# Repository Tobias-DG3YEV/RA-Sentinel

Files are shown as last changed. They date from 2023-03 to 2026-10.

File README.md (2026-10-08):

# Project RA-Sentinel - a Radio Access Sentinel
FPGA-based Radio Receiver for securing WiFi and other access points against hacking attacks.

RA-Sentinel is an open-source project focused on creating a cost-effective, small, and low-power wideband radio receiver device that employs an FPGA to automatically detect malicious attacks on WiFi access points, such as Man in the Middle and Denial of Service attacks. By monitoring any WiFi cell, the device enhances internet safety for everyday users.
The device features low-cost receive-only chips that digitize 40 MHz of the WiFi radio spectrum at 2.4 GHz. An FPGA extracts relevant properties from demodulated and decoded packets in real-time without storage. These properties are then processed by a neural network, also implemented on the FPGA, to determine if the traffic is genuine or an attack.

The project was later extended with a directional 4-channel RF front end (RASRF2400WBMC) that adds Angle of Arrival (AoA) estimation, see the Sub Projects section below.

## Funding
<p align="center">
  <a href="https://nlnet.nl/entrust/">NGI0 Entrust</a>
  &nbsp;&nbsp;
  <a href="https://nlnet.nl/project/RA-Sentinel/">NLnet</a>
</p>

**RA-Sentinel (main project)**

This project was funded through the [NGI0 Entrust](https://nlnet.nl/entrust) Fund, a fund established by [NLnet](https://nlnet.nl/) with financial support from the European Commission's [Next Generation Internet](https://ngi.eu/) programme, under the aegis of [DG Communications Networks, Content and Technology](https://commission.europa.eu/about-european-commission/departments-and-executive-agencies/communications-networks-content-and-technology_en) under grant agreement No 101069594.

**RASRF2400WBMC (directional / AoA extension)**

This sub-project was funded through the [NGI0 Commons Fund](https://nlnet.nl/commonsfund), a fund established by [NLnet](https://nlnet.nl/) with financial support from the European Commission's [Next Generation Internet](https://ngi.eu/) programme, under the aegis of [DG Communications Networks, Content and Technology](https://commission.europa.eu/about-european-commission/departments-and-executive-agencies/communications-networks-content-and-technology_en) under grant agreement No [101135429](https://cordis.europa.eu/project/id/101135429). Additional funding is made available by the [Swiss State Secretariat for Education, Research and Innovation](https://www.sbfi.admin.ch/sbfi/en/home.html) (SERI).

---

## Latest Updates 

| Date | Change | Link |
| --- | --- | --- |
| 2026-10-08 | Four-channel receiver: angle-of-arrival polar display, real-time phase comparison, IQ snapshot capture to a PC over gigabit Ethernet. FPGA1 now free of Xilinx IP (openCMUL, openCDIV, openFFT) | [/Documentation/iq_capture](./Documentation/iq_capture/README.md) |
| 2026-09-30 | RASBB Revision C manufacturing started | |
| 2026-07-24 | RASPMO - 4ch Spectrum Monitor/Phase analysis | [/RASPMO](./RASPMO) |
| 2026-06-30 | RASANT2400 - 2.4 GHz antenna for RF front ends | [/RASANT2400](./RASANT2400) |
| 2026-04-15 | RASRF2400WBMC - directional 4-channel RF front end for Angle-of-Arrival estimation | [/RASRF2400WBMC](./RASRF2400WBMC/README.md) |
| 2025-12-15 | RASBB_ECU firmware - adds UPNP discovery over Ethernet and a system configuration web page | [/RASBB/Software/RASBB_ECU](./RASBB/Software/RASBB_ECU) |
| 2025-02-23 | First boards of RASBB and RASRF2400WB received; bring-up ongoing | [RASBB README](./RASBB/README.md) &nbsp;\|&nbsp; [Findings Rev A](./RASBB/Findings_RevA.md) |

---

## System Architecture

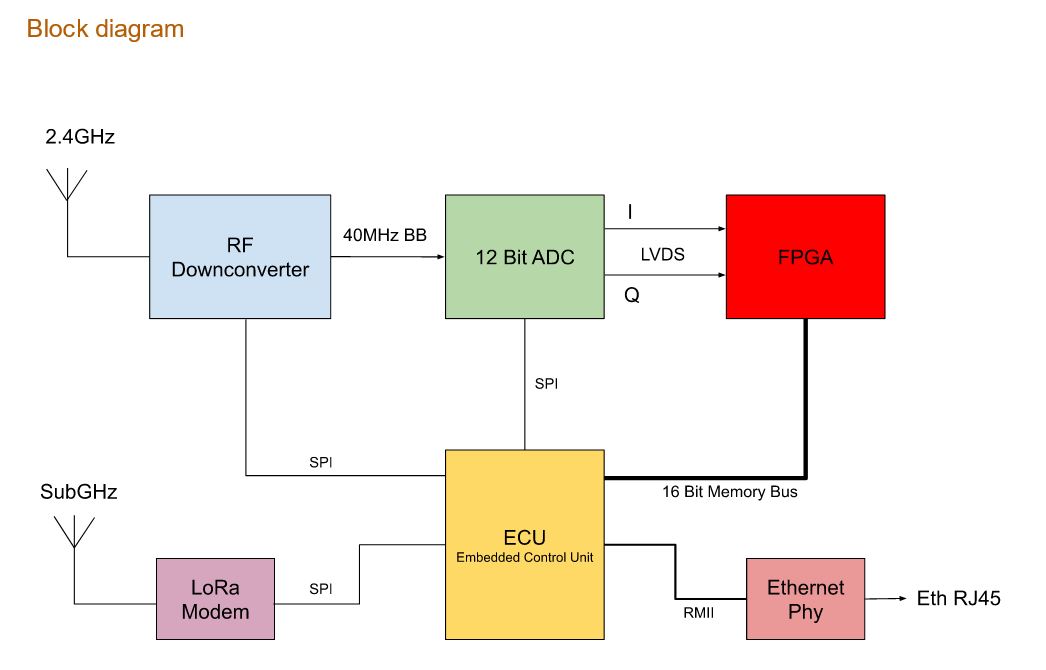
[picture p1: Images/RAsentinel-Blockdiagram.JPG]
RA-Sentinel Block Diagram


---
## Hardware

The hardware is a wideband SDR receiver that receives at least one complete WiFi Channel on the 2.4GHz ISM band with high resolution (12 Bits) to be able to detect smallest anomalies in a transmitted signal. The initial evaluation hardware consists of a Downcoverter/Transceiver Chip for 2.4GHz which is widely used in older WiFi Access Points (MAX2831). This is followed by a 12 Bit ADC (Texas Instruments ADC3222) which converts a 40MHz window of the 2.4GHZ radio spectrum into a 4 x 240 Bit/s LVDS streams (960kBit/s total) into a XILNIX/AMD Artix7 FPGA sitting on a evaluation board made by QMTECH. 

Based on the experience collected with first prototype, we designed a new SDR prototype. Two boards of the RASBB and the RASRF2400 have arrived on 23rd. Feb. 2025
Testing and bringing up is now ongoing. First results and findings can be found in the corresponding [Findings_RevA.md](./RASBB/Findings_RevA.md) documents.

### Boards

| Board | Description | Location |
|---|---|---|
| **RFFE2400WB** | 2.4 GHz PMOD-connected RF front-end evaluation board (used with QM-Tech Artix-7) | [/RFFE2400WB](./RFFE2400WB) |
| **RASBB** | Base-band board with STM32 ECU, web config, Ethernet/UPNP | [/RASBB](./RASBB) |
| **RASRF2400WB** | Wideband 2.4 GHz RF front end (production variant) | [/RASRF2400WB](./RASRF2400WB) |
| **RASRF2400WBMC** | Directional 4-channel phase-coherent front end (AoA) - *new sub-project* | [/RASRF2400WBMC](./RASRF2400WBMC) |
| **RASANT2400** | 2.4 GHz antenna for RF front ends| [/RASANT2400](./RASANT2400) |

First RA-Sentinel prototype with QM-Tech board
*Picture 1: First RA-Sentinel prototype based on the QM-Tech Artix-7 board and a newly designed RF front end connected via PMOD.*

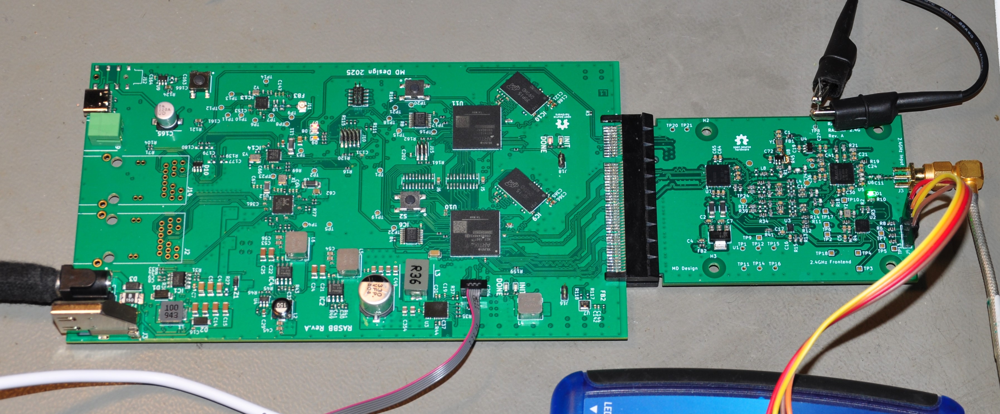
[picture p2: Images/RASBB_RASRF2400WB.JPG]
RA-Sentinel prototype Revision A

*Picture 2: RA-Sentinel prototype Revision A with RF front-end board RASRF2400WB.*

FPGA development board reference: <https://de.aliexpress.com/item/1005006473783593.html>

---

## Software / Firmware

The vast majority of the code will be written in Verilog and run on the FPGA. There is also now a firmware for the RASBB_ECU (Embedded Control Unit) and a"house keeping unit" microcontroller (STM32C031) which programms and controlling the frontend chips. The RASBB_ECU provides the interconnectivity. with other systems (alarm forwarding) and the web configuration interface. This firmware is written in C. 

The firmware for the RASBB_ECU can be found The firmware for the RASBB_ECU can be found [here](./RASBB/Software/RASBB_ECU). 

The RASBB_ECU Firmware for the onboard STM32 provides a versatile configuration interface with GUI that allows to show statistics and maybe UDP for analytic packets transfer and secure TCP/IP configuration over Ethernet.
To access this, enter the IP of the RAS into your local browser like http://192.168.0.2:4842/. The IP can be easily found via network environment because the RAS supports UPNP over ethernet.

All original software/firmware code written for this project is licensed under the GNU General Public License 3.0 (Only).

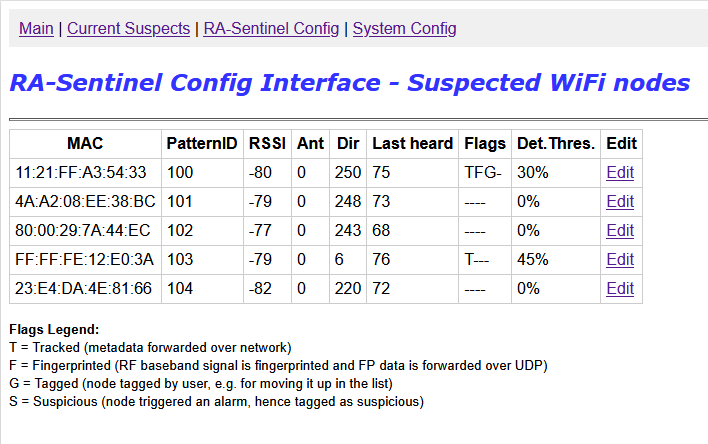
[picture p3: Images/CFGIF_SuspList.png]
WebInterface screenshot


A suspected WiFi node can be

* Tracked: Monitored by relative signal strength and later with additional direction. These values are forwarded to an IDS host that can combine this information with additional data retrieved from different RAS or other network monitoring systems.
* Tagged: Marked for internal memory, moving up in watch list.
* Fingerprinted: Raw IQ data of the frame start is forwarded to a fingerprinting algorithm.

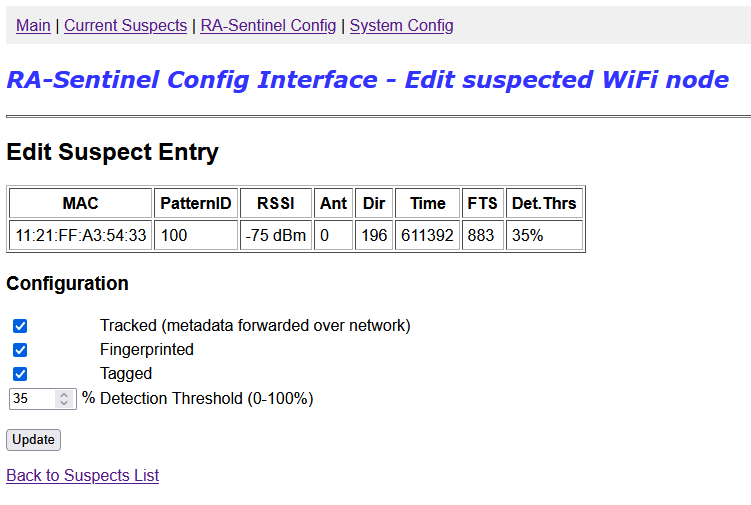
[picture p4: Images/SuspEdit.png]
Suspect Edit Screenshot


**UPNP support**

To ease the installation process, the RAS can be connected to any ethernet based LAN that provides an IPv4 DHCP server. Through the UPNP support, the RAS is easy to find in any network browser of Windows, Linux and Mac etc. 
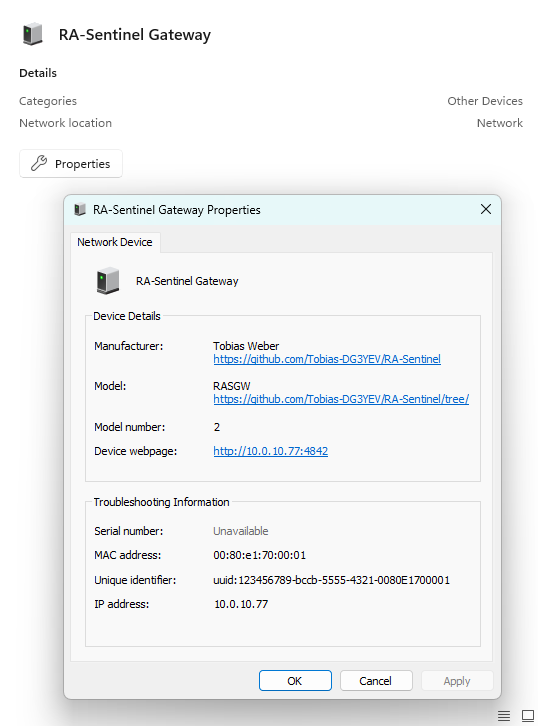
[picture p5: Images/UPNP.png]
UPNP Screenshot


---

## Sub Projects / Project Steps

The first step on this project was to have a reliable hardware basis. Initially I planned to have at least 40 Megasamples and with this 20 MHz bandwidth which is sufficient to capture the headers and the most common bandwidths used on 2.4 GHz WiFi (802.11a, b, g) communications channel. But because 802.11n also defines the possibility to use 40 MHz bandwidth, I wanted the possibility to cover the complete possible channel bandwidth. This has been achieved with the first prototype hardware and proved with the sub-project RASM2400, Radio Access Spectrum Monitor for 2400 MHz. The directional variant, RASRF2400WBMC, extends this base with multi-channel phase-coherent reception so the same signal can be received across several antennas and the direction of an attack can be estimated. You can find all sub-project details below.

### Sub project: RASRF2400WBMC - Directional RF Front End

The **RASRF2400WBMC** is a 4-channel, phase-coherent 2.4 GHz RF front-end board that extends RA-Sentinel with **Angle of Arrival (AoA)** estimation. By receiving the same signal across four spatially separated antennas, the system can estimate the physical direction of a detected attack - enabling threat localization for jamming, spoofing, and unauthorized events.

The board connects to the existing RASBB via the PCIe connector and requires no hardware changes to the base-band board.

See **[RASRF2400WBMC/README.md](./RASRF2400WBMC/README.md)** for full details.

### Sub project: RASM2400 - a spectrum monitor

RASM2400 stands for Radio Access Spectrum Monitor operationg on 2400MHZ. It offers a visual spectrum analyzer design that runs on the evaluation hardware set of RA-Sentinel the Artix7 XC7A100T Wukong board and the RFFE2400 front end board.
It shall proove that a 40MHz wide radio spectrum can be received and transported into the FPGA. Further, this project may already be usable for first RF forensics. Feel free to download all the stuff and build an RASM by yourself.

The following diagram shows the system architecture of the RASM2400.

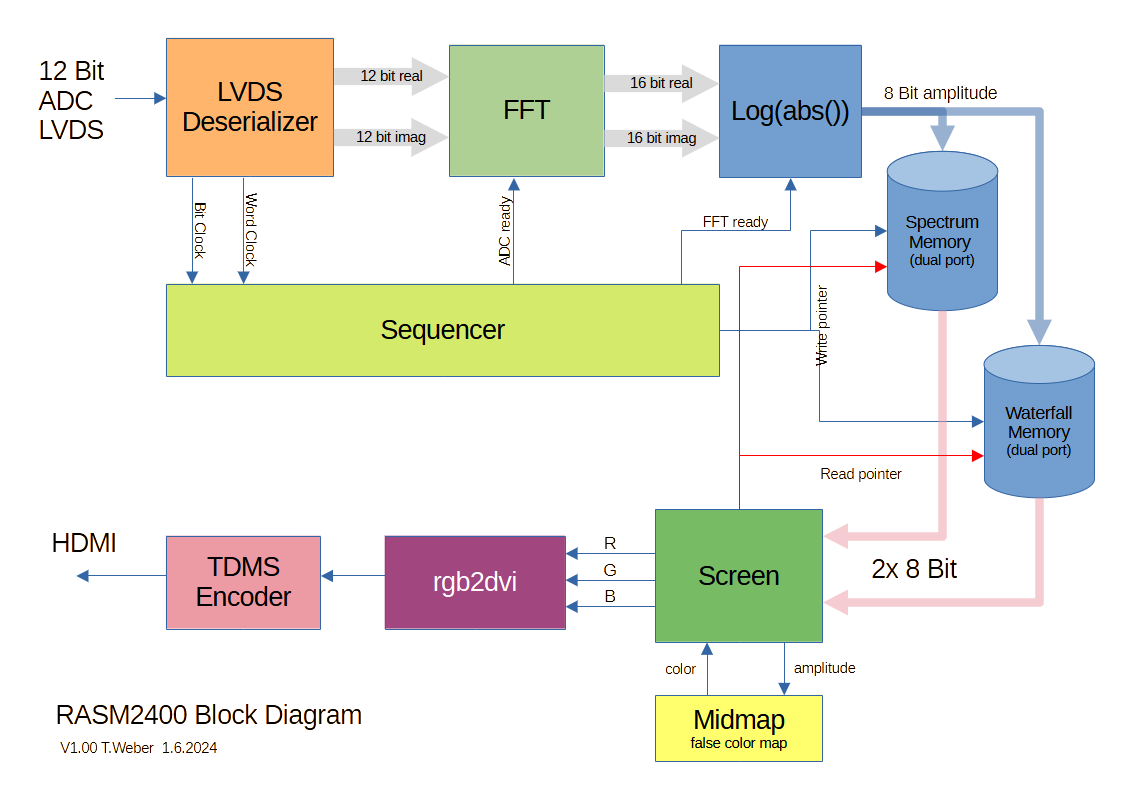
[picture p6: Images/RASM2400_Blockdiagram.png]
RASM2400 Block Diagram


The output of the HDMI port of the QMTECH Wukong board.

Screenshot of the RASM2400 HDMI output

Watch a short demonstration on Youtube by clicking on the thumbnail below.

Watch the video (https://youtu.be/tnwXk62DtHw)

#### Software

In this repository you'll find also all software paerts needed to get the project up and running.

**/RASM2400_Verilog**

This folder contains the Verilog source files as well as a ready to program bit stream file. 

**/RASM2400_HKU**

Here you find the firmware for the RF board housekeeping unit. It does not do much a the moment but initializing the Downconverter MAX2831 and the ADC3222. It is planned to receive commands via I2C to change basic parameters wil center frequency, sensitivity and AGC characteristics. This project can be compiled with arm-gcc or with the free available and Eclipse based development environment (IDE) from ST called "STM32CubeIDE". You can download this IDE from ST.com [https://www.st.com/en/development-tools/stm32cubeide.html]

**/RASPMO**

Radio Access Spectrum Monitor with HDMI Output. A firmware project for the analog processing FPGA (U10).
THis shows all four spectra of all four channels of the RASRF2400BMC front end on the HDMI output at 1080p60 resolution. It also can overlay a polar indicator that gices an coarse indication where the signal is comming from. 

#### Project update 13th Oct. 2024

The target of the next Milestone #2 was the „Identification and isolation of appropriate software components“ and also to „Additionally apply modifications to the openOFDMmodule to get extra meta data out of the frame demodulator to have a wider data basis for the later fingerprinting process.“

In the following points I describe how I achieved each step of this Milestone.

**1. compile/synthesize openWiFi on the target FPGA**

The code of openWiFi has been successfully ported from the project GitHub site [1] to the evaluation setup that I have designed and set up in the first Milestone. After gluing together the ADC LVDS deserializer block inside the FPGA with the parallel input of the openOFDM core, got rid of several timing constraint issues, I finally achieved to decode a WiFi Frame coming from an arbitrary signal generator. To accomplish this target, the code needed to be isolated from the original open WiFi demo project code. This original demo was based on SDR evaluation boards relying all on the AMD ZYNQ FPGA-ARM chip family. This family provides an FPGA part and an integrated ARM micro processor to which all communication of the FPGA part is connected to. Data from and to the integrated processor is exchanged through a common memory bus. This however is not working with my design idea which is based on a more powerful FPGA with an external ARM co-processor. I tried extracting the needed HDL (Verilog) parts and make this code running stand-alone. Finally I came the conclusion that only the project „openOFDM“ needs to be ported to my RA-Sentinel project hardware because the network layer and the transmit part implemented in openWiFi is not really needed by the RA-Sentinel project because there is no need in routing real data back and forth to a network. We are only interested in the lowest layer of a WiFi frame and its analog characteristics, not the routing of packets and also not in the frame containing payload as such.

First I adapted the test-bench provided in [2] for the Vivado simulation environment. To be able to simulate the complete RA-Sentinel hardware, I created a LVDS emulator that can stream artificial synthesized and recorded  RF data coming originally from the TI ADC 3221. After providing recorded RF data via this LVDS simulator and generating a appropriate, to the ADC phase-locked master clock of 100MHz to the openOFDM core and (see top_tb.v), this setup was able to decode a complete 802.11a/g frame in the AMD Vivado simulator. It took me quite some fiddling and playing with timings and implementation settings of the tool-chain to finally get it running properly on my own hardware. (AMD Artix7 development board my QM-Tech and my 2.4GHz ADC board designed in Milestone 1)

**2. Strip down openWiFi and open OFDM to the receive part**

First this was regarded as an easy task but as deeper I dived into the code  by the original author of the two projects, the more I realized the code provides almost no comments and wire and register definitions are quite ambiguous and non-intuitive. In my opinion the code needed desperately a rework to be better understandable which would also lead to a lower learning curve for others also trying to implement and adapt the existing code base to their needs. Two major things I tried improving with my fork of openOFDM: The introduction of directional prefixes for module ports. I have seen such in the code of another NLnet founded guy called Dan Nissselquist. Adding the prefix  „i_“ to  input ports (defined as wires/registers in Verilog) and „o_“ to the port definition makes it IMHO much easier when browsing through the code, allowing to instantly realize which wire or register is being exported from this current module and which is only a local element. I added these prefixes all over the code of openOFDM. See my fork of openOFDM on GitHub [1] for details. The next thing I found hard to understand, was the use of the ever repeating word „sample“ for all data along the signal path, from the input of the openOFDM core (ADC base-band data) up to near the exit (decoded data bytes). As there is a switch from time domain (endless sample stream) into frequency domain (blocks of 64 frequency bands) in the module „sync_long“, I changed the name of all wires and registers after this module and renamed them into „spectrum“.  Also some comments were added to clarify what a wire or register is doing at a certain point. This work is not yet regarded as being completed. Each time I dig into the original code, I will add comments and try to make the code more „barrier free“.

**3. Create a new fork of openOFDM**

This has been done and the new fork of openOFDm can be found here:

[1] https://github.com/Tobias-DG3YEV/openofdm

It contains comments and my code changes proposed earlier in this document.

**4. Try adding additional meta date stubs**

As I tried figuring out which meta data could be used to distinguish between  genuine transmitting device and a counterfeit device, I found an article at mathworks.com [3] reporting that they proved finding counterfeit, evil twins of a WiFi Access Point by feeding the raw sampled channel data of a transmission into a ML algorithm. For this purpose they followed a kind of a brute force approach by taking all samples of a received frame into account and fed into a ML algorithm. Even the smallest frame like an information or flow control frame that is only 100uS of duration will produce 16kBytes of data which is rather huge. This amount of data may be processable - if the SDR is directly connected to a powerful computer with multiple cores etc. The project RA-Sentinel does not follow this kind of big processing power approach. Amplitude, phase and frequency change due to several effects during the transmission of a frame, but all of these changes always result in a phase shift. So I thought, in  the first attempt identifying a WiFi transmitting device by characterizing (or say learning) the phase deviation over time may be sufficient. Because the RF receiver front end of the RA-Sentinel project has a low noise and high stability master clock (a 40MHz TXCO by Abracom) that is multiple times more accurate that standard commercial WiFi transmitters, I hope that a small amount of phase shift data received in the beginning of a WiFi frame may be enough to clearly identify counterfeit devices. 

**5. Redefine a new simplified interface to access meta parameters**

One thing I have learned throughout the project progress so far, is that even many may say that an FPGA is one of the most versatile digital programmable devices available today, allowing the implementation of any kind of parallel and sequential tasks up to integration of soft-core processors the fact is that all this integrated logic leads to a rather time consuming iterative development process. To optimize WiFi data reception on one side and to interpret and forward meta data on the other side all inside the FPGA leads to an extremely slow and challenging development process. For the analysis of meta data, an external, traditional single chip microprocessor running straight C/C++ code,  offers much more opportunities and most importantly, allows much a faster  development progress. Bit for that, I need a fast and reliable interconnection between the FPGA and the micro processor.

I identified and implemented two interfaces which allow to access 

The first interface I implemented into the FPGA was the SPI slave interface. This interface allows reading and writing 32 wide registers inside the FPGA by an external micro controller (in this case, I use a STM32H743 Cortex-M7)

The SPI interface allows access to the following parameters:

- Receiver characteristics like receiver center frequency, gain, power threshold, max. error rate etc.

- reading current receiver parameters like noise level, signal to noise ratio etc.

Further I needed an interface that is capable transferring header and  metadata that is produced with each WiFi 802.11 frame received to my  external ARM processor. As I cannot foresee at this point in the project how much meta data is needed to distinctly identify a sender hardware of a frame, I was looking for a method to reliably transport greater chunks of data from the FPGA directly into the memory of the external micro-controller without code intervention. Hence, I started evaluating the possibilities based on the peripheral capabilities of the STM32 device family.  After I had invested some effort into research and experiments, I found that SPI especially in a 4-Bit configuration might feasible as it is able transporting 25MByte/s. But the digital camera interface (DCMI) that many of those top range micro-controllers provide, offer 8 Bit parallel data transfer directly into the controller’s memory via DMA at a maximum rate of 80MBytes/s.

So the next step was to design a logic circuit into the FPGA that can mimic the signaling of a digital camera module with DCMI interface. This has been implemented on both sides, the FPGA in Verilog Code and on the STM32H7 in C language. 

The received 802.11 frame info packet that is streamed upon each complete frame reception has the following format:

---

**Resources:**

[1] https://github.com/open-sdr/openWiFi-hw/

[2] https://github.com/Tobias-DG3YEV/openofdm

[3] https://de.mathworks.com/help/comm/ug/design-a-deep-neural-network-with-simulated-data-to-detect-wlan-router-impersonation.html

Project Maintainer: Tobias Weber, Mina Daneshpajouh

Last updated: 17. May. 2026

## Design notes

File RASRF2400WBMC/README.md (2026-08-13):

# RASRF2400WBMC - 4-Channel Directional RF Front End

## Licensing
Licensed under **CERN-OHL-S**. See [LICENSE.HW.TXT](LICENSE.HW.TXT) for details.
## Overview

The **RASRF2400WBMC** is a 4-channel, 2.4 GHz RF front-end board designed as a directional extension to the RA-Sentinel WiFi intrusion detection system. While the single-channel RASRF2400WB board can detect malicious WiFi attacks, this board adds the ability to determine the **direction from which an attack originates**.

By receiving the same signal across four spatially separated antennas in a phase-coherent manner, the system can estimate the **Angle of Arrival (AoA)** of incoming RF signals. This enables **threat localization** - helping to physically identify and locate sources of jamming, spoofing, Man-in-the-Middle, or Denial of Service attacks.

This board connects to the existing [RASBB](https://github.com/MinDans/RA-Sentinel/tree/main/RASBB) (RA-Sentinel Base Band Board) via a PCIe connector, making use of its multiple ADC input lines without requiring any changes to the base band hardware.

---

## System Architecture

```
ANT 1 --+
ANT 2 --+--[ 4x MAX2831 ]-[ I/Q analog ]-[ ADC3424 #1 ]-[ LVDS D0 ]-|
ANT 3 --+                                  [ ADC3424 #2 ]-[ LVDS D0 ]-|-[ PCIe ] -> RASBB
ANT 4 --+
```

All four channels are **phase-coherent**, meaning the RASBB can compare the phase difference between channels to compute the Angle of Arrival of a detected signal.

---

## Hardware Specifications

| Parameter | Value |
|---|---|
| Frequency | 2.4 GHz ISM band |
| Number of channels | 4 (phase-coherent) |
| Transceiver | Maxim MAX2831 (x4) |
| Digitization | TI ADC3424 x2 - 6-bit eff. - 40 MSPS |
| Interface to RASBB | PCIe connector |
| Antenna | [RASANT2400](https://github.com/MinDans/RA-Sentinel/tree/main/RASANT2400/Hardware/KiCad) |
| Primary function | Angle of Arrival (AoA) estimation |
| Status | Sent for manufacturing - not yet delivered |

---

## Repository Structure

```
RASRF2400WBMC/
+-- README.md                          This file
+-- Hardware/
|   +-- KiCad/                         Source design files
|   |   +-- RASRF2400WBMC.kicad_pro
|   |   +-- RASRF2400WBMC.kicad_sch
|   |   +-- RASRF2400WBMC.kicad_pcb
|   |   +-- Libraries/
|   |       +-- Footprints/           KiCad footprints
|   |       +-- Symbols/              KiCad symbols
|   +-- Production/
|       +-- RevA.0/                   Manufacturing outputs for Revision A.0
|           +-- Gerbers/              Gerber + drill files (.gbr, .drl)
|           +-- PickAndPlace/         Component placement files (.csv)
|           +-- BoM/                  Bill of Materials (.csv)
+-- Images/                           Board renders, photos, block diagrams
+-- Docs/
    +-- Design_Notes.md               Design decisions, antenna spacing, AoA theory
```

---

## Relationship to Other RA-Sentinel Boards

| Board | Antennas | Purpose | Interface |
|---|---|---|---|
| [RASRF2400WB](https://github.com/MinDans/RA-Sentinel/tree/main/RASRF2400WB) | 1 | Wideband detection | PCIe -> RASBB |
| [RASRF2400WBMC](https://github.com/MinDans/RA-Sentinel/tree/main/RASRF2400WBMC) | 4 | Detection + direction finding | PCIe -> RASBB |
| [RASBB](https://github.com/MinDans/RA-Sentinel/tree/main/RASBB) | - | Base band processing (shared) | - |
| [RASANT2400](https://github.com/MinDans/RA-Sentinel/tree/main/RASANT2400/Hardware/KiCad) | - | 2.4 GHz antenna for RF front ends | - |

Both RF front-end boards are designed to work with the same RASBB.

---

## Status

>  The PCBA has been received and the initial tests show successful results. A bring-up log has been added to  [/Docs/](Docs/StartupTestReport_RevA.md).

---

## Funding

This project was funded through the **NGI0 Commons Fund**, a fund established by NLnet with financial support from the European Commission's Next Generation Internet programme, under the aegis of DG Communications Networks, Content and Technology under grant agreement No 101135429. Additional funding is made available by the Swiss State Secretariat for Education, Research and Innovation (SERI).

<a href="https://nlnet.nl/commonsfund/">NGI0 Commons Fund</a>
<a href="https://nlnet.nl/project/RA-Sentinel-directional/">NLnet</a>

---

## Project Maintainer

Mina Daneshpajouh, Tobias Weber

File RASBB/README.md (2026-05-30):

# RA-Sentinel System Overview

The **RA-Sentinel** system consists of two main boards that work together to enable high-performance RF signal reception, digitization, and processing.

The hardware design is licensed under **CERN-OHL-S**. See LICENSE.TXT for details.

## RA-Sentinel Radio Front-End Board (RASRF)
The **RASRF** board is responsible for receiving and conditioning, and digitizing RF signals before transmitting them to the baseband processor.
 - The antenna is connected through a Balun to an RF front-end transceiver, which performs signal reception, downconversion, and filtering.
 - The downconverted signal is then conditioned using a driver circuit optimized for impedance matching and signal integrity.
 - A high-speed 12-bit ADC samples a 40 MHz portion of the 2.4 GHz radio spectrum, converting it into a 960 Mbit/s data stream (2 channels: I+Q, 12-bit each @ 40 
   MSPS). 
 - The digitized data is transmitted over a PCIe interface to the RASBB board for baseband processing.

## RA-Sentinel Baseband Board (RASBB)
The **RASBB** board processes the received digital RF data and manages higher-layer communication.
 - It performs baseband signal processing, extracting relevant information from the digitized RF data.
 - It transitions the processed data from OSI Layer 1 (Physical) to OSI Layer 2 (Data Link) for further communication and protocol handling.
 - The board integrates additional processing units and interfaces for system-level control, data management, and external communication.

Together, the **RASRF** and **RASBB** boards create a scalable, high-performance platform for RF signal acquisition and real-time processing.

Below is the block diagram illustrating the architecture of both boards and their interconnections:

<p align="center">
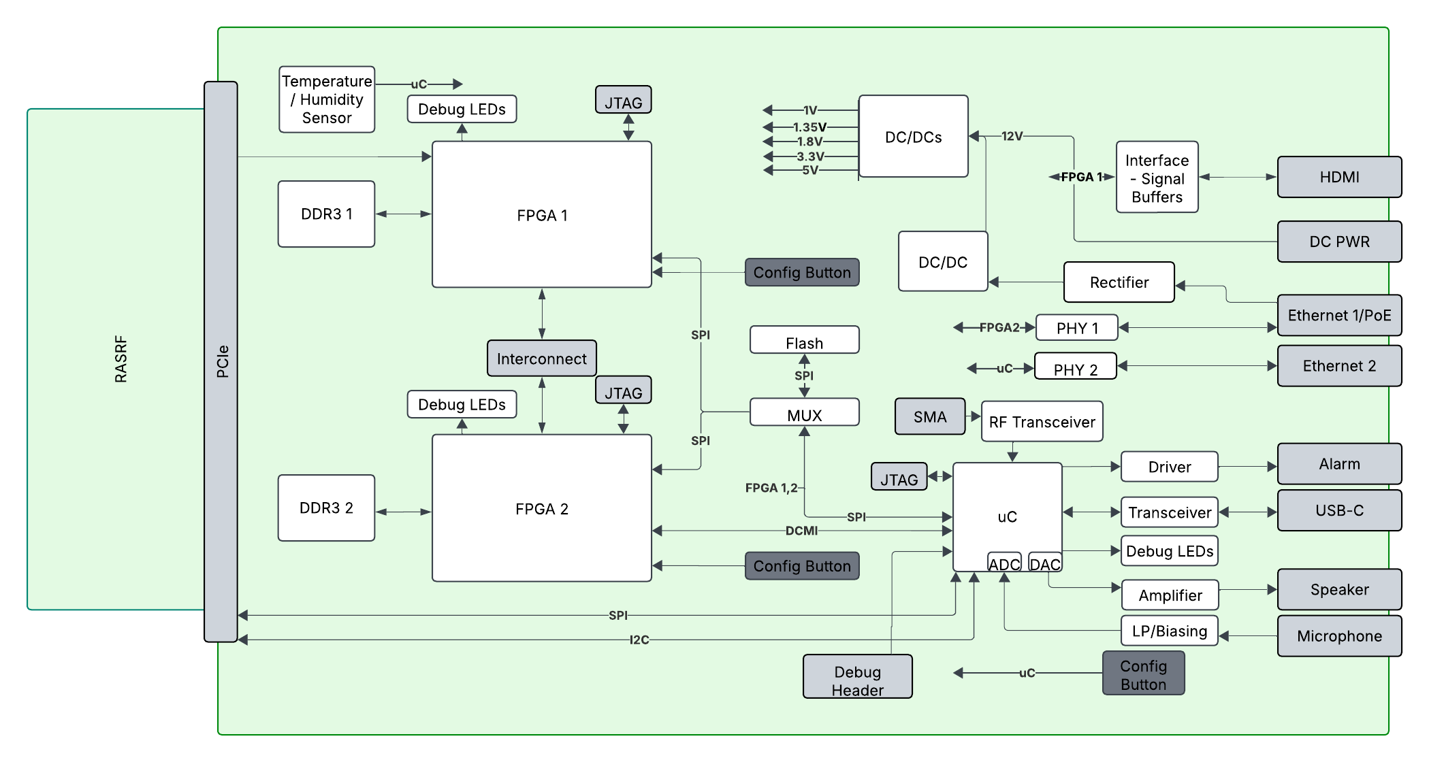
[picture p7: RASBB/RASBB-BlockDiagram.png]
RASBB block diagram
  
  <br>
  <em>RASBB block diagram</em>
</p>

<p align="center">
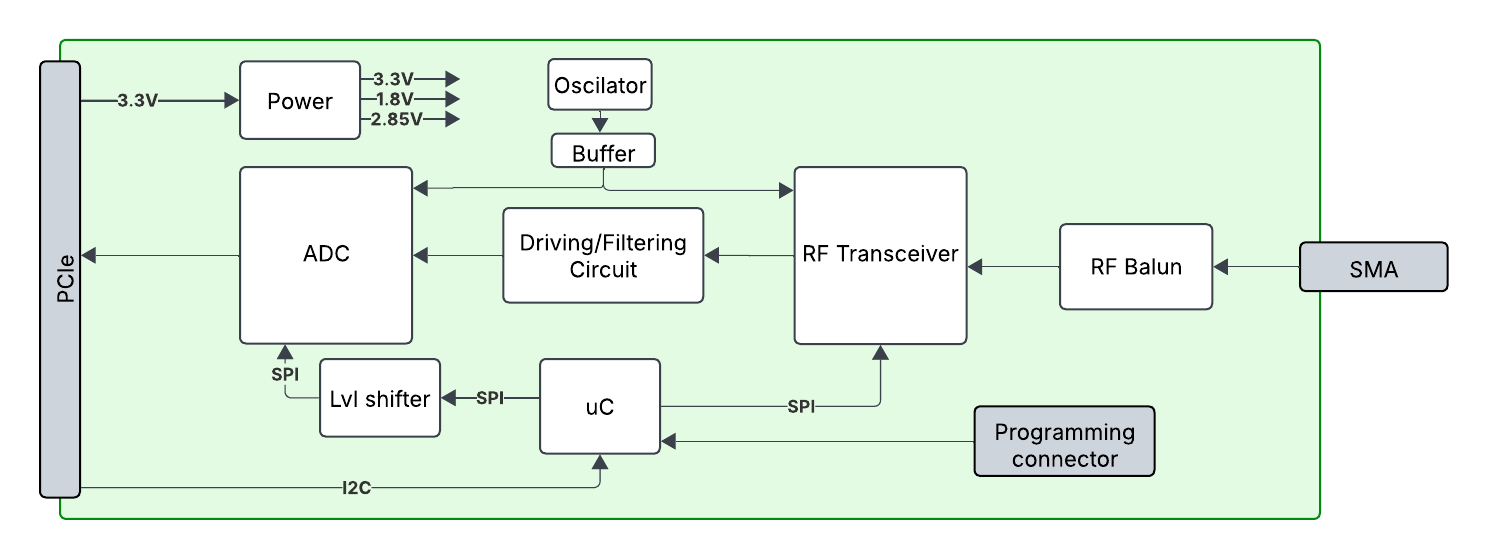
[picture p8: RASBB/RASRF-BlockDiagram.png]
RASRF block diagram
  
  <br>
  <em>RASRF block diagram</em>
</p>

## The hardware

The PCB of the RASBB is constructed from an FR4 eight-layer PCB, which contains several processing units, sensors, and radio and wired interfaces.
Below is a list of its features:

- Two Artix-7 FPGAs with 100k Logic Elements each
- 4 Gigabit (512MB with 16-bit access) Low Voltage DDR3 RAM
- STM32H7 high-performance (up to 480MHz) ARM Cortex-M7 microcontroller
- x8 PCI Express slot
- HDMI port, with video generated in FPGA 1
- 40-bit (32+8) inter-processor communication bridge (accessible by external logic analyzers)
- Two separately usable 16M Flash chips for FPGA configuration, accessible by both FPGA and STM32
- Temperature and humidity sensor for physical environment supervision
- Audio DAC with a 1W output amplifier (for alarm and voice output)
- Audio ADC for capacitive microphone connection (for acoustic environment surveillance)
- Open-collector 30V/1A capable switching output (for alarming devices)
- USB-C port with virtual COM port support for debugging and updates
- 2.4GHz LoRaWAN™ modem chip for robust alarm distribution
- 100Mbit/s Ethernet port connected to the STM32H7 MCU
- 1Gbit/s Ethernet port connected to FPGA 2
- Power over Ethernet (PoE) Type 1 with a maximum power of 13W
- LEDs for indication
- Configuration button
- FPGAs and STM32 accessible through JTAG port

*The RA-Sentinel Baseband Board design will fit into a 100mm extrusion enclosure.* 

<p align="center">
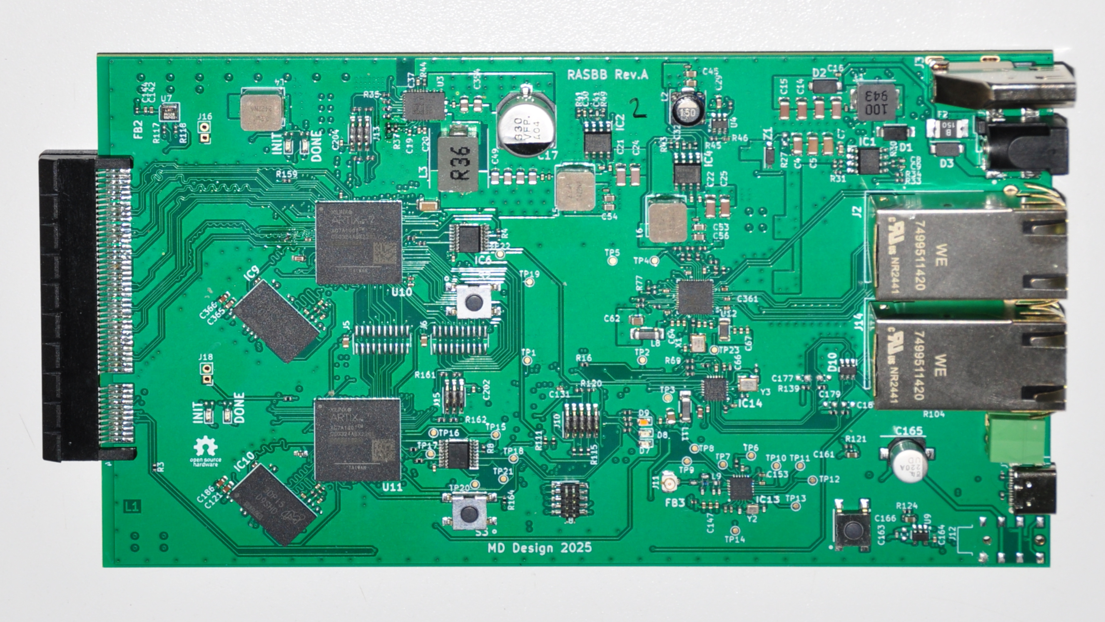
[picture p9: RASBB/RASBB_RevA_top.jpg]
RASBB Rev A — top view
  
  &nbsp;&nbsp;
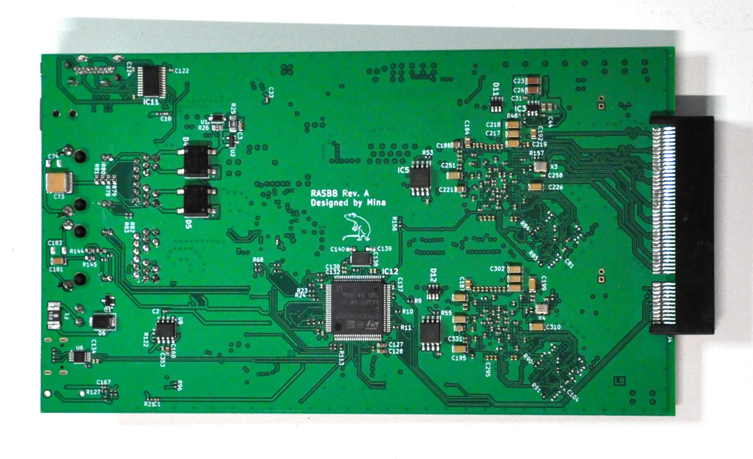
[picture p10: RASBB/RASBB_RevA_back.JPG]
RASBB Rev A — bottom view
  
  <br>
  <em>RASBB Rev A - top &nbsp;&nbsp;|&nbsp;&nbsp; bottom</em>
</p>

The PCB of the RASRF is constructed from an FR4 Four-layer PCB, which contains  processing unit, RF-transmitter, and an Analoge/to/Digital converter.

<p align="center">
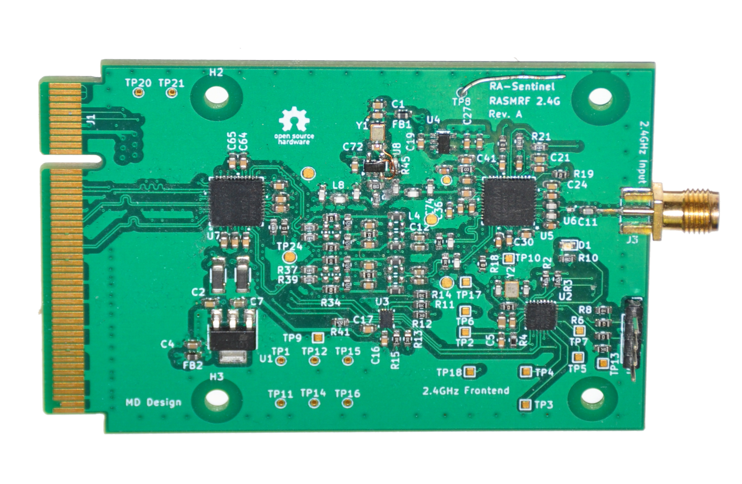
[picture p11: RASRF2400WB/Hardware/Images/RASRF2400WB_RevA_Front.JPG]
RASRF2400WB Rev A — top view
  
  &nbsp;&nbsp;
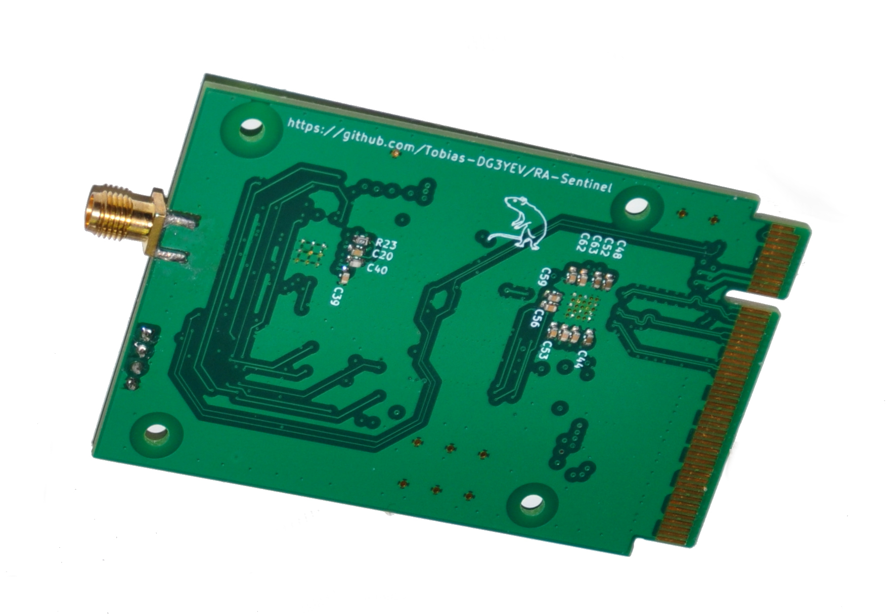
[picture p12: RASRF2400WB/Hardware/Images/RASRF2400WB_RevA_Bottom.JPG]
RASRF2400WB Rev A — bottom view
  
  <br>
  <em>RASBB Rev A - top &nbsp;&nbsp;|&nbsp;&nbsp; bottom</em>
</p>

---

*Hardware design: Mina Daneshpajouh*
*Firmware / signal processing: Tobias Weber*

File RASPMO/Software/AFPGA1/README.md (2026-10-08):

# RASPMO — Radio Access Spectrum Monitor

RASPMO is an FPGA design (Artix-7 XC7A100T, Vivado/Verilog) that turns the
RA-Sentinel hardware into a standalone four-channel 2.4 GHz spectrum monitor
with a live HDMI display — no PC or host software involved.

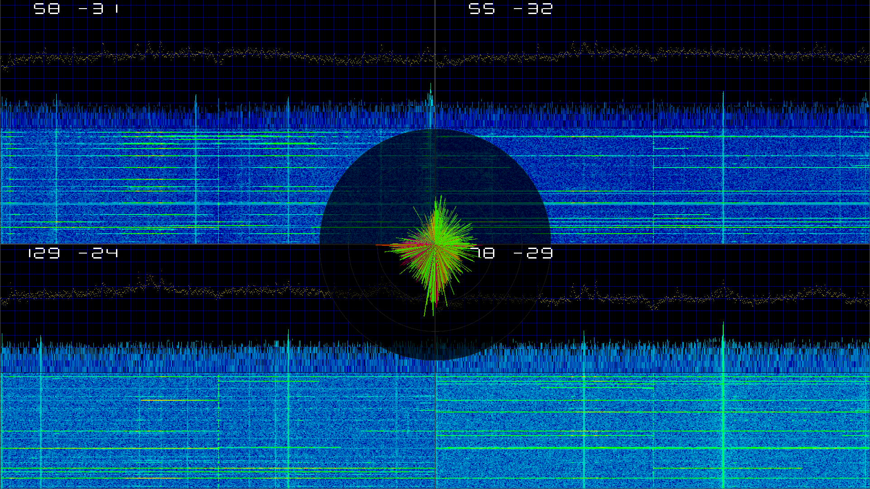
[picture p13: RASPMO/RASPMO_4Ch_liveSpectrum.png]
RASPMO doing 4 channel live spetrum anlysis

See it live in action on [youtube](https://www.youtube.com/watch?v=SnHPaw8y9vc)

## What it does

The RF front-end board (RASRF receives four independent 2.4 GHz channels (via four
MAX2831 zero-IF transceivers); two TI ADC3424 quad ADCs digitize the four I/Q
baseband pairs at 12 bit / 20 MSPS and ship them to the FPGA as eight
one-wire LVDS lanes. RASPMO deserializes the lanes with a self-calibrating
link (per-ADC IDELAY tap sweep plus per-lane word alignment, trained against
the ADC's built-in ramp test pattern at startup), removes the DC/zero-IF
offset, and runs a single 1024-point complex FFT time-multiplexed round-robin
across the four channels — each channel's spectrum updates at ~4.9 kHz, far
above the display rate.

## Display

Output is 1080p HDMI, split into four 960×540 panes, one per receive channel.
Each pane shows the two-sided (complex) spectrum with a scrolling waterfall
below it, plus a readout of the averaged signal level in ADC absolute values and dBFS.
(dB from full scale away)
The vertical graticule is labelled in MHz offset from the tuned centre, derived
from the `FS_HZ` parameter in `top.v` — the complex ADC word rate, 125 MSPS, so
the transform spans −62.5 … +62.5 MHz. Every second grid line carries a label,
one every FS/16 = 7.8125 MHz, giving fifteen of them from −54.7 to +54.7 MHz
across the 960 of 1024 bins a pane actually shows. Change `FS_HZ` and the whole
scale re-labels itself; nothing else in the design reads it. `LABEL_DIV` sets
the density (8 for half as many) and `GLYPH_SCALE` the text size.
Right over the centre of the four panes sits a polar direction-finding
indicator driven by amplitude comparison between the channels. An optional
build switch (`SHOW_BER_RATES`) overlays per-lane bit-error counters for link
verification while the front-end runs its ADC ramp-test firmware.

## Hardware

RASPMO runs on the RA-Sentinel board set:

- **[RASBB](https://github.com/Tobias-DG3YEV/RA-Sentinel/tree/main/RASBB)** —
  baseband board carrying the Artix-7 FPGAs, HDMI output and the PCIe-style
  socket for the front-end card. RASPMO targets FPGA 1 (XC7A100T-CSG324).
- **[RASRF2400WBMC](https://github.com/Tobias-DG3YEV/RA-Sentinel/tree/main/RASRF2400WBMC)** —
  four-channel 2.4 GHz receiver front-end (4× MAX2831, 2× ADC3424, 40 MHz
  TCXO clocking, STM32C031 board controller that configures the RF chain).

## Building

`create_project.tcl` recreates the Vivado project from `RASPMO.srcs/`;
`top.mcs` is the flash image for the on-board configuration memory.

License: GNU GPL v3, © 2026 Tobias Weber. Part of the
[RA-Sentinel](https://github.com/Tobias-DG3YEV/RA-Sentinel) project.

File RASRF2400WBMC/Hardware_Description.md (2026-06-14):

# RASRF2400WBMC - Hardware Description

## What this board does

The RASRF2400WBMC is the RF front end for the directional extension of RA-Sentinel. Where the original single-channel board can tell you *that* a WiFi attack is happening, this one can tell you *where it's coming from*. It does that by receiving the same signal on four separate antennas simultaneously and measuring the phase difference between channels - from which the RASBB can calculate the Angle of Arrival (AoA).

The board was designed to plug into the same PCIe slot as the single-channel RASRF_2400WB. No changes to the RASBB are needed; the baseboard already has enough ADC inputs and the FPGA handles the rest.

---

## Signal chain

Four antennas connect through balun transformers (HHM1902B1) directly into four MAX2831 transceivers. The MAX2831 is a direct-conversion 2.4 GHz chip - it downconverts the incoming signal to baseband I/Q, which comes out as a differential analog signal. Those analog outputs feed two ADC3424 converters (Texas Instruments, 12-bit capable - **6-bit effective**, quad-channel, 40 MSPS). Only the D0 LVDS output pairs are connected; D1 pairs are left unconnected. Each ADC handles two channels (I+Q each), so ADC #1 digitises CH1 and CH2, and ADC #2 handles CH3 and CH4. The resulting LVDS streams go through the PCIe connector to the RASBB, where the FPGA picks them up.

Total digital data rate: four channels x 6-bit I/Q x 40 MSPS = ~ 1.92 Gbit/s.

```
ANT 1 --+
ANT 2 --+--[ 4x MAX2831 ]-[ I/Q analog ]-[ ADC3424 #1 ]-[ LVDS D0 ]-|
ANT 3 --+                                  [ ADC3424 #2 ]-[ LVDS D0 ]-|-[ PCIe ] -> RASBB
ANT 4 --+                                                              +
```

---

## Clock distribution

Phase coherence across the four channels depends entirely on all four MAX2831 chips and both ADCs sharing a single reference clock. A 5PB1206NDGK8 clock fanout buffer takes the 40 MHz reference from an onboard TCXO and distributes it to six outputs: one per MAX2831 and one per ADC. PCB trace lengths from the fanout to each chip are matched.

---

## Housekeeping MCU

A STM32C031K6U6 manages startup and configuration. It talks to all four MAX2831 chips and both ADC3424s over a shared SPI bus, with individual chip selects per device. A level shifter (SN74AXC4T774RSVR) handles the voltage translation between the STM32 and the ADCs SPIs pins. The STM32 also has an I2C interface connected to the RASBB, so the RASBB can send configuration commands or read status without the STM32 needing a standalone firmware update for each parameter change.

---

## Power supply

The board takes 3.3 V from the PCIe connector and generates the additional rails locally:

- **1.8 V** - LD1117 LDO, for the ADC3424 core supply
- **3 V** - ADP7154 LDO, for the MAX2831 supply rails

---

## Key components

| Part | Function |
|---|---|
| Maxim MAX2831 x4 | 2.4 GHz direct-conversion transceiver, RX only in this design |
| TI ADC3424 x2 | 12-bit capable (6-bit effective, D0 only), quad-channel ADC, 40 MSPS, LVDS output |
| 5PB1206NDGK8 | 6-output clock fanout buffer, drives all four transceivers and both ADCs |
| STM32C031K6U6 | Housekeeping MCU - SPI config, I2C to RASBB |
| SN74AXC4T774RSVR | 4-bit dual-supply level shifter (3.3 V <-> 1.8 V) |
| HHM1902B1 x4 | 2.4 GHz balun, single-ended to differential conversion at antenna input |
| LD1117DT18  | 1.8 V LDO regulator |
| ADP7156ACPZ-3.0-R7 | Adjustable LDO, set to 3V |

---

## Block diagram
Block Diagram

---

## PCBA
<div align="center">
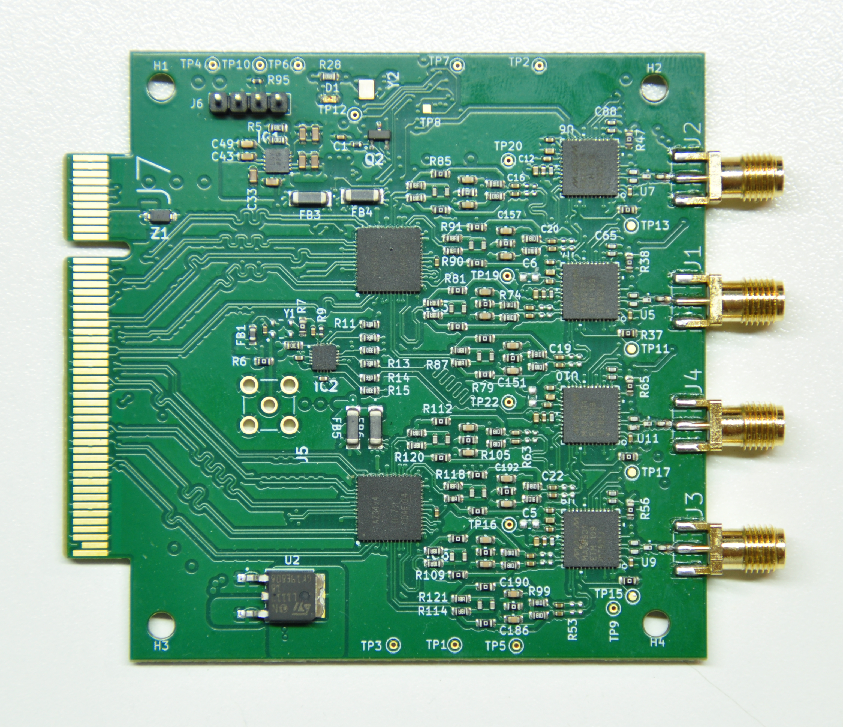
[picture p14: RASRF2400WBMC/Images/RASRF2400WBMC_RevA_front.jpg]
  
  <br><em>RASRF2400WBMC Top-side</em>
  <br><br>
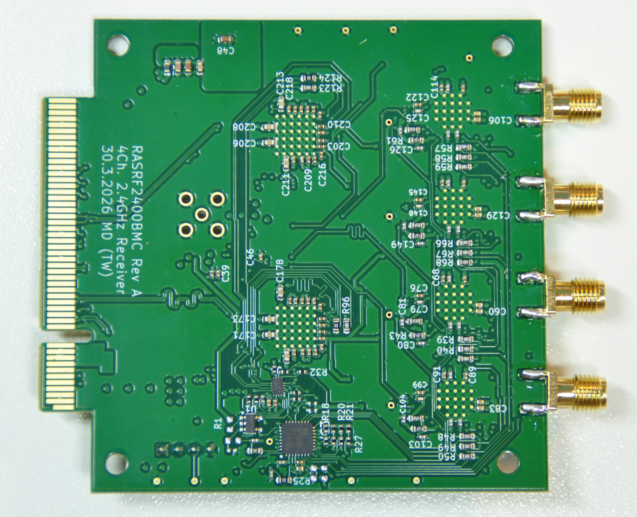
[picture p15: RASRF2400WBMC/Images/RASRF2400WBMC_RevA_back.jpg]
  
  <br><em>RASRF2400WBMC Bottom-side</em>
</div>

---

## Design notes

See [Design Notes](https://github.com/MinDans/RA-Sentinel/blob/main/RASRF2400WBMC/Docs/Design_Notes.md) for antenna spacing derivation, AoA algorithm selection, phase coherence strategy, and the open questions list being worked through during the design phase.

---

*Hardware design: Mina Daneshpajouh*
*Firmware / signal processing: Tobias Weber*

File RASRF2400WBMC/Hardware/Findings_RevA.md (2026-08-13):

## Errors, Issues and improvements found in RASBB PCB design revision A.

| ID 	| State 	| Description 	 | Solution |
|----	|---	|---	 |--- |
| 1  	| open  | Silkscreen misses ADC designators | add  |
| 2  	| open  | 10 kΩ pull-up from ADC1_CS to +1V8, mirroring R125 on ADC2_CS. | add |
| 3  	| open  | Pull resistors on SPI_SCLK / SPI_MOSI at U3's A-side — AXC inputs must not float, and there are none today. | add |
| 4  	| open  | Wire IC5/IC6 pin 24 (RESET) to spare STM32 GPIOs; optionally pin 37 (PDN) as well. | add |
| 5  	| open  | Add ferrite bead and decoupling C at the input of 3.3V to suppress 1.8MHz spurious signal | add |
| 6  	| open  | Add opening in solder mask at a PCB corner to allow connecting debug ground clamps | add |
| *7  	| open  | Replace the two 4 channel ADCs with one 8 channel ADC to have better phase alignement between all channels | exchange |
| **8 | open  | Replace MAX2831 should be exchange with MAX2837| exchange |
| 9 | open  | Add Tx capabilites to one MAX. With this reference signal it produces, we can calibrate amplitudes between channels. Highest accuracy is needed for AOA. | add |
| 10  | open  | Add RF switch in front of each MAX RF input to make it switchable to the reference signal | add |
| 11  | open  | Add additional DAC including LVDS wiring to FPGA for MAX test signal generator facility | add |

\* Items 7 and 8 are not cosmetic fixes like 1 to 6. Both came out of chasing phase
errors that would not calibrate away. Neither can be fixed by adding a component,
the parts themselves have to change.

## Findings behind items 7 and 8

### 7. Two ADC3424 -> one 8 channel ADC

Issue: two converters mean two clock paths and two LVDS links to length match, and
two startup alignments that both have to come up correctly. On top of that,
channels on the same chip match well and drift together, while channels on two
separate chips only match within the datasheet range, and that gap moves with
temperature.

Solution: one 8 channel converter. All eight channels sit on one die, in a single
timing and alignment domain. That removes an inter device calibration term and
halves the capture logic.

### 8. MAX2831 -> MAX2837

Issue: the MAX2831 leaves the PLL's most noise sensitive node unshielded, so
supply and neighbouring channel noise reaches it. Each channel has its own PLL, so
this noise is independent per channel and does not cancel when we compare phase
between antennas. It goes straight into the bearing as jitter, and the coupling is
inside the chip, so nothing on the board fixes it. The MAX2831 is also write only,
so with four chips that must be set identically we cannot confirm that they are.

Solution: MAX2837. Balanced wiring shields that node, and SPI readback lets us
verify all four chips.

### 9 to 11. Received signal amplitude improvement

Issue: The MAX sensitivity and amplification varies over its channels. 
With this effect, an estimation of bearing foa WiFi node is difficult
based on received signal amplitude. We need that function as a complement and
fallback for phase AOA detection. 

Technical details: It looks like it has a class C amplifier and as we know, the bias current is sensitive for drift
over temperature. There might me a correction circuit inside the MAX but that is not doing
well. We hope to get better reception results with the MAX2837.
The variation is also caused by internal part tolerances amplified by different temperatures
we have at different board areas. To calibrate this away,
we need a reference signal. As the MAX family aready contains a complete 2.4GHz tranceiver,
it makes sense to make this assiable to all 4 input channels through tiny RF switches.
With a reference level transmitted from one max at different levels, we can also calibrate away non-linearities
in the amplification of the complete Rx path.

Solution: Add Tx and switching matrix capabilites to MAX tranceiver chip.

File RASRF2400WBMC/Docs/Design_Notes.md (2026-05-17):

# 

>  This document is a living record of design decisions made during development. It will be updated as the design matures and bring-up begins.

---

## 1. Motivation and Design Goals

The single-channel RASRF2400WB board can detect the presence a WiFi attack (e.g. jamming, spoofing), but cannot determine where the attacker is physically located. In dense environments - offices, apartment buildings, public venues - this limits the usefulness of the detection: an alert without a direction is difficult to act on.

The RASRF2400WBMC adds a spatial dimension to RA-Sentinel's detection capability by implementing a 4-element antenna array with phase-coherent reception. From the phase differences measured across channels, the RASBB FPGA can compute the Angle of Arrival (AoA) of any detected transmission.

---

## 2. Angle of Arrival (AoA) Theory

### 2.1 Basic Principle

Angle of Arrival (AoA) allows the determination of the direction a wireless signal is coming from. Four directional antennas connected to four receivers are arranged to each "look" in a different direction, together covering the full 360° surroundings. When a device transmits a signal, each antenna receives it at a slightly different moment, and by precisely measuring those tiny timing differences the system can calculate the exact angle the signal came from. Using four antennas instead of just two or three improves accuracy and eliminates ambiguities. 

### 2.4 Algorithms Considered

To be added

---

## 3. Phase Coherence Strategy

All 4 MAX2831 transceivers must share a single reference clock to ensure phase coherence across channels. Any independent oscillator drift would introduce pseudo-random phase offsets that make AoA estimation impossible.

**Approach:**
- Route a single master clock (from RASBB or an on-board TCXO) to all four MAX2831 REF_CLK inputs
- Use matched-length PCB traces from the clock source to each transceiver
- Use matched-length traces from ADC outputs to the PCIe connector

The MAX2831 requires a 40 MHz reference clock. This is consistent with the 40 MHz TCXO already used on the RASRF2400WB board.

---

## 4. ADC and Data Path

Each MAX2831 produces a baseband I/Q analog output. Each of the 4 channels feeds an ADC for digitisation. The digitised streams are serialised for transport over the PCIe interface to the RASBB.

Data rate estimate per channel:
- 6-bit I, 6-bit Q @ 40 MSPS = 480 Mbit/s per channel (ADC3424 D0 only - D1 pairs not connected)
- 4 channels = 1.92 Gbit/s total

---

## 5. PCB Stack-up 

The RASRF2400WBMC PCB will use a **6-layer stack-up**:

| Layer | Function |
|---|---|
| Top | RF and signal routing |
| L2 | Ground plane |
| L3 | Power plane/signal routing |
| L4 | Power plane/signal routing |
| L5 | Ground plane |
| L6 | Signal routing |

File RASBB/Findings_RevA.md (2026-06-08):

## Errors, Issues and improvements found in RASBB PCB design revision A.

| ID 	| State 	| Description 	 | Solution |
|----	|---	|---	 |--- |
| 1  	| open  	| Footprint J5 and J6 are 1.0mm pitch | change to 1.27mm  |
| 2  	| closed  | Rename Pins of D11 to JTAG signal | |
| 3  	| closed  | Add marking point of Pin 1 on headers  | |
| 4  	| closed  | J9 is smaller than expected | needs to be shifted more towards PCB edge |
| 5  	| closed 	| J12 needs a 180deg rotation | |
| 6  	| closed 	| DDR3 RAM VSSQ_5 connected to 1.35V  | |
| 7  	| closed  | Add LEDs to all DC DC Outputs | |
| 8  	| closed  	| Add shut restistors at the in/output of 1V DC DC | |
| 9  	| closed 	| 1V DC DC EN voltage too low | Modify the value of resistor divider R36 and R37|
| 10 	| closed  | No Indication fur MCU if FPGA is on | Wire the two DONE lines from FPGAs to unused MCU pins |
| 11 	| closed  | No visible feedback from FPGAs | Add some indication LEDS to each FPGA |
| 12	| open | Rename DEBUG pins of FPGA | Better call them ICON01 02 etc |
| 13	| open | ICON change from J5/J6 to one 50pin 0.5mm FPC | also pin count needs to be increased to 32+8, a total of 40 lines |
| 14 	| open | ICON has no protection resistor | add 47R resistor arrays on each side towards FPGA |
| 15	| closed  | MCU LEDs are very bright  	 | increase pre-diode resistors to 1k |
| 16	| closed  | J16, J18 Non-Standard header spacing | increase spacing of J16, J18 to 0.1" / 2.54mm |
| 17 	| closed  | Add human readable labels to pin headers | like "MCU JTAG", "AP JTAG" (for FPGA01) and "DP JRAG" für FPGA02 and add thermal isolation to drill holes |
| 18 	| closed  | Rotate one JTAG pin header so the have the same orientation | |
| 19	| open | Add one more button for FPGA internal Reset | Maybe use smaller ones and change thos of PROGRAM_B also to save space |
| 20	| open | Change U12 to RTL8211FS with PTP support | |
| 21	| closed  | Add JTAG header target to silkscreen Text | like "STM32", "FPGA 1", "FPGA 2"|
| 22	| closed  | Correct second flash signals to FPGA2 | SO and SI connection should be swapped |
| 23	| closed  | Terminate all LVSD signals with 100Ohm |  |
| 24	| closed  | Pin out of ethernet jacks are wrong. | Pins 17-20 are mixed with 13-16 |
| 25	| closed  | DDR3 RAM A14 not connected | wire to free pin on same bank as A13 |
| 26  | open | Add LO Phase Sync. over Ethernet. One pair of the 100MBit connection to the STM32 receives a 10MHz Signal into a balanced line driver and the return the signal to the other free wire pair.
| 27  | open | Connect a comparator to the 10 MHz signal and feed the digitalized signal into FPGA2.
| 28  | open | Connect an output pin of FPGA2 to a RC low pas filter (mimics a PWM DAC)
| 29  | closed  | Add shunt resistor (0805) and 2 pin header paralell in front of PCIE connector to be able to measure front end power consumption.

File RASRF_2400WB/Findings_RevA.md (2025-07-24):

## Errors, Issues and improvements found in RASRF_2400_WB PCB design revision A.

| ID 	| State 	| Description 	 | Solution |
|----	|---	|---	 |--- |
| 1 	| open | Silkscreen name wring | change to RASRF_2400WB |
| 2 	| open | Change as much as possible SMD TP to THT | take TP11 as reference |
| 3 	| open | U8 + and - inputs are flipped | Exchange U8 pin 3 and 4 |
| 	| open | 	 | |

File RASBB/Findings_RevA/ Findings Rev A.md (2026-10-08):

## Errors, Issues and improvements found in RASBB PCB design revision A.

| ID 	| State 	| Description 	 | Solution |
|----	|---	|---	 |--- |
| 1  	| closed  | Footprint J5 and J6 are 1.0mm pitch | change to 1.27mm  |
| 2  	| closed  | Rename Pins of D11 to JTAG signal | |
| 3  	| closed  | Add marking point of Pin 1 on headers  | |
| 4  	| closed  | J9 is smaller than expected | needs to be shifted more towards PCB edge |
| 5  	| closed 	| J12 needs a 180deg rotation | |
| 6  	| closed 	| DDR3 RAM VSSQ_5 connected to 1.35V  | |
| 7  	| closed  | Add LEDs to all DC DC Outputs | |
| 8  	| closed  	| Add shut restistors at the in/output of 1V DC DC | |
| 9  	| closed 	| 1V DC DC EN voltage too low | Modify the value of resistor divider R36 and R37|
| 10 	| closed  | No Indication fur MCU if FPGA is on | Wire the two DONE lines from FPGAs to unused MCU pins |
| 11 	| closed  | No visible feedback from FPGAs | Add some indication LEDS to each FPGA |
| 12	| rejected | Rename DEBUG pins of FPGA | Better call them ICON01 02 etc |
| 13	| closed (Rev C)  | ICON change from J5/J6 to one 50pin 0.5mm FPC | also pin count needs to be increased to 32+8, a total of 40 lines |
| 14 	| closed (Rev C) | ICON has no protection resistor | add 47R resistor arrays on each side towards FPGA |
| 15	| closed  | MCU LEDs are very bright  	 | increase pre-diode resistors to 1k |
| 16	| closed  | J16, J18 Non-Standard header spacing | increase spacing of J16, J18 to 0.1" / 2.54mm |
| 17 	| closed  | Add human readable labels to pin headers | like "MCU JTAG", "AP JTAG" (for FPGA01) and "DP JRAG" für FPGA02 and add thermal isolation to drill holes |
| 18 	| closed  | Rotate one JTAG pin header so the have the same orientation | |
| 19	| closed (Rev C) | Add one more button for FPGA internal Reset | Connect the line also to the STM32 so this can also pull the reset of the FPGA. Maybe use smaller ones and change thos of PROGRAM_B also to save space |
| 20	| rejected | Change U12 to RTL8211FS with PTP support | |
| 21	| closed  | Add JTAG header target to silkscreen Text | like "STM32", "FPGA 1", "FPGA 2"|
| 22	| closed  | Correct second flash signals to FPGA2 | SO and SI connection should be swapped |
| 23	| closed  | Terminate all LVSD signals with 100Ohm |  |
| 24	| closed  | Pin out of ethernet jacks are wrong. | Pins 17-20 are mixed with 13-16 |
| 25	| closed  | DDR3 RAM A14 not connected | wire to free pin on same bank as A13 |
| 26  | closed (Rev C) | Add 40MHz and 1MHz sync clock over Ethernet. One pair of the 100MBit connection to the STM32 receives 40MHz and 1MHz clock via line receivers and send it (unbalanced is good enogh) into the U10 FPGA 1 and 2 (1MHz) and the 40MHz shall be provided via SMA/SMB jack via coax wire to the FE. Do not popuilate the jack, i will solder by hand.
| 27  | closed( Rev C) | Add another shunt resistor at the 12V entry of the 1V DC DC converter |
| 28  | closed  (Rev C) | Connect an output pin of FPGA2 to a RC low pas filter (mimics a PWM DAC)
| 29  | closed  | Add shunt resistor (0805) and 2 pin header paralell in front of PCIE connector to be able to measure front end power consumption.
| 30  | closed (Rev C)  | WP# and #RESET of FPGA config flashes is unconnected | Add 10 kΩ pull-up to VCC3V3 
| 31  | closed (Rev C)| Add solder mask opening squares at the edges to support ground connection for flying probes
| 32  | closed (Rev C) | Enable Voltage U3 uncertain | Change R36 from 100k to 220k to have a safe window 2.0 V < EN < 5.3 V across the full 10.8–13.2 V input
| 33  | closed (Rev C)  | Debug header J8 STM32 has no ground and VCC | Change to 10 pins and add Vcc from the area and GND |
| 34  | closed (Rev C)  | DC phantom powering over HDMI causes startup problems | Block DC of HDMI port J3 by inserting 8x 100nF 0402 in the path. Also add 270R pull-ups to 3.3V on the other side of IC11 towards FPGA1 |
| 35  | closed (Rev C)  | Wire 5V from U4 (5V) to PCIe A1,2,3 B1,2,3 via big shunt resistor | The shunt can also be used as jumper. Maybe add 12V to another jumper but populate only the 5V shunt |

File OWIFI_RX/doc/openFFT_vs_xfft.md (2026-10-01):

# openFFT versus Xilinx xfft 9.1 in the RA-Sentinel receiver

openofdm's 64-point FFT (`sync_long.v`) comes from openFFT now. The AMD/Xilinx
Fast Fourier Transform 9.1 core is no longer part of any build; after
openViterbi, openCMUL and openCDIV it was the last Xilinx core in the
receiver, so `[openofdm::ip]` is an empty list and the receiver is plain
Verilog from the ADC samples to the decoded bytes. The board design keeps
one Xilinx IP, the `Video_clk` MMCM of the HDMI output.

## What the receiver asks of the FFT

`sync_long.v` feeds each OFDM symbol as a burst of 64 samples in 64
consecutive clocks (16-bit I and Q), with the 20 MHz sample stream arriving
in the background, and takes the 23-bit unscaled result in natural order,
of which it keeps bits 22:7. Symbols are 80 samples = 400 clocks apart at
100 MHz. The IP was configured as *pipelined streaming I/O*, unscaled,
truncation, natural order, non-realtime throttle; its first result arrived
212 clocks after the first sample.

`fft_axis` has the IP's AXI4-Stream ports, data layout and configuration
word, so `sync_long.v` only changed the module name and added the
parameters:

```
fft_axis #(.LOG2_N(6), .DATA_WIDTH(16), .TWIDDLE_WIDTH(16), .ARCH(1),
           .SCALING(0), .ROUND_MODE(0), .OUTPUT_ORDER(1), .LATENCY(212)) dft_inst (...)
```

`ARCH = 1` is the pipelined streaming engine (radix-2^2 single-path delay
feedback, one sample per clock). `LATENCY = 212` pads the engine's natural
141 clocks to the IP's latency, see below.

## Measured comparison

Same conditions for all rows: xc7a100tcsg324-2, Vivado 2025.2
out-of-context synthesis + opt_design, Fmax estimated from the worst slack
against a 5 ns clock. The receiver runs at 100 MHz. BRAM counts RAMB18 and
RAMB36 alike.

| core | configuration | latency | LUT | FF | BRAM | DSP48E1 | Fmax est. |
|---|---|---|---|---|---|---|---|
| Xilinx xfft 9.1 | pipelined streaming, unscaled, natural order | 212 | 1403 | 2609 | 2 | 6 | ~348 MHz |
| openFFT `fft_axis` | streaming, `LATENCY=212` (as instantiated) | 212 | 1344 | 800 | 1 | 8 | ~225 MHz |
| openFFT `fft_axis` | streaming, natural latency | 141 | 1173 | 635 | 1 | 8 | ~225 MHz |
| openFFT `fft_axis` | streaming, `OPTIMIZE_GOAL=0` (three multipliers per complex one) | 143 | 1268 | 943 | 1 | 6 | ~225 MHz |
| openFFT `fft_axis` | burst (`ARCH=0`), one butterfly | 295 | 850 | 446 | 0 | 4 | ~201 MHz |

The whole receiver (`dot11`, out of context, same part and flow):

| | LUT | FF | BRAM | DSP48E1 |
|---|---|---|---|---|
| with xfft 9.1 | 23 917 | 16 266 | 18 | 69 |
| with openFFT | 23 705 | 14 343 | 17 | 71 |

## Verification

* openFFT's bench drives the core and the IP's own simulation netlist
  (`ip_repo/xfft_v9`, written by openofdm's `make refnetlists`) with the
  same 14 400 result samples - random data, tones, impulses, samples at the
  rails, with idle clocks and back pressure: 91 % of the 23-bit results are
  bit-identical, 99.92 % identical in bits 22:7 (what `sync_long.v` keeps),
  no result differs by more than 2 LSB (RMS 0.25 LSB), and both cores show
  the same error against a double precision transform (max 21.8 LSB, RMS
  2.33 LSB). The latency of both is 212 clocks. Seven further configurations
  (burst engine, scaled, bit reversed, 8 .. 256 points, LUT multipliers,
  block RAM) are checked bit for bit against a model of the arithmetic.
* openofdm's `make regression` (31 reference vectors, 802.11a/g rate ladder,
  802.11n MCS 0-7, simulated frames, side-channel and noise captures): every
  vector gives the same verdict, frame count and payload bytes as with the
  IP.
* Hardware, 2026-10-01: the WBMC build with openFFT (`build_wbmc.tcl` and
  the Vivado project alike) meets timing (WNS +0.177 ns) and, loaded over
  JTAG after a power-cycle, shows the usual frame log and decodes on air.

## The latency

With the engine's natural 141 clocks, 30 of the 31 vectors decoded exactly
as before, but the 65 Mbps conducted capture (MCS 7, a weak capture that
yields 3 of 9 frames with the IP) lost those three frames. Delaying the FFT
output by the missing 71 clocks in an experiment restored them, with
identical decode timestamps. The cause is in `dot11.v`, not in the FFT:
after decoding HT-SIG it decides by `num_ofdm_symbol == 5` (sync_long's
count of loaded symbols at that moment) whether the HT-STS symbol has to be
skipped to keep the equalizer aligned - a documented "quick fix" that ties
the control flow to the moment the FFT results come out. The IP's 212
clocks were part of that tuning, so openFFT is instantiated with
`LATENCY = 212` (an SRL delay line, 171 LUT / 165 FF). The proper fix is a
feedback from the decoder to the symbol handling in `dot11.v`; until then
the latency parameter must move together with that logic.

## Building

Nothing to configure when `openFFT` is cloned next to `openofdm` (or
`$OPENFFT` points at it): `tools/openofdm_sources.tcl` returns its
`rtl/*.v` with the receiver sources, `build_wbmc.tcl`, `build_rasbb.tcl`
and the simulation scripts pick them up, and `owifi.xpr` lists them
instead of the `xfft_v9` fileset. No IP is generated for the receiver any
more, so a bitstream build needs no IP catalog and no licence.

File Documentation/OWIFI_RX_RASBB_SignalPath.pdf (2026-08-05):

## Traps, open items and things that fail silently

Ordered by how expensive the mistake is. 'Fails silently' means the tools report success and the symptom appears somewhere else entirely.

Area | Item | Detail

Fails silently - highest cost first
Area | Item | Detail
Build | LUT_DIR macro
Build | OWIFI_SRC macro | Locates font8x16.mem for text_screen. Same mechanism, set by build_rasbb.tcl.
Build | Check the three $readmem lines
Flash | Power-cycle before every flash write | WP#/IO2 on IC5 and IC7 is unconnected - confirmed FROM PCB (pad 3 unconnected on both). A warm write silently does nothing.
Vivado | .xpr element order
Simulation | Command-line -d beats an `include-d `define
Simulation | Packed-hex vectors must be converted | The bench reads two decimal columns per line (I Q). Most captures under testing_inputs/conducted/ are packed hex.

Hardware - open or needing verification
Area | Item | Detail
Constraints
RASRF | U8 part number not specified | The clock squarer between the 40 MHz TCXO and CLK_REF is a SOT-23-5 whose schematic Value is '~'.
RASRF | U8 inputs flipped | Findings_RevA.md item 3: U8's + and - inputs are exchanged; the fix is to swap pads 3 and 4.
HDMI | Phantom power through the TMDS pins
Front end | External 100 R on every used LVDS pair
Front end | Reconfigure the FPGA after any ADC re-init

Design rules that must not be relaxed
Area | Item | Detail
Timing | DCLK is a TRUE 120 MHz clock | Constrain it at 8.333 ns. The old 16.667 ns constraint hid real failures that came and went with placement luck - RASM2400 'finding D1'.
Timing
Timing | The Viterbi ACS is the critical path
Front end | Word assembly order | {lane_cur, lane_hist} - the NEWER word in the HIGH half. Do not 'fix' it back to {hist, cur}.
Pins | Derive pins from the .kicad_pcb
Vivado | Never run upgrade_ip -quiet | The openofdm .xci were saved for whatever part they were last used on. upgrade_ip retargets them; a silent failure leaves the IP locked.
Vivado | Do not build OWIFI from a GUI project
Simulation | | build_rasbb.tcl does reset_target all and then regenerates only the SYNTHESIS target, so simulation products go missing.

Receiver limits - functional, not defects
Area | Item | Detail
Receiver | 54 Mbps and MCS7 are margin-limited | 64-QAM 3/4 and 64-QAM 5/6 are the least-protected rates in the set. A 14-byte 54 Mbps frame decodes; a 1537-byte one does not. MCS7 passes 3 of 9.

Locates openofdm's three ROM .mif files for $readmemh. Both synthesis and XSim resolve a relative $readmem path against the TOOL's working directory, not the source file's, so it cannot have a relative default. Set by [openofdm::defines].

After 'make check' or a synth run, confirm the log contains three 'INFO: [Synth 8-3876] ... is read successfully' lines for rot_lut, atan_lut and deinter_lut_from_coe.

Inside a <Config> block every <Option Name="VerilogDir"> (the include path) must come BEFORE any <Verilog_Define>. Put a define first and Vivado drops the entire include path on load - no error, no warning.
Measured precedence, the opposite of the intuition. A stale verilog_define persisted in a .xpr once produced three consecutive plausible-looking runs against an old vector.

Bank 14 VCCO is +3V3 but the debug ports are LVCMOS18

RASBB.kicad_pcb has VCCO_14 on +3V3 (6 pins), and J5/J6 carry +3V3 on pins 2 and 20. rasbb_rasrf.xdc constrains dbgBitClk, dbgFrameRdy, dbgIser, dbgQser, dbgOutI[*], dbgOutQ[*], Key0 and Key1 as LVCMOS18. This is the SAME class of mismatch as the bank-15 SPI/TMDS pins, which were corrected on 2026-08-02 after the PCB was checked.

A connected monitor's TMDS terminations back-feed +3V3 through FPGA bank-15 clamp diodes; the TPD12S016 does not block TMDS. Planned rework: 8 x 100 nF in series between the IC11 tap and J3, plus 8 x 270 R bias.

The ADC pins are DIFF_SSTL18_II in an HR bank at VCCO 1.8 V. DIFF_TERM is inert there (LVDS_25 / 2.5 V only, UG471), and IN_TERM's Thevenin split to 0.9 V fights the ADC's ~1.2 V common mode.
After any reconfiguration or reset of the ADC - for example an STM32 firmware reflash that re-runs ADC init - the link can slip word alignment in a way the FCLK watchdog cannot see.

Setup is not negotiable, hold on the ADC pads is

build_rasbb.tcl refuses to write a bitstream when WNS < 0. Hold is false-pathed on ADC_chA/B/C only, because the runtime IDELAY calibration re-centres the eye and the static min-delay number says nothing about it. Setup stays analysed everywhere.
~15 logic levels, ~60% route delay, and congestion-sensitive: adding the frame buffer's BRAMs alone once cost 175 ps and pushed it negative with default directives.

RASBB has a known .net-vs-.kicad_pcb desync. A stale RASM2400 constraint set mapped TMDS onto D4/C4/E1/D1/F2/E2/G2 - PCIe RX lanes, GND and +1V8 on this board - and would have collided with ADC_chA_N and ADC_chB_N.

The batch flow (tools/build_rasbb.tcl) is authoritative - it produced every bitstream that ran on hardware. owifi.xpr and RASBB/Software/AP_FPGA/AP_FPGA.xpr carry absolute paths and are not portable.
Regenerate simulation targets after a bitstream build

Receiver | 802.11b is not supported | DSSS/CCK is an entirely different PHY - Barker spreading and CCK correlation. No such logic exists anywhere in the tree.
Receiver | 5 GHz / real 802.11a is not reachable | The MAX2831 is a 2.4 GHz transceiver. The PHY itself already decodes all 11a rates.
Receiver | HT Greenfield untested | The flow detects L-SIG and then HT-SIG, i.e. HT mixed mode. Greenfield frames carry no L-SIG, and no vector was available.
Frame log | CFO sign convention uncalibrated
Front end | ramp_checker over-counts | Its BER figure over-counts, per the RASPMO work.
Tuning | CR_POWER_THRES wants a re-sweep | The power_trigger threshold has not been re-swept on this hardware. The magnitude is measured; which oscillator is high has never been checked against a generator. The sign is kept even when the magnitude truncates to zero (' -0K') so a calibration has something to read.

What happens if you get it wrong | Status / source
What happens if you get it wrong | Status / source known, documented
The HDMI frame log comes up garbled. Synthesis only warns. | known, documented
Without this check a broken build is indistinguishable from a working one until nothing decodes. procedure
You flash, nothing changes, and you debug the wrong thing. | hardware fact known, documented
| mitigated
A vector feeds in and nothing happens. Convert with scripts/conv_iq_hex.py first. | known
What happens if you get it wrong | Status / source
The BOM cannot be built as-is. | OPEN - RASRF2400WB Rev A
The reference squarer does not work as drawn. | OPEN - Findings_RevA.md
| known, rework planned
Without the external termination the eye closes and the link behaves like an RF problem. | hardware fact
Silent, persistent misalignment. Reconfigure the FPGA or toggle i_rst afterwards. | hardware fact
What happens if you get it wrong | Status / source
Intermittent decode garbage that looks like an RF problem. | rule
Shipping a setup violation means shipping intermittent, RF-looking decode errors. | rule
| rule
| rule
Pin collisions with the ADC inputs, found late. | rule
Synthesis dies on a missing module while the IP reports 'up to date'. | rule
A GUI build can differ from the shipped one in ways nobody tracks. | rule
| known
What happens if you get it wrong | Status / source MEASURED 2026-08-01

Synthesis only WARNS, the ROMs load as X, and the receiver decodes nothing while looking perfectly healthy.

Synthesis cannot open common_params.v, and the cause is nowhere near the symptom. Set both through tcl instead, so Vivado writes canonical XML by construction.
A simulation 'passes' against the wrong capture. Every sim script now rewrites the define list explicitly, and the bench writes the macro it actually compiled into sample_file_name.txt - check that file, not your intent.

The bank is internally consistent to Vivado (every bank-14 port uses the same standard), so nothing is flagged - but the pins actually swing 3.3 V, and the declared drive/slew numbers are those of a standard the bank is not running. The inputs (Key0/Key1) still read correctly. Worth deciding deliberately rather than by inheritance.

OPEN - verify VCCO_14 on the assembled board, then either change to LVCMOS33 or record why not

The board is partly powered through its HDMI output. Also: once the AC-coupling rework goes in, a push-pull DIFF_SSTL18 drive would exceed the sink's absolute maximum - which is one more reason TMDS_33 must stay.

Anything added to the design can break timing from a distance. Re-check WNS after every addition - the HDMI branch in particular.
That ordering was a MEASURED 1-error-per-16-words assembly bug: 2.5 M errors/s at 20 MSPS, flat across all IDELAY taps.

'Can not find file: .../div_gen_xlslice/sim/div_gen_xlslice_0_0.v'. Run generate_target simulation first.

Not a demodulation fault: the count of frames containing the exact expected MAC pair equals the FCS-OK count at every MCS, so a frame either comes out perfect or carries a handful of wrong bits.

by design

Needs a different front end, not firmware. | by design
Flagged rather than asserted - probably unsupported. | IN RTL, UNTESTED
Do not trust the direction until it is calibrated once. | IN RTL, UNTESTED
Treat it as a go/no-go indicator, not a measurement. | known
Detection sensitivity is not at its optimum. | OPEN

Adding it means a second receive chain plus arbitration with the OFDM path - a project, not a
change.

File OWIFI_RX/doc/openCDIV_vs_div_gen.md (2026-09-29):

# openCDIV versus Xilinx div_gen 5.1 in the RA-Sentinel receiver

openofdm's four real divisions come from openCDIV now: the two of the
equalizer (inside `complex_divider`), the LVPE/SFO division (equalizer) and
the arctangent division (`phase.v`), both through `divider.v` ->
`signed_divider`. The Xilinx Divider Generator 5.1 and its
`div_gen_xlslice` are no longer part of any build; after openViterbi and
openCMUL, the FFT (`xfft_v9`) is the only Xilinx core left in the receiver.

## The complex division

The equalizer divides every subcarrier x by the channel estimate h. Division
by a complex number becomes two real divisions after multiplying numerator
and denominator by the conjugate of h:

```
       x      x * conj(h)
  q = --- = -------------
       h     h * conj(h)
```

`h * conj(h) = hr^2 + hi^2` is real, so the real and imaginary parts of
`x * conj(h)` are each divided by it. openCDIV's `complex_divider` does
exactly this with two openCMUL multipliers and two `signed_divider`s, in
openofdm's arithmetic bit for bit: 16-bit x and h, the top 32 bits of the
33-bit products, the numerator scaled by 2^11 (`CONS_SCALE_SHIFT + 1`),
the denominator cut to 24 bits, the quotient rounded toward zero. The same
two dividers also average the channel estimate (a sum of 3..5 LTS samples
divided by their number) through the module's direct `n / d` input.

## Measured comparison

Same conditions for all rows: xc7a100tcsg324-2, Vivado 2025.2
out-of-context synthesis + opt_design, Fmax estimated from the worst slack
against a 3 ns clock. The receiver runs at 100 MHz.

| core | datapath | latency | LUT | FF | DSP48E1 | Fmax est. |
|---|---|---|---|---|---|---|
| Xilinx div_gen 5.1 + xlslice | one real division, 32 / 24 bit | 36 | 952 | 2166 | 0 | ~229 MHz |
| openCDIV `signed_divider` | one real division, 32 / 24 bit | 36 | 968 | 1827 | 0 | ~312 MHz |
| 2x openCMUL + 2x div_gen 5.1 | `x * conj(h) / (h * conj(h))` | 39 | 1963 | 4333 | 6 | ~229 MHz |
| openCDIV `complex_divider` | `x * conj(h) / (h * conj(h))` | 39 | 1976 | 3598 | 6 | ~308 MHz |

The receiver has four dividers. In the routed WBMC design (build_wbmc.tcl,
same source tree, only the dividers changed):

| build | LUT | FF | BRAM tiles | DSP48E1 | WNS |
|---|---|---|---|---|---|
| with div_gen 5.1 | 37 740 | 35 409 | 50 | 104 | +0.018 ns |
| with openCDIV | 37 318 | 32 831 | 50 | 104 | +0.128 ns |

(-422 LUT, -2 578 FF; the LVPE divider has a constant divisor, which
synthesis folds further than it could inside the IP.)

## Verification

* openCDIV's benches: `signed_divider` every clock against the div_gen
  funcsim netlist (cycle-exact, incl. division by zero - `phase.v` takes
  atan(0/0) of a zero sample and relies on the IP's -1), `complex_divider`
  every clock against the former datapath rebuilt from the cmpy and
  div_gen netlists; further parameter sets against behavioural models.
* openofdm's receiver regression (`make regression`, all 40 reference
  vectors: 802.11a rate ladder, 802.11n MCS ladder, radiated and simulated
  captures) before and after the change: identical FCS verdicts and frame
  counts, and all 280 dump files byte-identical - payload bytes, SIGNAL
  fields and the equalizer output streams (214 068 equalized subcarriers).
* WBMC bitstream built from this tree: timing met (see table).

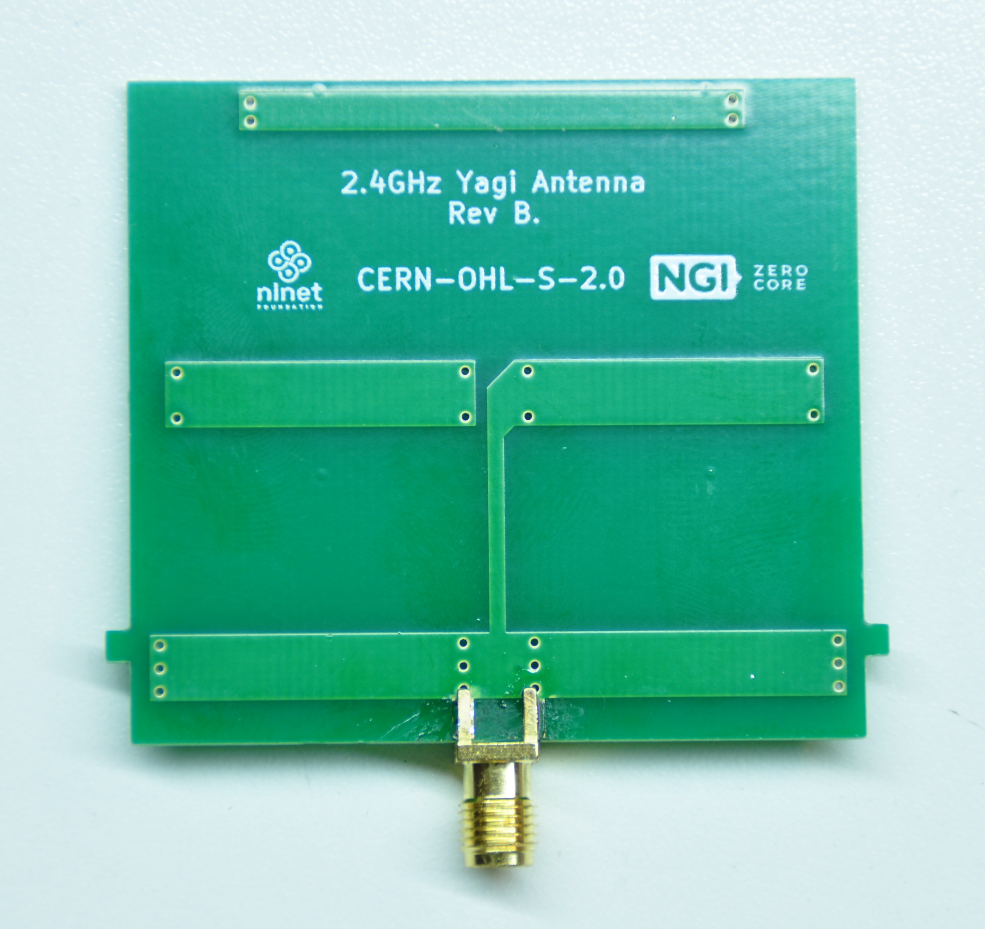
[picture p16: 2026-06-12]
RASANT2400/Images/RASANT2400_RevB_front.jpg

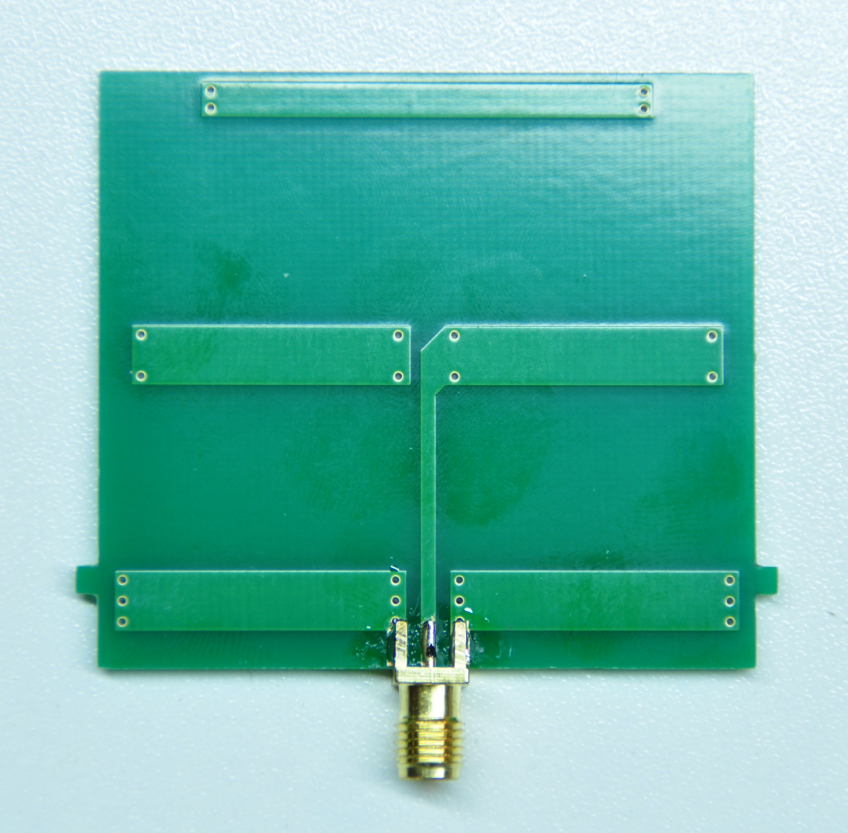
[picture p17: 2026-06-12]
RASANT2400/Images/RASANT2400_RevB_back.jpg

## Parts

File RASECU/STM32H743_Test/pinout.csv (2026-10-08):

Position | Name | Type | Signal | Label | AF0 | AF1 | AF2 | AF3 | AF4 | AF5 | AF6 | AF7 | AF8 | AF9 | AF10 | AF11 | AF12 | AF13 | AF14
1 | PE2 | Input | GPIO_Input | LORA_DIO1 | DEBUG_TRACECLK |  | SAI1_CK1 |  |  | SPI4_SCK | SAI1_MCLK_A |  | SAI4_MCLK_A | QUADSPI_BK1_IO2 | SAI4_CK1 | ETH_TXD3 | FMC_A23
2 | PE3 | Input | GPIO_Input | LORA_DIO2 | DEBUG_TRACED0 |  |  |  | TIM15_BKIN |  | SAI1_SD_B |  | SAI4_SD_B |  |  |  | FMC_A19
3 | PE4 | I/O | DCMI_D4 |  | DEBUG_TRACED1 |  | SAI1_D2 | DFSDM1_DATIN3 | TIM15_CH1N | SPI4_NSS | SAI1_FS_A |  | SAI4_FS_A |  | SAI4_D2 |  | FMC_A20 | DCMI_D4 | LTDC_B0
4 | PE5 | I/O | DCMI_D6 |  | DEBUG_TRACED2 |  | SAI1_CK2 | DFSDM1_CKIN3 | TIM15_CH1 | SPI4_MISO | SAI1_SCK_A |  | SAI4_SCK_A |  | SAI4_CK2 |  | FMC_A21 | DCMI_D6 | LTDC_G0
5 | PE6 | I/O | DCMI_D7 |  | DEBUG_TRACED3 | TIM1_BKIN2 | SAI1_D1 |  | TIM15_CH2 | SPI4_MOSI | SAI1_SD_A |  | SAI4_SD_A | SAI4_D1 | SAI2_MCLK_B | TIM1_BKIN2_COMP1/TIM1_BKIN2_COMP2 | FMC_A22 | DCMI_D7 | LTDC_G1
6 | VBAT | Power
7 | PC13 | Output | GPIO_Output | LORA_NRST
8 | PC14-OSC32_IN (OSC32_IN) | Input | GPIO_Input | LORA_BUSY
9 | PC15-OSC32_OUT (OSC32_OUT) | Input | GPIO_Input | LORA_DIO3
10 | VSS | Power
11 | VDD | Power
12 | PH0-OSC_IN (PH0) | I/O | RCC_OSC_IN
13 | PH1-OSC_OUT (PH1) | I/O | RCC_OSC_OUT
14 | NRST | Reset
15 | PC0 | Input | GPIO_Input | uC_CONFIG |  |  |  | DFSDM1_CKIN0 |  |  | DFSDM1_DATIN4 |  | SAI2_FS_B |  | USB_OTG_HS_ULPI_STP |  | FMC_SDNWE |  | LTDC_R5
16 | PC1 | I/O | ETH_MDC |  | DEBUG_TRACED0 |  | SAI1_D1 | DFSDM1_DATIN0 | DFSDM1_CKIN4 | I2S2_SDO/SPI2_MOSI | SAI1_SD_A |  | SAI4_SD_A | SDMMC2_CK | SAI4_D1 | ETH_MDC | MDIOS_MDC
17 | PC2_C | I/O |  |  |  |  |  | DFSDM1_CKIN1 |  | I2S2_SDI/SPI2_MISO | DFSDM1_CKOUT |  |  |  | USB_OTG_HS_ULPI_DIR | ETH_TXD2 | FMC_SDNE0
18 | PC3_C | I/O | SPI2_MOSI |  |  |  |  | DFSDM1_DATIN1 |  | I2S2_SDO/SPI2_MOSI |  |  |  |  | USB_OTG_HS_ULPI_NXT | ETH_TX_CLK | FMC_SDCKE0
19 | VSSA | Power
20 | VREF+ | MonoIO
21 | VDDA | Power
22 | PA0 | I/O |  |  |  | TIM2_CH1/TIM2_ETR | TIM5_CH1 | TIM8_ETR | TIM15_BKIN |  |  | USART2_CTS/USART2_NSS | UART4_TX | SDMMC2_CMD | SAI2_SD_B | ETH_CRS
23 | PA1 | I/O | ETH_REF_CLK |  |  | TIM2_CH2 | TIM5_CH2 | LPTIM3_OUT | TIM15_CH1N |  |  | USART2_DE/USART2_RTS | UART4_RX | QUADSPI_BK1_IO3 | SAI2_MCLK_B | ETH_REF_CLK/ETH_RX_CLK |  |  | LTDC_R2
24 | PA2 | I/O | ETH_MDIO |  |  | TIM2_CH3 | TIM5_CH3 | LPTIM4_OUT | TIM15_CH1 |  |  | USART2_TX | SAI2_SCK_B |  |  | ETH_MDIO | MDIOS_MDIO |  | LTDC_R1
25 | PA3 | Output | GPIO_Output | ETH_NRST |  | TIM2_CH4 | TIM5_CH4 | LPTIM5_OUT | TIM15_CH2 |  |  | USART2_RX |  | LTDC_B2 | USB_OTG_HS_ULPI_D0 | ETH_COL |  |  | LTDC_B5
26 | VSS | Power
27 | VDD | Power
28 | PA4 | I/O | DCMI_HSYNC |  |  |  | TIM5_ETR |  |  | I2S1_WS/SPI1_NSS | I2S3_WS/SPI3_NSS | USART2_CK | SPI6_NSS |  |  |  | USB_OTG_HS_SOF | DCMI_HSYNC | LTDC_VSYNC
29 | PA5 | I/O | DAC1_OUT2 |  |  | TIM2_CH1/TIM2_ETR |  | TIM8_CH1N |  | I2S1_CK/SPI1_SCK |  |  | SPI6_SCK |  | USB_OTG_HS_ULPI_CK |  |  |  | LTDC_R4
30 | PA6 | I/O | DCMI_PIXCLK |  |  | TIM1_BKIN | TIM3_CH1 | TIM8_BKIN |  | I2S1_SDI/SPI1_MISO |  |  | SPI6_MISO | TIM13_CH1 | TIM8_BKIN_COMP1/TIM8_BKIN_COMP2 | MDIOS_MDC | TIM1_BKIN_COMP1/TIM1_BKIN_COMP2 | DCMI_PIXCLK | LTDC_G2
31 | PA7 | I/O | ETH_CRS_DV |  |  | TIM1_CH1N | TIM3_CH2 | TIM8_CH1N |  | I2S1_SDO/SPI1_MOSI |  |  | SPI6_MOSI | TIM14_CH1 |  | ETH_CRS_DV/ETH_RX_DV | FMC_SDNWE
32 | PC4 | I/O | ETH_RXD0 |  |  |  |  | DFSDM1_CKIN2 |  | I2S1_MCK |  |  |  | SPDIFRX1_IN2 |  | ETH_RXD0 | FMC_SDNE0
33 | PC5 | I/O | ETH_RXD1 |  |  |  | SAI1_D3 | DFSDM1_DATIN2 |  |  |  |  |  | SPDIFRX1_IN3 | SAI4_D3 | ETH_RXD1 | FMC_SDCKE0 | COMP1_OUT
34 | PB0 | Output | GPIO_Output | CS_MUX2 |  | TIM1_CH2N | TIM3_CH3 | TIM8_CH2N |  |  | DFSDM1_CKOUT |  | UART4_CTS | LTDC_R3 | USB_OTG_HS_ULPI_D1 | ETH_RXD2 |  |  | LTDC_G1
35 | PB1 | I/O | ADC1_INP5 |  |  | TIM1_CH3N | TIM3_CH4 | TIM8_CH3N |  |  | DFSDM1_DATIN1 |  |  | LTDC_R6 | USB_OTG_HS_ULPI_D2 | ETH_RXD3 |  |  | LTDC_G0
36 | PB2 | I/O | SPI3_MOSI |  | RTC_OUT_ALARM/RTC_OUT_CALIB |  | SAI1_D1 |  | DFSDM1_CKIN1 |  | SAI1_SD_A | I2S3_SDO/SPI3_MOSI | SAI4_SD_A | QUADSPI_CLK | SAI4_D1 | ETH_TX_ER
37 | PE7 | Output | GPIO_Output | SPI3_NSS |  | TIM1_ETR |  | DFSDM1_DATIN2 |  |  |  | UART7_RX |  |  | QUADSPI_BK2_IO0 |  | FMC_D4/FMC_DA4
38 | PE8 | Output | GPIO_Output | LED_9 |  | TIM1_CH1N |  | DFSDM1_CKIN2 |  |  |  | UART7_TX |  |  | QUADSPI_BK2_IO1 |  | FMC_D5/FMC_DA5 | COMP2_OUT
39 | PE9 | Output | GPIO_Output | LED_8 |  | TIM1_CH1 |  | DFSDM1_CKOUT |  |  |  | UART7_DE/UART7_RTS |  |  | QUADSPI_BK2_IO2 |  | FMC_D6/FMC_DA6
40 | PE10 | Output | GPIO_Output | LED_7 |  | TIM1_CH2N |  | DFSDM1_DATIN4 |  |  |  | UART7_CTS |  |  | QUADSPI_BK2_IO3 |  | FMC_D7/FMC_DA7
41 | PE11 | Output | GPIO_Output | SPI4_NSS |  | TIM1_CH2 |  | DFSDM1_CKIN4 |  | SPI4_NSS |  |  |  |  | SAI2_SD_B |  | FMC_D8/FMC_DA8 |  | LTDC_G3
42 | PE12 | I/O | SPI4_SCK |  |  | TIM1_CH3N |  | DFSDM1_DATIN5 |  | SPI4_SCK |  |  |  |  | SAI2_SCK_B |  | FMC_D9/FMC_DA9 | COMP1_OUT | LTDC_B4
43 | PE13 | I/O | SPI4_MISO |  |  | TIM1_CH3 |  | DFSDM1_CKIN5 |  | SPI4_MISO |  |  |  |  | SAI2_FS_B |  | FMC_D10/FMC_DA10 | COMP2_OUT | LTDC_DE
44 | PE14 | I/O | SPI4_MOSI |  |  | TIM1_CH4 |  |  |  | SPI4_MOSI |  |  |  |  | SAI2_MCLK_B |  | FMC_D11/FMC_DA11 |  | LTDC_CLK
45 | PE15 | Output | GPIO_Output | uC_PE15 |  | TIM1_BKIN |  |  |  |  |  |  |  |  |  |  | FMC_D12/FMC_DA12 | TIM1_BKIN_COMP1/TIM1_BKIN_COMP2 | LTDC_R7
46 | PB10 | I/O | SPI2_SCK |  |  | TIM2_CH3 | HRTIM_SCOUT | LPTIM2_IN1 | I2C2_SCL | I2S2_CK/SPI2_SCK | DFSDM1_DATIN7 | USART3_TX |  | QUADSPI_BK1_NCS | USB_OTG_HS_ULPI_D3 | ETH_RX_ER |  |  | LTDC_G4
47 | PB11 | I/O | ETH_TX_EN |  |  | TIM2_CH4 | HRTIM_SCIN | LPTIM2_ETR | I2C2_SDA |  | DFSDM1_CKIN7 | USART3_RX |  |  | USB_OTG_HS_ULPI_D4 | ETH_TX_EN |  |  | LTDC_G5
48 | VCAP | Power
49 | VSS | Power
50 | VDD | Power
51 | PB12 | I/O | ETH_TXD0 |  |  | TIM1_BKIN |  |  | I2C2_SMBA | I2S2_WS/SPI2_NSS | DFSDM1_DATIN1 | USART3_CK |  | FDCAN2_RX | USB_OTG_HS_ULPI_D5 | ETH_TXD0 | USB_OTG_HS_ID | TIM1_BKIN_COMP1/TIM1_BKIN_COMP2 | UART5_RX
52 | PB13 | I/O | ETH_TXD1 |  |  | TIM1_CH1N |  | LPTIM2_OUT |  | I2S2_CK/SPI2_SCK | DFSDM1_CKIN1 | USART3_CTS/USART3_NSS |  | FDCAN2_TX | USB_OTG_HS_ULPI_D6 | ETH_TXD1 |  |  | UART5_TX
53 | PB14 | I/O | SPI2_MISO |  |  | TIM1_CH2N | TIM12_CH1 | TIM8_CH2N | USART1_TX | I2S2_SDI/SPI2_MISO | DFSDM1_DATIN2 | USART3_DE/USART3_RTS | UART4_DE/UART4_RTS | SDMMC2_D0 |  |  | USB_OTG_HS_DM
54 | PB15 | Output | GPIO_Output | CS_MUX1 | RTC_REFIN | TIM1_CH3N | TIM12_CH2 | TIM8_CH3N | USART1_RX | I2S2_SDO/SPI2_MOSI | DFSDM1_CKIN2 |  | UART4_CTS | SDMMC2_D1 |  |  | USB_OTG_HS_DP
55 | PD8 | I/O | USART3_TX |  |  |  |  | DFSDM1_CKIN3 |  |  | SAI3_SCK_B | USART3_TX |  | SPDIFRX1_IN1 |  |  | FMC_D13/FMC_DA13
56 | PD9 | I/O | USART3_RX |  |  |  |  | DFSDM1_DATIN3 |  |  | SAI3_SD_B | USART3_RX |  |  |  |  | FMC_D14/FMC_DA14
57 | PD10 | Output | GPIO_Output | PD10_DEBUG |  |  |  | DFSDM1_CKOUT |  |  | SAI3_FS_B | USART3_CK |  |  |  |  | FMC_D15/FMC_DA15 |  | LTDC_B3
58 | PD11 | Output | GPIO_Output | ALARM |  |  |  | LPTIM2_IN2 | I2C4_SMBA |  |  | USART3_CTS/USART3_NSS |  | QUADSPI_BK1_IO0 | SAI2_SD_A |  | FMC_A16
59 | PD12 | Output | GPIO_Output | PD12_DEBUG |  | LPTIM1_IN1 | TIM4_CH1 | LPTIM2_IN1 | I2C4_SCL |  |  | USART3_DE/USART3_RTS |  | QUADSPI_BK1_IO1 | SAI2_FS_A |  | FMC_A17
60 | PD13 | Output | GPIO_Output | PD13_DEBUG |  | LPTIM1_OUT | TIM4_CH2 |  | I2C4_SDA |  |  |  |  | QUADSPI_BK1_IO3 | SAI2_SCK_A |  | FMC_A18
61 | PD14 | Output | GPIO_Output | PD14_DEBUG |  |  | TIM4_CH3 |  |  |  | SAI3_MCLK_B |  | UART8_CTS |  |  |  | FMC_D0/FMC_DA0
62 | PD15 | Output | GPIO_Output | PD15_DEBUG |  |  | TIM4_CH4 |  |  |  | SAI3_MCLK_A |  | UART8_DE/UART8_RTS |  |  |  | FMC_D1/FMC_DA1
63 | PC6 | I/O | DCMI_D0 |  |  | HRTIM_CHA1 | TIM3_CH1 | TIM8_CH1 | DFSDM1_CKIN3 | I2S2_MCK |  | USART6_TX | SDMMC1_D0DIR | FMC_NWAIT | SDMMC2_D6 |  | SDMMC1_D6 | DCMI_D0 | LTDC_HSYNC
64 | PC7 | I/O | DCMI_D1 |  | DEBUG_TRGIO | HRTIM_CHA2 | TIM3_CH2 | TIM8_CH2 | DFSDM1_DATIN3 |  | I2S3_MCK | USART6_RX | SDMMC1_D123DIR | FMC_NE1 | SDMMC2_D7 | SWPMI1_TX | SDMMC1_D7 | DCMI_D1 | LTDC_G6
65 | PC8 | I/O | DCMI_D2 |  | DEBUG_TRACED1 | HRTIM_CHB1 | TIM3_CH3 | TIM8_CH3 |  |  |  | USART6_CK | UART5_DE/UART5_RTS | FMC_NCE/FMC_NE2 |  | SWPMI1_RX | SDMMC1_D0 | DCMI_D2
66 | PC9 | I/O | I2C3_SDA |  | RCC_MCO_2 |  | TIM3_CH4 | TIM8_CH4 | I2C3_SDA | I2S_CKIN |  |  | UART5_CTS | QUADSPI_BK1_IO0 | LTDC_G3 | SWPMI1_SUSPEND | SDMMC1_D1 | DCMI_D3 | LTDC_B2
67 | PA8 | I/O | I2C3_SCL |  | RCC_MCO_1 | TIM1_CH1 | HRTIM_CHB2 | TIM8_BKIN2 | I2C3_SCL |  |  | USART1_CK |  |  | USB_OTG_FS_SOF | UART7_RX | TIM8_BKIN2_COMP1/TIM8_BKIN2_COMP2 | LTDC_B3 | LTDC_R6
68 | PA9 | Output | GPIO_Output | EN_MUX2 |  | TIM1_CH2 | HRTIM_CHC1 | LPUART1_TX | I2C3_SMBA | I2S2_CK/SPI2_SCK |  | USART1_TX |  |  |  | ETH_TX_ER |  | DCMI_D0 | LTDC_R5
69 | PA10 | Output | GPIO_Output | EN_MUX1 |  | TIM1_CH3 | HRTIM_CHC2 | LPUART1_RX |  |  |  | USART1_RX |  |  | USB_OTG_FS_ID | MDIOS_MDIO | LTDC_B4 | DCMI_D1 | LTDC_B1
70 | PA11 | Output | GPIO_Output | SPI2_NSS |  | TIM1_CH4 | HRTIM_CHD1 | LPUART1_CTS |  | I2S2_WS/SPI2_NSS | UART4_RX | USART1_CTS/USART1_NSS |  | FDCAN1_RX | USB_OTG_FS_DM |  |  |  | LTDC_R4
71 | PA12 | I/O |  |  |  | TIM1_ETR | HRTIM_CHD2 | LPUART1_DE/LPUART1_RTS |  | I2S2_CK/SPI2_SCK | UART4_TX | USART1_DE/USART1_RTS | SAI2_FS_B | FDCAN1_TX | USB_OTG_FS_DP |  |  |  | LTDC_R5
72 | PA13 (JTMS/SWDIO) | I/O | DEBUG_JTMS-SWDIO |  | DEBUG_JTMS-SWDIO
73 | VCAP | Power
74 | VSS | Power
75 | VDD | Power
76 | PA14 (JTCK/SWCLK) | I/O | DEBUG_JTCK-SWCLK |  | DEBUG_JTCK-SWCLK
77 | PA15 (JTDI) | I/O | DEBUG_JTDI |  | DEBUG_JTDI | TIM2_CH1/TIM2_ETR | HRTIM_FLT1 |  | CEC | I2S1_WS/SPI1_NSS | I2S3_WS/SPI3_NSS | SPI6_NSS | UART4_DE/UART4_RTS |  |  | UART7_TX
78 | PC10 | I/O | SPI3_SCK |  |  |  | HRTIM_EEV1 | DFSDM1_CKIN5 |  |  | I2S3_CK/SPI3_SCK | USART3_TX | UART4_TX | QUADSPI_BK1_IO1 |  |  | SDMMC1_D2 | DCMI_D8 | LTDC_R2
79 | PC11 | I/O | SPI3_MISO |  |  |  | HRTIM_FLT2 | DFSDM1_DATIN5 |  |  | I2S3_SDI/SPI3_MISO | USART3_RX | UART4_RX | QUADSPI_BK2_NCS |  |  | SDMMC1_D3 | DCMI_D4
80 | PC12 | Output | GPIO_Output | SPI4_NCS2 | DEBUG_TRACED3 |  | HRTIM_EEV2 |  |  |  | I2S3_SDO/SPI3_MOSI | USART3_CK | UART5_TX |  |  |  | SDMMC1_CK | DCMI_D9
81 | PD0 | Output | GPIO_Output | PD0_DEBUG |  |  |  | DFSDM1_CKIN6 |  |  | SAI3_SCK_A |  | UART4_RX | FDCAN1_RX |  |  | FMC_D2/FMC_DA2
82 | PD1 | Output | GPIO_Output | PD1_DEBUG |  |  |  | DFSDM1_DATIN6 |  |  | SAI3_SD_A |  | UART4_TX | FDCAN1_TX |  |  | FMC_D3/FMC_DA3
83 | PD2 | Output | GPIO_Output | PD2_DEBUG | DEBUG_TRACED2 |  | TIM3_ETR |  |  |  |  |  | UART5_RX |  |  |  | SDMMC1_CMD | DCMI_D11
84 | PD3 | I/O | DCMI_D5 |  |  |  |  | DFSDM1_CKOUT |  | I2S2_CK/SPI2_SCK |  | USART2_CTS/USART2_NSS |  |  |  |  | FMC_CLK | DCMI_D5 | LTDC_G7
85 | PD4 | Output | GPIO_Output | PD4_DEBUG |  |  | HRTIM_FLT3 |  |  |  | SAI3_FS_A | USART2_DE/USART2_RTS |  |  |  |  | FMC_NOE
86 | PD5 | I/O |  |  |  |  | HRTIM_EEV3 |  |  |  |  | USART2_TX |  |  |  |  | FMC_NWE
87 | PD6 | I/O |  |  |  |  | SAI1_D1 | DFSDM1_CKIN4 | DFSDM1_DATIN1 | I2S3_SDO/SPI3_MOSI | SAI1_SD_A | USART2_RX | SAI4_SD_A |  | SAI4_D1 | SDMMC2_CK | FMC_NWAIT | DCMI_D10 | LTDC_B2
88 | PD7 | Output | GPIO_Output | PD7_DEBUG |  |  |  | DFSDM1_DATIN4 |  | I2S1_SDO/SPI1_MOSI | DFSDM1_CKIN1 | USART2_CK |  | SPDIFRX1_IN0 |  | SDMMC2_CMD | FMC_NE1
89 | PB3 (JTDO/TRACESWO) | I/O | DEBUG_JTDO-SWO |  | DEBUG_JTDO-SWO | TIM2_CH2 | HRTIM_FLT4 |  |  | I2S1_CK/SPI1_SCK | I2S3_CK/SPI3_SCK |  | SPI6_SCK | SDMMC2_D2 | CRS_SYNC | UART7_RX
90 | PB4 (NJTRST) | Output | GPIO_Output | FPGA01_PROG |  | TIM16_BKIN | TIM3_CH1 | HRTIM_EEV6 |  | I2S1_SDI/SPI1_MISO | I2S3_SDI/SPI3_MISO | I2S2_WS/SPI2_NSS | SPI6_MISO | SDMMC2_D3 |  | UART7_TX
91 | PB5 | Output | GPIO_Output | FPGA02_PROG |  | TIM17_BKIN | TIM3_CH2 | HRTIM_EEV7 | I2C1_SMBA | I2S1_SDO/SPI1_MOSI | I2C4_SMBA | I2S3_SDO/SPI3_MOSI | SPI6_MOSI | FDCAN2_RX | USB_OTG_HS_ULPI_D7 | ETH_PPS_OUT | FMC_SDCKE1 | DCMI_D10 | UART5_RX
92 | PB6 | I/O | I2C1_SCL |  |  | TIM16_CH1N | TIM4_CH1 | HRTIM_EEV8 | I2C1_SCL | CEC | I2C4_SCL | USART1_TX | LPUART1_TX | FDCAN2_TX | QUADSPI_BK1_NCS | DFSDM1_DATIN5 | FMC_SDNE1 | DCMI_D5 | UART5_TX
93 | PB7 | I/O | DCMI_VSYNC |  |  | TIM17_CH1N | TIM4_CH2 | HRTIM_EEV9 | I2C1_SDA |  | I2C4_SDA | USART1_RX | LPUART1_RX |  |  | DFSDM1_CKIN5 | FMC_NL | DCMI_VSYNC
94 | BOOT0 | Boot
95 | PB8 | I/O |  |  |  | TIM16_CH1 | TIM4_CH3 | DFSDM1_CKIN7 | I2C1_SCL |  | I2C4_SCL | SDMMC1_CKIN | UART4_RX | FDCAN1_RX | SDMMC2_D4 | ETH_TXD3 | SDMMC1_D4 | DCMI_D6 | LTDC_B6
96 | PB9 | I/O | I2C1_SDA |  |  | TIM17_CH1 | TIM4_CH4 | DFSDM1_DATIN7 | I2C1_SDA | I2S2_WS/SPI2_NSS | I2C4_SDA | SDMMC1_CDIR | UART4_TX | FDCAN1_TX | SDMMC2_D5 | I2C4_SMBA | SDMMC1_D5 | DCMI_D7 | LTDC_B7
97 | PE0 | I/O |  |  |  | LPTIM1_ETR | TIM4_ETR | HRTIM_SCIN | LPTIM2_ETR |  |  |  | UART8_RX |  | SAI2_MCLK_A |  | FMC_NBL0 | DCMI_D2
98 | PE1 | I/O | DCMI_D3 |  |  | LPTIM1_IN2 |  | HRTIM_SCOUT |  |  |  |  | UART8_TX |  |  |  | FMC_NBL1 | DCMI_D3
99 | VSS | Power
100 | VDD | Power

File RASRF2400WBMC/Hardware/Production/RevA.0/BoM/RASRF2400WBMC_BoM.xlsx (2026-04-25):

Reference | Qty | Value | DNP | Exclude from BOM | Exclude from Board | Footprint | Manufacturer_Name | Manufacturer_Part_Number | Description
H1,H2,H3,H4 | 4 | MountingHole | DNP |  |  | MountingHole:MountingHole_3.2mm_M3_ISO7380
J7 | 1 | PCIexpress_x8 | DNP |  |  | Connector_PCBEdge:BUS_PCIexpress_x8
TP1,TP2,TP3,TP4,TP5,TP6,TP7,TP9,TP10,TP12,TP16,TP19,TP20,TP22 | 14 | TestPoint | DNP |  |  | TestPoint:TestPoint_THTPad_D1.0mm_Drill0.5mm
TP8 | 1 | TestPoint | DNP |  |  | TestPoint:TestPoint_Pad_1.0x1.0mm
TP11,TP13,TP15,TP17 | 4 | TestPoint | DNP |  |  | TestPoint:TestPoint_Pad_D1.0mm
J1,J2,J3,J4 | 4 | 60312202111527 |  |  |  | JACK_02114307_WRE | Würth Elektronik | 60312202111527 | Conn, WR-MPC3 Power, Male Header, 2-pos, 3.81mm Pitch, SMD, 12A, 250V
J5 | 1 | 1-1478979-0 | DNP |  |  | 114789790 | TE Connectivity | 1-1478979-0 | Conn, SMA, Jack/Female, Straight, PCB Mount, 50Ω, Solder, Through Hole, 18GHz
C159,C160,C161,C162,C163,C164,C165,C166,C194,C195,C196,C197,C198,C199,C200,C201 | 16 | 11pF |  |  |  | Capacitor_SMD:C_0402_1005Metric | Johanson | 500R07S110GV4T | Cap, MLCC, 11pF, 50V, C0G/NP0, 0402, ±2%
IC2 | 1 | 5PB1206NDGK8 |  |  |  | QFN40P300X300X100-21N-D | Renesas Electronics | 5PB1206NDGK8 | IC, Clock Buffer, 1:6 TCXO/LVCMOS, 1.8V, 200MHz, Individual OE, 20-VFQFPN, T&R
Y1 | 1 | 7L-40.000MBS-T |  |  |  | 4-SMD_NoLead_Oscillator | TXC Corporation | 7L-40.000MBS-T | OSC, TCXO, 40MHz, 3.3V, ±2ppm, Clipped Sine, SMD 2.5x2mm, 4-Pin
Y2 | 1 | ABM10-166-12.000MHZ-T3 |  |  |  | ABM10 | Abracon | ABM10-166-12.000MHZ-T3 | Crystal, 12MHz, 8pF, ±10ppm, 125Ω ESR, SMD 2.5x2.0mm, T&R
IC5,IC6 | 2 | ADC3424IRTQR |  |  |  | QFN50P800X800X100-57N-D | Texas Instruments | ADC3424IRTQR | IC, ADC, Quad-Ch, 12-bit, 25–125MSPS, LVDS Output, JESD204B, 56-QFN (8x8mm), T&R
IC1 | 1 | ADP7156ACPZ-3.0-R7 |  |  |  | SON50P300X300X80-11N-D | Analog Devices | ADP7156ACPZ-3.0-R7 | 1.2 A, Ultralow Noise, High PSRR, Fixed Output, RF Linear Regulator
D1 | 1 | APTD1608SECK/J4-PF |  |  |  | LED_SMD:LED_0603_1608Metric | Kingbright | APTD1608SECK/J4-PF | LED, Orange, 605nm, 2.2V, 20mA, 0603, SMD
FB1 | 1 | BLM18BD601BH1D |  |  |  | IND_BLM18_0603_MUR | Murata | BLM18BD601BH1D | Ferrite Bead, 600Ω @100MHz, 500mA, 0.38Ω DCR, 0603, T&R
FB2 | 1 | BLM18SG331TN1B |  |  |  | IND_BLM18_0603_MUR | Murata | BLM18SG331TN1D | Ferrite Bead, 330Ω @100MHz, ±25%, 1.5A, 70mΩ DCR, 0603, T&R
FB3,FB4,FB5,FB6 | 4 | BLM41PG102SN1L |  |  |  | IND_BLM41_1806_MUR | Murata | BLM41PG102SN1L | Ferrite Bead, 1kΩ @100MHz, ±25%, 1.5A, 90mΩ DCR, 1806 (4516 Metric), T&R
Z1 | 1 | BZT52C4V7 |  |  |  | BZT52C4V7 | Diotec | BZT52C4V7 | Zener Diode, 4.7V, ±5%, 200mW, SOD-123, T&R
C171,C173,C176,C178,C206,C208,C211,C213 | 8 | 0.22uF |  |  |  | Capacitor_SMD:C_0603_1608Metric | Yageo | CC0603KRX7R9BB224 | Cap, MLCC, 220nF, 50V, X7R, 0603, ±10%
C77,C78,C100,C101,C123,C124,C146,C147 | 8 | 1.5pF |  |  |  | Capacitor_SMD:C_0402_1005Metric | Murata | GJM1555C1H1R5BB01D | Cap, MLCC, 1.5pF, 50V, C0G/NP0, 0402, ±0.1pF
C52,C54 | 2 | 6pF |  |  |  | Capacitor_SMD:C_0402_1005Metric | Murata | GJM1555C1H6R0CB01D | Cap, MLCC, 6pF, 50V, C0G/NP0, 0402, ±0.25pF
C71,C72,C94,C95,C117,C118,C140,C141 | 8 | 10pF | DNP |  |  | Capacitor_SMD:C_0402_1005Metric | Murata | GRM1555C1H100JZ01D | Cap, MLCC, 10pF, 50V, C0G/NP0, 0402, ±5%
C61,C62,C65,C68,C70,C75,C80,C84,C85,C88,C91,C93,C98,C103,C107,C108,C111,C114,C116,C121,C126,C130,C131,C134,C137,C139,C144,C149 | 28 | 100pF |  |  |  | Capacitor_SMD:C_0402_1005Metric | Murata | GRM1555C1H101JA01D | Cap, MLCC, 100pF, 50V, C0G/NP0, 0402, ±5%
C2 | 1 | 2200pF | DNP |  |  | Capacitor_SMD:C_0402_1005Metric | Murata | GRM1555C1H222JA01D | Cap, MLCC, 2200pF, 50V, C0G/NP0, 0402, ±5%
C3,C81,C104,C127,C150 | 5 | 2200pF |  |  |  | Capacitor_SMD:C_0402_1005Metric | Murata | GRM1555C1H222JA01D | Cap, MLCC, 2200pF, 50V, C0G/NP0, 0402, ±5%
C7,C8,C9,C10 | 4 | 47pF |  |  |  | Capacitor_SMD:C_0402_1005Metric | Murata | GRM1555C1H470FA01D | Cap, MLCC, 47pF, 50V, C0G/NP0, 0402, ±1%
C79,C102,C125,C148 | 4 | 68pF |  |  |  | Capacitor_SMD:C_0402_1005Metric | Murata | GRM1555C1H680JZ01D | Cap, MLCC, 68pF, 50V, C0G/NP0, 0402, ±5%
C55,C59,C60,C63,C73,C82,C83,C86,C96,C105,C106,C109,C119,C128,C129,C132,C142 | 17 | 10uF |  |  |  | Capacitor_SMD:C_0402_1005Metric | Murata | GRM155R61A106ME11D | Cap, MLCC, 10µF, 10V, X5R, 0402, ±20%
C1,C11,C12,C13,C14,C15,C16,C17,C18,C19,C20,C21,C22,C23,C24,C25,C26,C27,C28,C29,C30,C31,C32,C36,C41,C44,C56,C57,C58,C76,C99,C122,C145,C167,C168,C169,C170,C172,C174,C175,C177,C179,C180,C181,C182,C183,C184,C185,C202,C203,C204,C205,C207,C209,C210,C212,C214,C215,C216,C217,C218,C219,C220 | 63 | 100nF |  |  |  | Capacitor_SMD:C_0402_1005Metric | Murata | GRM155R71A104KA01D | Cap, MLCC, 100nF, 10V, X7R, 0402, ±10%
C39,C45,C46,C47,C64,C66,C67,C69,C74,C87,C89,C90,C92,C97,C110,C112,C113,C115,C120,C133,C135,C136,C138,C143 | 24 | 10nF |  |  |  | Capacitor_SMD:C_0402_1005Metric | Murata | GRM155R71H103KA88D | Cap, MLCC, 10nF, 50V, X7R, 0402, ±10%
C33,C34,C35,C38,C42,C48,C50,C51 | 8 | 10uF |  |  |  | Capacitor_SMD:C_0603_1608Metric | Murata | GRM188R61E106MA73D | Cap, MLCC, 10µF, 25V, X5R, 0603, ±10%
C40,C43,C49 | 3 | 1uF |  |  |  | Capacitor_SMD:C_0603_1608Metric | Murata | GRM188R71E105KA12D | Cap, MLCC, 1µF, 25V, X7R, 0603, ±10%
C4,C5,C6,C53 | 4 | 100nF | DNP |  |  | Capacitor_SMD:C_0603_1608Metric | Murata | GRM188R71H104KA93D | Cap, MLCC, 100nF, 50V, X7R, 0603, ±10%
C37,C151,C152,C153,C154,C155,C156,C157,C158,C186,C187,C188,C189,C190,C191,C192,C193 | 17 | 100nF |  |  |  | Capacitor_SMD:C_0603_1608Metric | Murata | GRM188R71H104KA93D | Cap, MLCC, 100nF, 50V, X7R, 0603, ±10%
U5,U7,U9,U11 | 4 | HHM1902B1 |  |  |  | HHM-4_1P0X0P5 | TDK Corporation | HHM1902B1 | Balun, Multilayer, 2.4–2.5GHz, 50/50Ω, 0.8dB IL, SMD 0402
U2 | 1 | LD1117DT33TR |  |  |  | DPAK456P1010X240-3N | STMicroelectronics | LD1117DT33TR | IC, LDO Regulator, 3.3V, 800mA, Fixed, DPAK (TO-252), T&R
U4,U6,U8,U10 | 4 | MAX2831ETM+T |  |  |  | 21-0144_T4877&plus_4_MXM | Analog Devices (Maxim Integrated) | MAX2831ETM+T | IC, RF Transceiver, 802.11b/g, 2.4–2.5GHz, 21dBm, 48-TQFN, T&R
Q2 | 1 | MMBT3904LT1G |  |  |  | SOT96P237X111-3N | Onsemi | MMBT3904LT1G | These Devices are Pb-Free, Halogen Free/BFR Free and are RoHS Compliant; S Prefix for Automotive and Other Applications Requiring Unique Site and Control Change Requirements; AEC-Q101 Qualified and PPAP Capable
R9,R23,R24,R26,R27,R29,R30,R31,R32,R33,R34,R95,R125,R126 | 14 | 10K |  |  |  | Resistor_SMD:R_0402_1005Metric | Yageo | RC0402FR-0710KL | Res, Thick Film, 10kΩ, 1/16W, 0402, ±1%
R35,R36,R44,R45,R53,R54,R62,R63 | 8 | 10K | DNP |  |  | Resistor_SMD:R_0402_1005Metric | Yageo | RC0402FR-0710KL | Res, Thick Film, 10kΩ, 1/16W, 0402, ±1%
R16,R17 | 2 | 4K7 | DNP |  |  | Resistor_SMD:R_0402_1005Metric | Yageo | RC0402FR-074K7L | Res, Thick Film, 4.7kΩ, 1/16W, 0402, ±1%
R18,R19,R20,R21,R127 | 5 | 100K |  |  |  | Resistor_SMD:R_0402_1005Metric | Yageo | RC0402FR-07100KL | Res, Thick Film, 100kΩ, 1/16W, 0402, ±1%
R28,R71,R72,R73,R74,R75,R76,R77,R78,R98,R99,R100,R101,R102,R103,R104,R105 | 17 | 1K |  |  |  | Resistor_SMD:R_0603_1608Metric | Yageo | RC0603FR-071KL | Res, Thick Film, 1kΩ, 1/10W, 0603, ±1%
R2 | 1 | 10K | DNP |  |  | Resistor_SMD:R_0603_1608Metric | Yageo | RC0603FR-0710KL | Res, Thick Film, 10kΩ, 1/10W, 0603, ±1%
R3,R8 | 2 | 10K |  |  |  | Resistor_SMD:R_0603_1608Metric | Yageo | RC0603FR-0710KL | Res, Thick Film, 10kΩ, 1/10W, 0603, ±1%
R10,R11,R12,R13,R14,R15 | 6 | 33 |  |  |  | Resistor_SMD:R_0603_1608Metric | Yageo | RC0603FR-0733RL | Res, Thick Film, 33Ω, 1/10W, 0603, ±1%
R4 | 1 | 100K |  |  |  | Resistor_SMD:R_0603_1608Metric | Yageo | RC0603FR-07100KL | Res, Thick Film, 100kΩ, 1/10W, 0603, ±1%
R22 | 1 | 100K | DNP |  |  | Resistor_SMD:R_0603_1608Metric | Yageo | RC0603FR-07100KL | Res, Thick Film, 100kΩ, 1/10W, 0603, ±1%
R39,R48,R57,R66 | 4 | 100 |  |  |  | Resistor_SMD:R_0603_1608Metric | Yageo | RC0603FR-07100RL | Res, Thick Film, 100Ω, 1/10W, 0603, ±1%
R87,R88,R89,R90,R91,R92,R93,R94,R114,R115,R116,R117,R118,R119,R120,R121 | 16 | 150 |  |  |  | Resistor_SMD:R_0603_1608Metric | Yageo | RC0603FR-07150RL | Res, Thick Film, 150Ω, 1/10W, 0603, ±1%
R42,R51,R60,R69 | 4 | 750 |  |  |  | Resistor_SMD:R_0603_1608Metric | Yageo | RC0603FR-07750RL | Res, Thick Film, 750Ω, 1/10W, 0603, ±1%
R43,R52,R61,R70 | 4 | 1.2K |  |  |  | Resistor_SMD:R_0603_1608Metric | Yageo | RC0603FR-071K2L | Res, Thick Film, 1.2kΩ, 1/10W, 0603, ±1%
R40,R41,R49,R50,R58,R59,R67,R68,R96,R123 | 10 | 49.9 |  |  |  | Resistor_SMD:R_0603_1608Metric | Yageo | RC0603FR-0749R9L | Res, Thick Film, 49.9Ω, 1/10W, 0603, ±1%
R5 | 1 | 68.1K |  |  |  | Resistor_SMD:R_0603_1608Metric | Yageo | RC0603FR-0768K1L | Res, Thick Film, 68.1kΩ, 1/10W, 0603, ±1%
L1,L2,L3,L4,L5,L6,L7,L8 | 8 | 0 |  |  |  | Inductor_SMD:L_0603_1608Metric | Yageo | RC0603JR-070RL | Res, Thick Film, 0Ω, 1/10W, 0603, Jumper
R1 | 1 | 0 | DNP |  |  | Resistor_SMD:R_0603_1608Metric | Yageo | RC0603JR-070RL | Res, Thick Film, 0Ω, 1/10W, 0603, Jumper
R6,R7,R25,R37,R38,R46,R47,R55,R56,R64,R65,R79,R80,R81,R82,R83,R84,R85,R86,R97,R106,R107,R108,R109,R110,R111,R112,R113,R124 | 29 | 0 |  |  |  | Resistor_SMD:R_0603_1608Metric | Yageo | RC0603JR-070RL | Res, Thick Film, 0Ω, 1/10W, 0603, Jumper
U3 | 1 | SN74AXC4T774RSVR |  |  |  | RSV0016A | Texas Instruments | SN74AXC4T774RSVR | IC, Level Shifter, 4-bit Dual-Supply Bus Transceiver, Bidirectional, Independent Dir Control, Tri-State, 16-UQFN (1.8x2.6mm), T&R
IC3 | 1 | STM32C031K6U6 |  |  |  | QFN50P500X500X60-33N-D | STMicroelectronics | STM32C031K6U6 | IC, MCU, 32-bit ARM Cortex-M0+, 48MHz, 32KB Flash, 12KB RAM, 2x USART, SPI, I2C, ADC, 2–3.6V, 32-UFQFPN
U1 | 1 | TLV9001DBVR |  |  |  | Package_TO_SOT_SMD:SOT-23-5 | Texas Instruments | TLV9001DBVR | R-R I/O, 1MHz, 60µA, 3.3V
J6 | 1 | Conn_01x04_Pin |  |  |  | Connector_PinSocket_2.54mm:PinSocket_1x04_P2.54mm_Vertical | Samtec | TSW-104-07-G-S | Conn, Header, Male, 1x4, 2.54mm Pitch, THT, Vertical, Unshrouded

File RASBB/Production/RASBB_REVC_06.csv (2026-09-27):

Reference | Value | Footprint | DNP | LCSC Part # | Mfr. Part # | Description
C1,C2,C19,C130,C167,C171 | 1uF | Capacitor_SMD:C_0402_1005Metric |  | C3889771 | 0402X105M160CT | 16V 1uF X5R ±20% 0402 Multilayer Ceramic Capacitors MLCC - SMD/SMT ROHS
C3,C7 | 10nF | Capacitor_SMD:C_0603_1608Metric |  | C6119837 | CGA0603X7R103K101JT | ±10% X7R 10nF 100V 0603
C4 | 10uF, 100V | Capacitor_SMD:C_1206_3216Metric |  | C6872041 | C3216X6S2A106K160AC | 100V 10uF X6S ±10% 1206 Multilayer Ceramic Capacitors MLCC - SMD/SMT ROHS
C5,C6 | 4.7uF | Capacitor_SMD:C_1206_3216Metric |  | C2997285 | GRM31CZ72A475KE11L | 100V 4.7uF X7R ±10% 1206 Multilayer Ceramic Capacitors MLCC - SMD/SMT ROHS
C8 | 22pF | Capacitor_SMD:C_0402_1005Metric |  | C2175872 | CC0402JRNPO7BN220 | 16V 22pF NP0 ±5% 0402 Multilayer Ceramic Capacitors MLCC - SMD/SMT ROHS
C9 | 4.7nF | Capacitor_SMD:C_0402_1005Metric |  | C1852867 | CC0402KRX7R6BB472 | 10V 4.7nF X7R ±10% 0402 Multilayer Ceramic Capacitors MLCC - SMD/SMT ROHS
C10,C16,C18,C27,C28,C31,C33,C34,C35,C36,C37,C55,C58,C59,C60,C61,C63,C64,C65,C67,C68,C70,C71,C76,C77,C84,C95,C99,C100,C107,C118,C122,C123,C124,C129,C131,C132,C133,C134,C135,C136,C137,C138,C144,C148,C152,C154,C164,C169,C172,C173,C174,C202,C204,C237,C240,C258,C259,C260,C268,C270,C276,C283,C286,C288,C309,C318,C319,C320,C321,C323,C324,C342,C352,C353,C356,C357,C358,C359,C360,C361,C362,C363,C364 | 100nF | Capacitor_SMD:C_0402_1005Metric |  | C152814 | 0402B104K500CT | 50V 100nF X7R ±10% 0402 Multilayer Ceramic Capacitors MLCC - SMD/SMT ROHS
C11,C38,C39,C40,C50,C51,C126,C150,C151 | 10nF | Capacitor_SMD:C_0402_1005Metric |  | C301927 | 0402B103K500CT | 50V 10nF X7R ±10% 0402 Multilayer Ceramic Capacitors MLCC - SMD/SMT ROHS
C12,C13,C14,C15,C21,C22,C23,C24,C25,C26 | 10uF | Capacitor_SMD:C_1206_3216Metric |  | C531431 | CGA5L1X7R1H106KT0Y0N | 50V 10uF X7R ±10% 1206 Multilayer Ceramic Capacitors MLCC - SMD/SMT ROHS
C17 | 33uF | RASBB:EEE0JA152UAP |  | C178581 | EEE-FP1V330AP | Aluminum Electrolytic Capacitors - SMD 33UF 35V ELECT FP SMD
C20,C69,C72,C206,C208,C210,C211,C212,C213,C214,C215,C216,C217,C223,C227,C228,C246,C247,C249,C250,C266,C267,C290,C292,C294,C295,C296,C297,C298,C299,C300,C301,C307,C311,C312,C330,C331,C333,C334,C350,C351 | 4.7uF | Capacitor_SMD:C_0402_1005Metric |  | C77004 | GRM155R61A475KEAAD | 10V 4.7uF X5R ±10% 0402 Multilayer Ceramic Capacitors MLCC - SMD/SMT ROHS
C29,C98,C115,C121,C127,C128,C175,C186,C279,C365,C366 | 4.7uF | Capacitor_SMD:C_0603_1608Metric |  | C7281848 | GMK107BBJ475KA-T | 35V 4.7uF X5R ±10% 0603 Multilayer Ceramic Capacitors MLCC - SMD/SMT ROHS
C30,C32,C75,C89,C92,C112,C153,C182,C185,C189,C190,C191,C193,C194,C196,C197,C200,C201,C203,C205,C207,C209,C222,C224,C225,C229,C230,C231,C232,C233,C234,C235,C236,C238,C239,C241,C242,C243,C244,C245,C251,C252,C253,C254,C255,C257,C261,C262,C263,C264,C265,C269,C273,C274,C275,C277,C278,C280,C281,C284,C285,C287,C289,C291,C293,C306,C308,C313,C314,C315,C316,C326,C327,C328,C329,C335,C336,C337,C338,C346,C347,C348,C349 | 470nF | Capacitor_SMD:C_0402_1005Metric |  | C471404 | GRM155R71C474KE01D | 16V 470nF X7R ±10% 0402 Multilayer Ceramic Capacitors MLCC - SMD/SMT ROHS
C41 | 10pF | Capacitor_SMD:C_0402_1005Metric |  | C2182752 | C0402C100J4GAC7867 | 16V 10pF C0G ±5% 0402 Multilayer Ceramic Capacitors MLCC - SMD/SMT ROHS
C42,C46,C49,C52,C62,C170,C184,C187,C188,C192,C221,C305 | 47uF | Capacitor_SMD:C_0805_2012Metric |  | C124129 | GRM21BR61A476ME15L | 10V 47uF X5R ±20% 0805 Multilayer Ceramic Capacitors MLCC - SMD/SMT ROHS
C43 | 5.1pF | Capacitor_SMD:C_0402_1005Metric |  | C3855079 | GRM1555C1E5R1CA01D | 25V 5.1pF C0G 0402 Multilayer Ceramic Capacitors MLCC - SMD/SMT ROHS
C44,C45,C47,C48,C53,C54,C56,C57,C125,C256 | 22uF | Capacitor_SMD:C_0603_1608Metric |  | C6776252 | 0603YD226MAT2A | 16V 22uF X5R ±20% 0603 Multilayer Ceramic Capacitors MLCC - SMD/SMT ROHS
C66 | 470pF | Capacitor_SMD:C_0402_1005Metric |  | C526993 | CC0402JRNPO7BN471 | 16V 470pF NP0 ±5% 0402 Multilayer Ceramic Capacitors MLCC - SMD/SMT ROHS
C73 | 100nF | Capacitor_SMD:C_2220_5750Metric |  | C5290327 | FV55X104K202EGG | 2kV 100nF X7R ±10% 2220 Multilayer Ceramic Capacitors MLCC - SMD/SMT ROHS
C74,C183,C322,J14,SW1,SW2,TP1,TP2,TP3,TP4,TP5,TP6,TP7,TP8,TP9,TP10,TP11,TP12,TP13,TP14,TP15,TP16,TP17,TP18,TP19,TP20,TP21,TP22,TP23,TP24,TP25 | 125M,1nF,435451019820,SYNC_40MHZ,TestPoint | Capacitor_SMD:C_1206_3216Metric,RASBB:435451019820,RASBB:J_Wurth_WR-UMRF_636101112001,TestPoint:TestPoint_Pad_D1.0mm | DNP |  | 435451019820,636101112001 | CAP, CER, 1nF, 2kV, 10%, X7R, 1210,PCB Receptacle with 3 Pads,SMT Washable Tact Switch 4.1 x 2.8 mm,test point
C78,C79,C80,C81,C82,C83,C85,C86,C87,C88,C90,C91,C93,C94,C96,C97,C101,C102,C103,C104,C105,C106,C108,C109,C110,C111,C113,C114,C116,C117,C119,C120,C162,C317,C339 | 47nF | Capacitor_SMD:C_0402_1005Metric |  | C2178375 | C0402C473J8RAC7867 | 10V 47nF X7R ±5% 0402 Multilayer Ceramic Capacitors MLCC - SMD/SMT ROHS
C139,C140,C145,C149 | 20p | Capacitor_SMD:C_0402_1005Metric |  | C123468 | 0402N200J500CT | 50V 20pF NP0 ±5% 0402 Multilayer Ceramic Capacitors MLCC - SMD/SMT ROHS
C141,C143 | 2.2uF | Capacitor_SMD:C_0402_1005Metric |  | C3905586 | 0402X225M160CT | 16V 2.2uF X5R ±20% 0402 Multilayer Ceramic Capacitors MLCC - SMD/SMT ROHS
C142,C146,C147 | 10uF | Capacitor_SMD:C_0402_1005Metric |  | C2992625 | 0402X106M100CT | 10V 10uF X5R ±20% 0402 Multilayer Ceramic Capacitors MLCC - SMD/SMT ROHS
C155 | 0.8pF | Capacitor_SMD:C_0402_1005Metric |  | C396870 | RF15N0R8B500CT | 50V 0.8pF NP0 0402 Multilayer Ceramic Capacitors MLCC - SMD/SMT ROHS
C156,C158 | 1.2pF | Capacitor_SMD:C_0402_1005Metric |  | C301969 | 0402N1R2C500CT | 50V 1.2pF NP0 0402 Multilayer Ceramic Capacitors MLCC - SMD/SMT ROHS
C157 | 0.5pF | Capacitor_SMD:C_0402_1005Metric |  | C2918554 | RT15N0R5B500CT | 50V 0.5pF NP0 0402 Multilayer Ceramic Capacitors MLCC - SMD/SMT ROHS
C159,C163 | 100pF | Capacitor_SMD:C_0402_1005Metric |  | C387967 | 0402N101G500CT | 50V 100pF NP0 ±2% 0402 Multilayer Ceramic Capacitors MLCC - SMD/SMT ROHS
C160,C161,C166 | 10uF | Capacitor_SMD:C_0603_1608Metric |  | C4555498 | 0603X106M250CT | 25V 10uF X5R ±20% 0603 Multilayer Ceramic Capacitors MLCC - SMD/SMT ROHS
C165 | UUD1A221MCL1GS | RASBB:CAPAE660X800N |  | C445275 | UUD1A221MCL1GS | 220uF 10V 280mA@100kHz 340mΩ@100kHz ±20% SMD,D6.3xL7.7mm Aluminum Electrolytic Capacitors - SMD ROHS
C168,C176 | 10p | Capacitor_SMD:C_0402_1005Metric |  | C301961 | 0402N100J500CT | 10pF 50V C0G/NP0 ±5% 0402 Multilayer Ceramic Capacitors MLCC - SMD/SMT ROHS
C177,C178,C179,C180 | 10p/50V | Capacitor_SMD:C_0603_1608Metric |  | C152928 | 0603N100J500CT | 10pF 50V C0G/NP0 ±5% 0603Multilayer Ceramic Capacitors MLCC - SMD/SMT ROHS
C181 | 1nF | Capacitor_SMD:C_1206_3216Metric |  | C303946 | 1206B102K202CT | 2kV 1nF X7R ±10% 1206 Multilayer Ceramic Capacitors MLCC - SMD/SMT ROHS
C195,C198,C199,C218,C219,C220,C226,C248,C282,C302,C303,C304,C310,C332 | 100uF | Capacitor_SMD:C_1206_3216Metric |  | C883598 | GRM31CR61A107MEA8L | 10V 100uF X5R ±20% 1206 Multilayer Ceramic Capacitors MLCC - SMD/SMT ROHS
C271,C272 | 2200pF | Capacitor_SMD:C_0402_1005Metric |  | C1531 | 0402B222K500NT | Cap, MLCC, 2200pF, 50V, X7R, 0402, ±5%
C354,C355 | 2.2uF | Capacitor_SMD:C_0805_2012Metric |  | C2918681 | 0805B225K500CT | 50V 2.2uF X7R ±10% 0805 Multilayer Ceramic Capacitors MLCC - SMD/SMT ROHS
D1 | SDT5A60SA-13 | RASBB:SDT5A60SA13 |  | C3024223 | SDT5A60SA-13 | Diode 60 V 5A Surface Mount SMA
D2,D3 | VSSAF5L45HM3_A_H | RASBB:SODFL5226X100N |  | C6000165 | VSSAF5L45HM3_A/H | Schottky Diodes & Rectifiers TMBS 45V Vrrm eSMP AEC-Q101 Qualified
D4,D5,D26 | DF1501S-T | RASBB:DF1501ST |  | C155338 | DF1501S-T | 50A 1.1V@1.5A 1.5A 100V DF-S Bridge Rectifiers ROHS
D6 | S210_R1_00001 | Diode_SMD:D_SMB |  | C391676 | S210_R1_00001 | 2A Independent Type 100V 660mV@2A SMB(DO-214AA) Diodes - General Purpose ROHS
D7,D13,D14,D15,D16 | A-SP192YR6C-C01-4T | LED_SMD:LED_0603_1608Metric |  | C5355433 | A-SP192YR6C-C01-4T | 5mA Colorless Transparent Lens 72mcd 616nm~624nm -40℃~+85℃ Positive Stick Red 120° 60mW 1.7V~2.2V 0603 LED Indication - Discrete ROHS
D8,D20,D21,D22,D25 | A-SP192DGHC-C01-4T | LED_SMD:LED_0603_1608Metric |  | C19171301 | A-SP192DGHC-C01-4T | 225mcd~450mcd Colorless Transparent Lens -40℃~+85℃ Positive Stick 520nm~535nm Green 120° 70mW 2.4V~3V 0603 LED Indication - Discrete ROHS
D9,D23,D24 | A-SP192GS1D-C01-4T | LED_SMD:LED_0603_1608Metric |  | C5355434 | A-SP192GS1D-C01-4T | 5mA 285mcd Frosted Orange Lens -40℃~+85℃ 592nm~600nm Positive Stick Orange 130° 20mW 2.4V~3V 0603 LED Indication - Discrete ROHS
D10 | D5V0F4U6SO-7 | RASBB:SOT95P285X140-6N |  | C445539 | D5V0F4U6SO-7 | 3A@8/20us 12V 6V Unidirectional 5.5V SOT-26 ESD and Surge Protection (TVS/ESD) ROHS
D11,D12 | DT2042-04SO-7 | RASBB:SOT95P285X140-6N |  | C2841428 | DT2042-04SO-7 | Diodes Inc DT2042-04SO-7 Quad Uni-Directional TVS Diode Array, 300mW peak, 6-Pin SOT-26
D27 | SMAJ33A | RASBB:DIOM5026X229N |  | C223988 | SMAJ33A | 33V 400W 53.3V 7.5A SMA(DO-214AC) Uni-Directional TVS Voltage Suppressors / Diodes ROHS
F1 | Polyfuse 1.5A | RASBB:BSMD1812 |  | C883154 | BSMD1812-150-33V | PTC RESET FUSE 33V 1.5A 1812
F2 | Polyfuse 2A | RASBB:BSMD1812 |  | C960026 | BSMD1812-200-30V | PTC RESET FUSE 30V 2A 1812
FB1,FB2,FB3 | BLM15BD601SH1D | RASBB:NFZ15SG152SN10B |  | C710334 | BLM15BD601SH1D | BLM15_H1D Series EMI Suppression Filter 600+/-25% at 100MHz 200mA @85
IC1 | RT6365GSP | RASBB:SOIC127P600X175-9N |  | C3024482 | RT6365GSP | Switching Voltage Regulators 60VIN, 5A, Asynchronous Step-Down Converter with Low Quiescent Current
IC2,IC4 | TPS56528DDAR | RASBB:SOIC127P600X170-9N |  | C138716 | TPS56528DDAR | 4.5V to 18V Input, 5-A Synchronous Step-Down Converter with Advanced Eco-mode&#153;
IC3 | TPS563201DDCR | RASBB:SOT95P280X110-6N |  | C116592 | TPS563201DDCR | 4.5 V to 17 V input, 3 A output, synchronous step-down converter in Eco-mode
IC5,IC7 | S25FL128LAGMFI010 | RASBB:SOIC127P800X216-8N |  | C2959152 | S25FL128LAGMFI010 | CYPRESS SEMICONDUCTOR - S25FL128LAGMFI010 - FLASH MEMORY, 128MBIT, 133MHZ, SOIC-8
IC6,IC8 | TS3A5018DBQR | RASBB:SOP64P600X175-16N |  | C202285 | TS3A5018DBQR | Analog SW Quad SPDT 3.6V 16-Pin SSOP Texas Instruments TS3A5018DBQR, Analogue SPDT Switch Quad SPDT, 3 V, 16-Pin SSOP
IC9,IC10 | MT41K128M16JT-107:K | RASBB:BGA96C80P9X16_800X1400X120 |  | C2841151 | MT41K128M16JT-107:K | IC DRAM 2GBIT PAR 96FBGA
IC11 | TPD12S016PWR | RASBB:SOP65P640X120-24N |  | C201665 | TPD12S016PWR | Texas Instruments,TPD12S016PWR,IC,HDMI TPD12S016PWR, HDMI Interface 12-channel HDMI 4.5
IC12 | STM32H743VGT6 | RASBB:QFP50P1600X1600X160-100N |  | C730183 | STM32H743VGT6 | STM32H743VGT6
IC13 | SX1280IMLTRT | RASBB:QFN50P400X400X100-25N-D |  | C125969 | SX1280IMLTRT | RF Transceiver Long range 2.4 GHz Wireless Transceiver
IC14 | LAN8742AI-CZ-TR | RASBB:QFN50P400X400X100-25N-D |  | C621425 | LAN8742AI-CZ-TR | VQFN-24-EP(4x4) Buffers, Drivers, Receivers, Transceivers ROHS
IC15 | DS90LV028AQDQFRQ1 | RASBB:SON50P200X200X80-8N |  | C2868409 | DS90LV028AQDQFRQ1 | Dual LVDS receiver, 8-WSON 2x2
J1 | DC_12V_IN | RASBB:CUI_PJ-002AH-SMT-TR |  | C22434687 | PJ-002AH-SMT-TR | SMD DC Power Connectors ROHS
J2 | ETH_1G | RASBB:JK00229NL |  | C5149194 | HR911196AE | Plugin Ethernet Connectors / Modular Connectors (RJ45 RJ11) ROHS
J3 | HDMI | RASBB:HDMI-001A |  | C41347845 | HDMI-001A | Push-Pull HDMI Connectors ROHS
J4 | FRONTEND | RASBB:SAMTEC_PCIE-098-02-X-D-EMS3 |  | C5711253 | X3157WS-98-9TV30 | Plugin PCI / PCIe Connector ROHS
J5 | ICON | RASBB:CON50_1X50_DUTB_HRS_HIR |  | C597991 | FH12-50S-0.5SVA(54) | CONN FFC FPC 50POS 0.5mm VERTICAL - 1 SIDED CNT SMD
J6 | Conn_01x03 | Connector_PinHeader_2.54mm:PinHeader_1x03_P2.54mm_Vertical |  | C2937625 | PZ254V-11-03P | CONN HEADER 3POS 2.54mm SINGLE ROW TH
J7 | USB_UART | Connector_USB:USB_C_Receptacle_Palconn_UTC16-G |  | C2765186 | TYPE-C 16PIN 2MD(073) | USB Full-Featured Type-C Receptacle connector
J8,J10 | STM32_DEBUG,STM32_JTAG | Connector_PinHeader_1.27mm:PinHeader_2x05_P1.27mm_Vertical_SMD |  | C41370773 | ZX-PZ1.27-2-5PWZ | https://www.lcsc.com/datasheet/lcsc_datasheet_2408280907_Megastar-ZX-PZ1-27-2-5PWZ_C41370773.pdf
J9 | ALARM_OUT | RASBB:SHDRRA2W80P0X350_1X2_1050X920X750P |  | C441171 | KF2EDGR-3.5-2P | Bend -40℃~+105℃ 1 3.5mm 300V 10A 2 1x2P Green Receptacle-Close Push-Pull,P=3.5mm Pluggable System Terminal Block ROHS
J11 | LORA_ANT | Connector_Coaxial:U.FL_Hirose_U.FL-R-SMT-1_Vertical |  | C22418213 | CONUFL001-SMD-T or similar | coaxial connector (BNC, SMA, SMB, SMC, Cinch/RCA, LEMO, ...)
J12 | AUDIO | RASBB:FC68128 |  | C7501803 | HC-PJ-313E8-B-SMT | -25℃~+70℃ 3.5mm Headphone Jack 30V Nickel 500mA Phosphor Bronze SMD Audio Connectors ROHS
J13,J15 | FPGA1_JTAG,FPGA2_JTAG | Connector_PinHeader_1.27mm:PinHeader_2x03_P1.27mm_Vertical_SMD |  | C41370771 | ZX-PZ1.27-2-3PWZ | Gold 1A Standing paste Policy 1mm 6P 4mm -40℃~+105℃ 1.27mm Brass Double Row Black 2x3P 1.27mm SMD,P=1.27mm Pin Headers ROHS
J16,J17,J18,J20 | FE_3V3_MEAS,FPGA1_CLK_OUT,FPGA2_CLK_OUT,PWM_DAC_OUT | Connector_PinHeader_2.54mm:PinHeader_1x02_P2.54mm_Vertical |  | C492401 | PZ254V-11-02P | Generic connector, single row, 01x02, script generated
J19 | ETH_100M_POE | RASBB:HC-WK88-H16-DB |  | C7501824 | HC-WK88-H16-DB | CONN MOD JACK RJ45 TH R/A SHIELDED
L1 | 10uH | RASBB:0630CDMCDDS-100MC |  | C2595948 | 0630CDMCDDS-100MC | 4.5A 10uH ±20% 4.6A 2726 Power Inductors ROHS
L2 | 15uH | RASBB:SMDRS6028-150N |  | C163563 | SMDRS6028-150N | 1A 15uH Shielded inductor ±30% 1A SMD Power Inductors ROHS
L3 | 360nH | RASBB:INDPM109103X400N |  | C845083 | IHLP4040DZERR36M01 | 31.5A 360nH ±20% 60A SMD,10.8x10.2mm Power Inductors ROHS
L4,L5,L6 | 2.2uH | RASBB:IND_IHLP-2525CZ_VIS |  | C845037 | IHLP2525EZER2R2M01 | 10A 2.2uH ±20% 10A SMD,6.5x6.9mm Power Inductors ROHS
L7 | 2.2uH | Inductor_SMD:L_1206_3216Metric |  | C486337 | MGFL3216F2R2MT-LF | 1.3A 2.2uH ±20% 150mΩ 1206 Inductors (SMD) ROHS
L8,L11 | BLM41PG102SN1L | RASBB:IND_BLM41_1806_MUR-M |  | C88999 | BLM41PG102SN1L | 90mΩ ±25% 1kΩ@100MHz 1806 Ferrite Beads ROHS
L9 | 3nH | Inductor_SMD:L_0402_1005Metric |  | C433005 | MHQ1005P3N0BT000 | 3nH 800mA ±0.1nH 0402 High Frequency / RF Inductors - Surface Mount ROHS
L10 | 2.5nH | Inductor_SMD:L_0402_1005Metric |  | C317668 | FHW0402UC2N5KST | 640mA 2.5nH ±10% 120mΩ 0402 Inductors (SMD) ROHS
Q1 | DMN6075S | Package_TO_SOT_SMD:SOT-23 |  | C5122015 | DMN6075S | 60V 3A 350mW 125mΩ@4.5V,3A 500mV@250uA SOT-23 MOSFETs ROHS
R1,R2,R3,R4,R6,R7,R8,R11,R12,R13,R14,R15,R16,R22,R72,R73,R139,R140,R141,R142,R152,R153,R154,R155,R157,R158,R159,R160,R161,R162,R163,R166,R167 | 49.9 | Resistor_SMD:R_0402_1005Metric |  | C4229190 | RMCF0402FT49R9 | 62.5mW Thick Film Resistors 50V ±100ppm/℃ ±1% 49.9Ω 0402 Chip Resistor - Surface Mount ROHS
R5,R9,R10,R53,R54,R55,R56,R57,R58,R59,R60,R61,R62,R74,R76,R85,R86,R91,R92,R101,R103,R107,R114,R115,R116,R117,R118,R119,R120,R196,R197,R198,R199,R204,R207 | 4K7 | Resistor_SMD:R_0402_1005Metric |  | C163826 | WR04X4701FTL | 62.5mW Thick Film Resistors 50V ±100ppm/℃ ±1% 4.7kΩ 0402 Chip Resistor - Surface Mount ROHS
R17,R18,R19,R20,R23,R24,R99,R100 | 22 | Resistor_SMD:R_0402_1005Metric |  | C163821 | WR04X22R0FTL | 62.5mW Thick Film Resistors 50V ±100ppm/℃ ±1% 22Ω 0402 Chip Resistor - Surface Mount ROHS
R21,R63,R64,R65,R66,R68,R69,R70,R71,R87,R93,R168,R169,R170,R171,R172,R173,R174,R175,R176,R177,R178,R179,R180,R181,R182,R183,R184,R187,R188,R189,R190 | 100 | Resistor_SMD:R_0402_1005Metric |  | C163808 | WR04X1000FTL | 62.5mW Thick Film Resistors 50V ±100ppm/℃ ±1% 100Ω 0402 Chip Resistor - Surface Mount ROHS
R25 | 24.9K | Resistor_SMD:R_1206_3216Metric |  | C171074 | WR12X2492FTL | 250mW Thick Film Resistors 200V ±100ppm/℃ ±1% 24.9kΩ 1206 Chip Resistor - Surface Mount ROHS
R26 | 249K | Resistor_SMD:R_0805_2012Metric |  | C170853 | WR08X2493FTL | 125mW Thick Film Resistors 150V ±100ppm/℃ ±1% 249kΩ 0805 Chip Resistor - Surface Mount ROHS
R27,R123 | 51K | Resistor_SMD:R_0603_1608Metric |  | C163933 | WR06X5102FTL | 100mW Thick Film Resistors 75V ±100ppm/℃ ±1% 51kΩ 0603 Chip Resistor - Surface Mount ROHS
R28 | 590K | Resistor_SMD:R_0402_1005Metric |  | C172103 | WR04X5903FTL | 62.5mW Thick Film Resistors 50V ±100ppm/℃ ±1% 590kΩ 0402 Chip Resistor - Surface Mount ROHS
R29,R30 | 18K | Resistor_SMD:R_0402_1005Metric |  | C168206 | WR04X1802FTL | 62.5mW Thick Film Resistors 50V ±100ppm/℃ ±1% 18kΩ 0402 Chip Resistor - Surface Mount ROHS
R31 | 120K | Resistor_SMD:R_0402_1005Metric |  | C137924 | RC0402JR-07120KL | 62.5mW Thick Film Resistors 50V ±200ppm/℃ ±5% 120kΩ 0402 Chip Resistor - Surface Mount ROHS
R32,R44 | 3.3 | Resistor_SMD:R_0402_1005Metric |  | C4170964 | CRCW04023R30FKEDC | 62.5mW Thick Film Resistors 50V ±200ppm/℃ ±1% 3.3Ω 0402 Chip Resistor - Surface Mount ROHS
R33 | 180K | Resistor_SMD:R_0402_1005Metric |  | C168207 | WR04X1803FTL | 62.5mW Thick Film Resistors 50V ±100ppm/℃ ±1% 180kΩ 0402 Chip Resistor - Surface Mount ROHS
R34 | 12K | Resistor_SMD:R_0402_1005Metric |  | C2991361 | SR04X1202FTL | 62.5mW Thick Film Resistors 50V ±100ppm/℃ ±1% 12kΩ 0402 Chip Resistor - Surface Mount ROHS
R35,R37,R41,R42,R43,R49,R125,R126 | 100K | Resistor_SMD:R_0402_1005Metric | DNP | C60491 | RC0402FR-07100KL | 62.5mW Thick Film Resistors 50V ±100ppm/℃ ±1% 100kΩ 0402 Chip Resistor - Surface Mount ROHS
R36 | 220K | Resistor_SMD:R_0402_1005Metric |  | C25767 | 0402WGF2203TCE | 62.5mW Thick Film Resistors 50V ±100ppm/℃ ±1% 220kΩ 0402 Chip Resistor - Surface Mount ROHS
R38 | 5.49K | Resistor_SMD:R_0402_1005Metric |  | C2092200 | CRCW04025K49FKED | 62.5mW Thick Film Resistors 50V ±100ppm/℃ ±1% 5.49kΩ 0402 Chip Resistor - Surface Mount ROHS
R39 | 2.32K | Resistor_SMD:R_0402_1005Metric |  | C2091739 | CRCW04022K32FKED | 62.5mW Thick Film Resistors 50V ±100ppm/℃ ±1% 2.32kΩ 0402 Chip Resistor - Surface Mount ROHS
R40 | 3.48K | Resistor_SMD:R_0402_1005Metric |  | C4336043 | CRCW04023K48FKED | 62.5mW Thick Film Resistors 50V ±100ppm/℃ ±1% 3.48kΩ 0402 Chip Resistor - Surface Mount ROHS
R45 | 11K | Resistor_SMD:R_0402_1005Metric |  | C172152 | WR04X113JTL | 62.5mW Thick Film Resistors 50V ±100ppm/℃ ±5% 11kΩ 0402 Chip Resistor - Surface Mount ROHS
R46 | 2.1K | Resistor_SMD:R_0402_1005Metric |  | C170256 | WR04X2101FTL | 62.5mW Thick Film Resistors 50V ±100ppm/℃ ±1% 2.1kΩ 0402 Chip Resistor - Surface Mount ROHS
R47 | 7.68k | Resistor_SMD:R_0402_1005Metric |  | C334733 | WR04X7681FTL | 62.5mW Thick Film Resistors 50V ±100ppm/℃ ±1% 7.68kΩ 0402 Chip Resistor - Surface Mount ROHS
R48,R67,R96,R104,R105,R106,R111,R112,R113,R124,R132,R133,R135,R137,R156,R164,R191,R192,R193,R194,R202 | 10K | Resistor_SMD:R_0402_1005Metric |  | C163810 | WR04X1002FTL | 62.5mW Thick Film Resistors 50V ±100ppm/℃ ±1% 10kΩ 0402 Chip Resistor - Surface Mount ROHS
R50,R52 | 49.9K | Resistor_SMD:R_0402_1005Metric |  | C350874 | CRCW040249K9FKED | 62.5mW Thick Film Resistors 50V ±100ppm/℃ ±1% 49.9kΩ 0402 Chip Resistor - Surface Mount ROHS
R51 | 226K | Resistor_SMD:R_0402_1005Metric |  | C2076623 | CRCW0402226KFKED | 62.5mW Thick Film Resistors 50V ±100ppm/℃ ±1% 226kΩ 0402 Chip Resistor - Surface Mount ROHS
R75,R88,R89,R94,R95,R108,R109,R110,R131,R138,R146,R147,R148,R149 | 1K | Resistor_SMD:R_0402_1005Metric |  | C327796 | MR04X1001FTL | 100mW Thick Film Resistors 50V ±100ppm/℃ ±1% 1kΩ 0402 Chip Resistor - Surface Mount ROHS
R77,R136,R205,R206 | 1.5K | Resistor_SMD:R_0402_1005Metric |  | C384376 | WR04X152JTL | 62.5mW Thick Film Resistors 50V ±100ppm/℃ ±5% 1.5kΩ 0402 Chip Resistor - Surface Mount ROHS
R78,R79,R80,R81,R144,R145 | 75 | Resistor_SMD:R_0603_1608Metric |  | C2074227 | ESR03EZPF75R0 | 250mW Thick Film Resistors 150V ±100ppm/℃ ±1% 75Ω 0603 Chip Resistor - Surface Mount ROHS
R82,R83,R186,R210,R212,R213,R214,R215,R216,R217,R218,R219 | 270 | Resistor_SMD:R_0402_1005Metric |  | C880838 | SR04X271JTL | 62.5mW ±100ppm/℃ ±5% 270Ω 0402 Chip Resistor - Surface Mount ROHS
R84,R90 | 240 | Resistor_SMD:R_0402_1005Metric |  | C728568 | RT0402BRE07240RL | 62.5mW Thin Film Resistors 50V ±50ppm/℃ ±0.1% 240Ω 0402 Chip Resistor - Surface Mount ROHS
R97,R98 | 5.1K | Resistor_SMD:R_0402_1005Metric |  | C384321 | WR04X512JTL | 62.5mW Thick Film Resistors 50V ±100ppm/℃ ±5% 5.1kΩ 0402 Chip Resistor - Surface Mount ROHS
R102 | 0 | Resistor_SMD:R_0402_1005Metric |  | C396825 | MR04X000PTL | 100mW Thick Film Resistors 50V -200ppm/℃~+400ppm/℃ 0Ω 0402 Chip Resistor - Surface Mount ROHS
R121 | 1.2K | Resistor_SMD:R_0402_1005Metric |  | C168197 | WR04X1201FTL | 62.5mW Thick Film Resistors 50V ±100ppm/℃ ±1% 1.2kΩ 0402 Chip Resistor - Surface Mount ROHS
R122 | 10 | Resistor_SMD:R_0402_1005Metric |  | C25077 | 0402WGF100JTCE | 62.5mW Thick Film Resistors 50V ±200ppm/℃ ±1% 10Ω 0402 Chip Resistor - Surface Mount ROHS
R127 | 5.6K | Resistor_SMD:R_0402_1005Metric |  | C168239 | WR04X5601FTL | 62.5mW Thick Film Resistors 50V ±100ppm/℃ ±1% 5.6kΩ 0402 Chip Resistor - Surface Mount ROHS
R134 | 12.1K | Resistor_SMD:R_0402_1005Metric |  | C168199 | WR04X1212FTL | 62.5mW Thick Film Resistors 50V ±100ppm/℃ ±1% 12.1kΩ 0402 Chip Resistor - Surface Mount ROHS
R143 | 0 | Resistor_SMD:R_0603_1608Metric |  | C2094997 | RCS06030000Z0EC | 250mW Thick Film Resistors 75V 0Ω 0603 Chip Resistor - Surface Mount ROHS
R150 | 0 | Resistor_SMD:R_0603_1608Metric |  | C95177 | RC0603JR-070RL | Res, Thick Film, 0Ω, 1/10W, 0603, Jumper
R151,R195,R200,R201 | 10K | Resistor_SMD:R_0603_1608Metric |  | C25804 | 0603WAF1002T5E | 100mW Thick Film Resistors 75V ±100ppm/℃ ±1% 10kΩ 0603 Chip Resistor - Surface Mount ROHS
R165 | 0.005 | Resistor_SMD:R_2512_6332Metric |  | C7467241 | FRM252WJR005TN | 2W 5mΩ ±5% 2512 Current Sense Resistors - SMD/SMT ROHS
R185 | 0 | Resistor_SMD:R_1206_3216Metric |  | C17888 | 1206W4F0000T5E | 250mW Thick Film Resistors 200V 0Ω 1206 Chip Resistor - Surface Mount ROHS
R203 | 2.49K | Resistor_SMD:R_0402_1005Metric |  | C145071 | RC0402FR-072K49L | 62.5mW Thick Film Resistors 50V ±100ppm/℃ ±1% 2.49kΩ 0402 Chip Resistor - Surface Mount ROHS
R211,R220,R221,R222,R223 | 0.005 | Resistor_SMD:R_2512_6332Metric |  | C7419996 | FRM252WJR005TN | 2W 5mΩ ±5% 2512 Current Sense Resistors - SMD/SMT ROHS
RN1,RN2,RN3,RN4,RN5,RN6,RN7,RN8,RN9,RN10 | CAY10-330J4LF | RASBB:CAY10-XXXJ4 |  | C1731024 | CAY10-330J4LF | Bourns CAY10 Series 33 +/-5% Isolated SMT Resistor Array, 4 Resistors, 0.125W total 0804 (2010M) package Convex
S1,S2,S3 | B3FS-1002P | RASBB:B3FS-1000P |  | C271750 | B3FS-1002P | Tactile Switches 6x6x3.1mm Flat 150OF PhosphorBronze Ag TR
T1 | 15FB-30NL | RASBB:SOIC127P940X597-16N |  | C2987675 | 15FB-30NL | Power over Ethernet (POE+) Magnetics, 10/100BASE-TX VoIP Magnetics Modules
U1 | SZMMSZ4702T1G | RASBB:SOD-123_ONS |  | C463904 | SZMMSZ4702T1G | 500mW 15V SOD-123 Zener Diodes ROHS
U2 | SI2324DS-T1-GE3 | RASBB:SOT_4DS-T1-GE3_VIS |  | C190351 | SI2324DS-T1-GE3 | 100V 2.3A 1.6W 0.234Ω@10V,2.3A 2.8V@250uA SOT-23 MOSFETs ROHS
U3 | SIC453ED-T1-GE3 | RASBB:POWERPAK_MLP34-57_VIS |  | C5334327 | SIC453ED-T1-GE3 | https://www.lcsc.com/datasheet/lcsc_datasheet_2212301230_Vishay-Intertech-SIC453ED-T1-GE3_C5334327.pdf
U4 | JW5026 | Package_TO_SOT_SMD:SOT-23-6 |  | C185109 | JW5026 | Step-down type 1A SOT-23-6 DC-DC Converters ROHS
U5 | TLV9001DBVR | Package_TO_SOT_SMD:SOT-23-5 |  | C19632595 | TLV9001QDBVRQ1 | R-R I/O, 1MHz, 60µA, 3.3V
U6 | CH340E | Package_SO:MSOP-10-1EP_3x3mm_P0.5mm_EP1.68x1.88mm |  | C99652 | CH340E | 2Mbps Transceiver USB 2.0 MSOP-10 USB Converters ROHS
U7 | AHT20 | RASBB:AHT20 |  | C2757850 | AHT20 | SMD Temperature and Humidity Sensor ROHS
U8 | LM386 | Package_SO:SOP-8_3.9x4.9mm_P1.27mm |  | C510560 | LM386D | SOP-8 Audio Amplifiers ROHS
U9 | LM321 | Package_TO_SOT_SMD:SOT-23-5 |  | C280706 | LM321-TR | Low Power Single Operational Amplifier, SOT-23-5
U10,U11 | XC7A100T-CSG324 | RASBB:BGA324C80P18X18_1500X1500X150 |  | C1521791 | XC7A100T-2CSG324I | Artix 7 T 100 XC7A100T-CSG324
U12 | RTL8211E-VB-CG | RASBB:QFN48_6X6X0P85_RTK |  | C90735 | RTL8211E-VB-CG | 4 PHYtransceiver QFN-48-EP(6x6) Ethernet Transceivers ROHS
X1,X3,X4 | OT2EL4C4JI-111OLP-50M | Oscillator:Oscillator_SMD_Abracon_ASE-4Pin_3.2x2.5mm |  | C5203552 | OT2EL4C4JI-111OLP-50M | 1.8V~3.3V ±10ppm CMOS 50MHz SMD3225-4P Crystal Oscillator
Y1 | X503220MSB2GI | RASBB:X503220MSB2GI |  | C112566 | X503220MSB2GI | 20MHz Surface Mount Crystal 20pF ±10ppm ±20ppm SMD5032 Crystals ROHS
Y2 | XC21M4-52.000-F10NNHPL | RASBB:XC21M4-52.000-F10NNHPL |  | C3034316 | XC21M4-52.000-F10NNHPL | 52MHz Surface Mount Crystal 10pF ±10ppm ±10ppm SMD2016-4P Crystals ROHS
Y3 | 25MHz | Crystal:Crystal_SMD_3225-4Pin_3.2x2.5mm |  | C5280577 | XL2EL89CSI-111YLC-25M | Four pin crystal, GND on pins 2 and 3
Z1 | MMSZ5255BT1G | RASBB:SOD3716X135N |  | C242284 | MMSZ5255BT1G | Independent Type 26.6V~29.4V 500mW 28V SOD-123 Zener Diodes ROHS

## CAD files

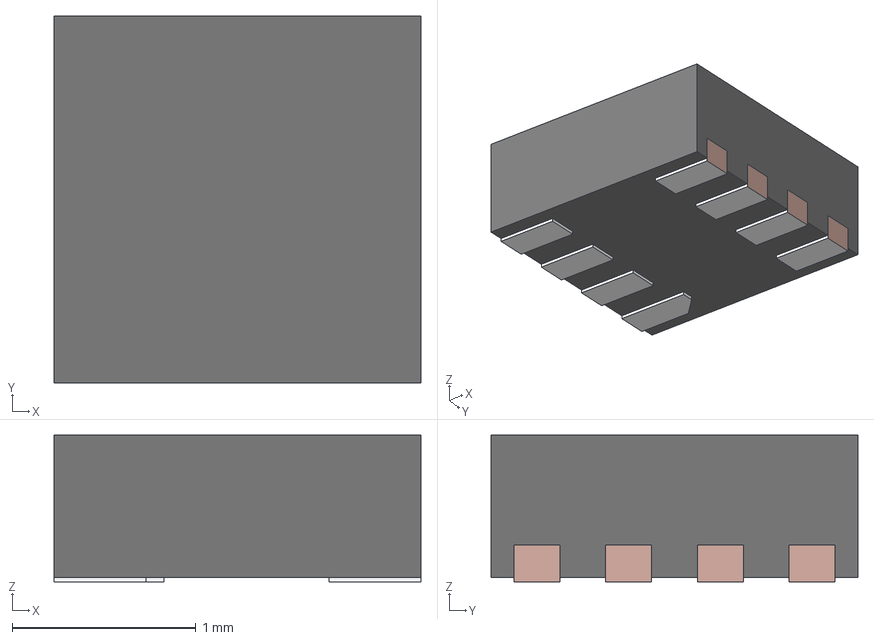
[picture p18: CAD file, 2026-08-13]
RASBB/Hardware/Rev.C/Design/Footprints/LIB_DS90LV028AQDQFRQ1/DS90LV028AQDQFRQ1/3D/DS90LV028AQDQFRQ1.stp
2.00 x 2.00 x 0.8 mm
FRAME
MOLD

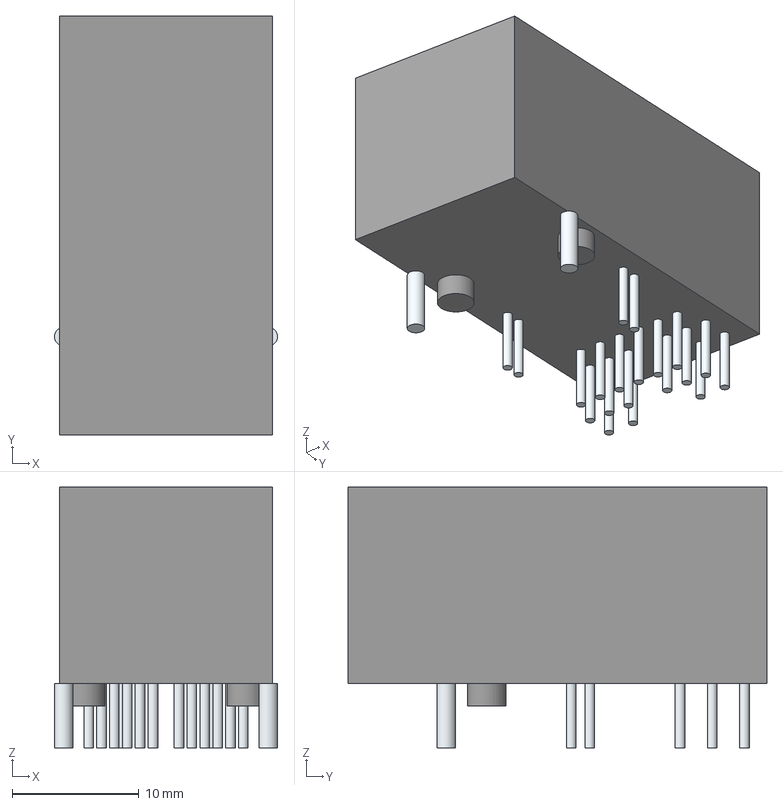
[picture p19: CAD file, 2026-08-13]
RASBB/Hardware/Rev.C/Design/Footprints/JK0-0229NL.stp
17.6 x 33.0 x 20.6 mm
Lugs x 24
Leads x 24

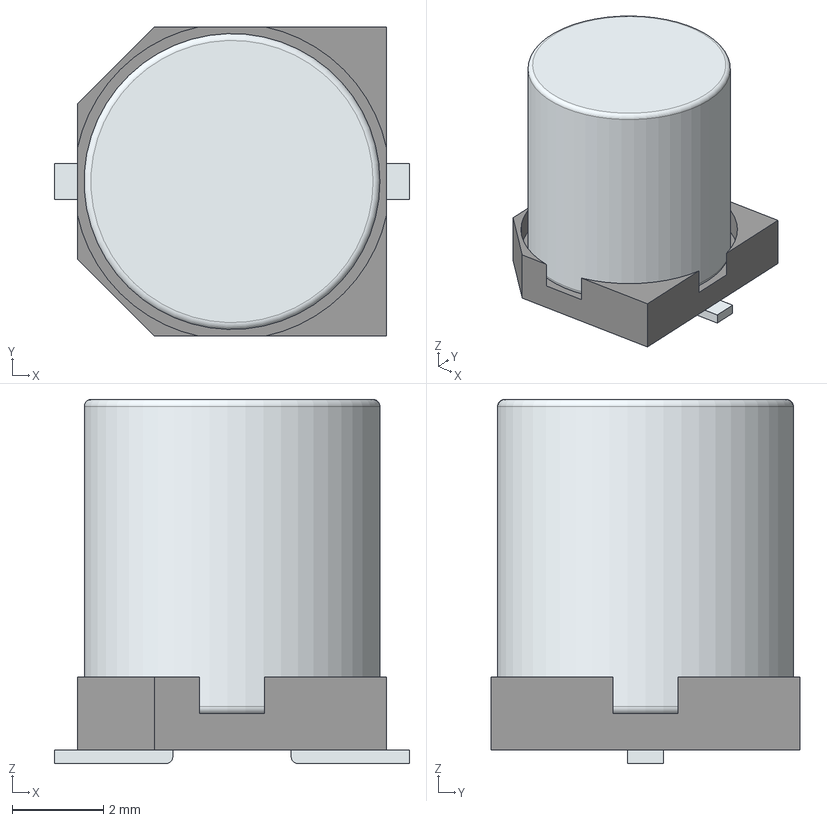
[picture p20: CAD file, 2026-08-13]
RASBB/Hardware/Rev.C/Design/Footprints/UUD1A221MCL1GS.stp
7.80 x 6.80 x 8.00 mm
Base
Pin1Fillet
Pin2Fillet

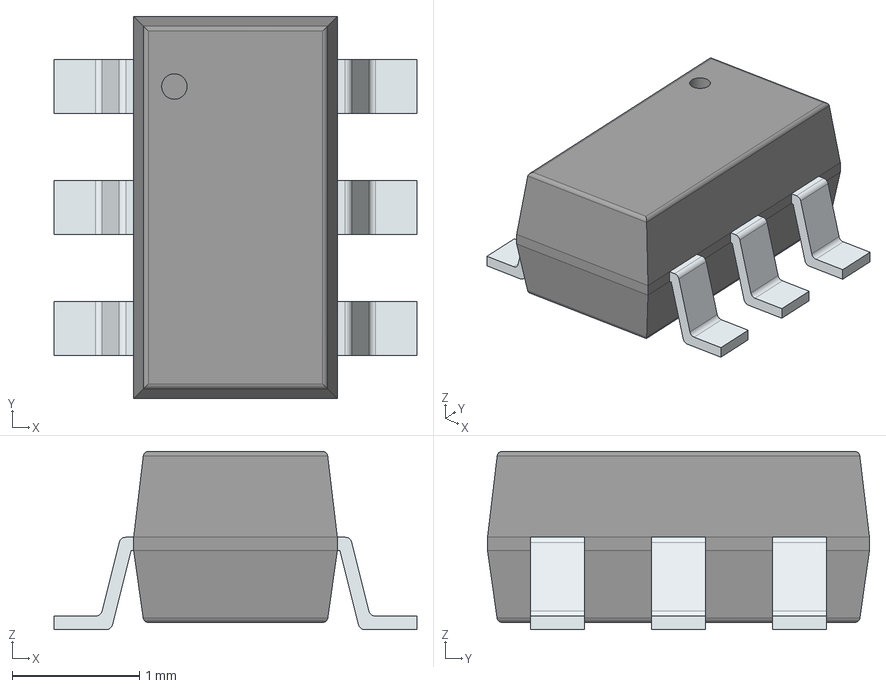
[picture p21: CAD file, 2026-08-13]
RASBB/Hardware/Rev.C/Design/Footprints/DT2042-04SO-7.stp
2.85 x 3.00 x 1.40 mm
PinsArrayLR

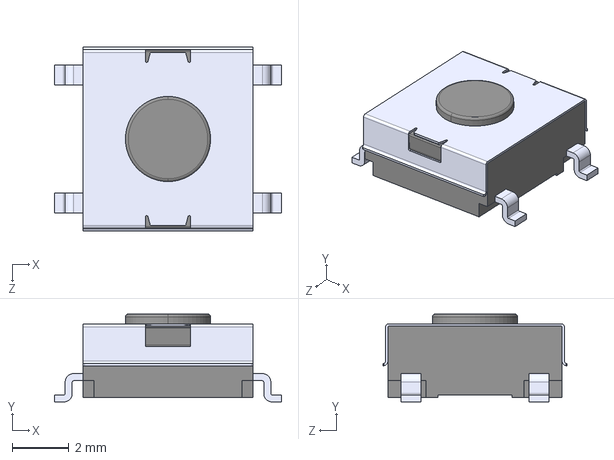
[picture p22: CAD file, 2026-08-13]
RASBB/Hardware/Rev.C/Design/Footprints/B3FS-1002P.stp
8.00 x 3.10 x 6.50 mm

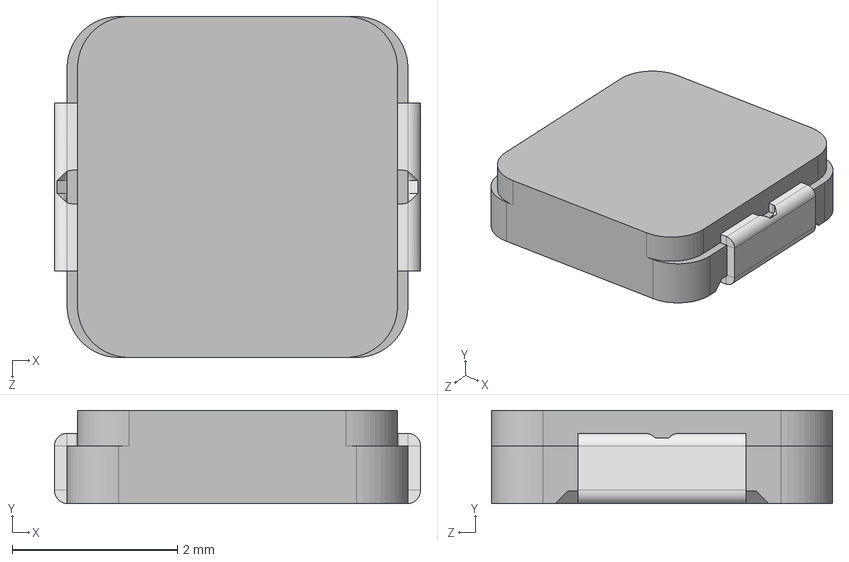
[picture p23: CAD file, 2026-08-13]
RASBB/Hardware/Rev.C/Design/Footprints/IHLP1616ABERR47M01.stp
4.43 x 1.13 x 4.13 mm

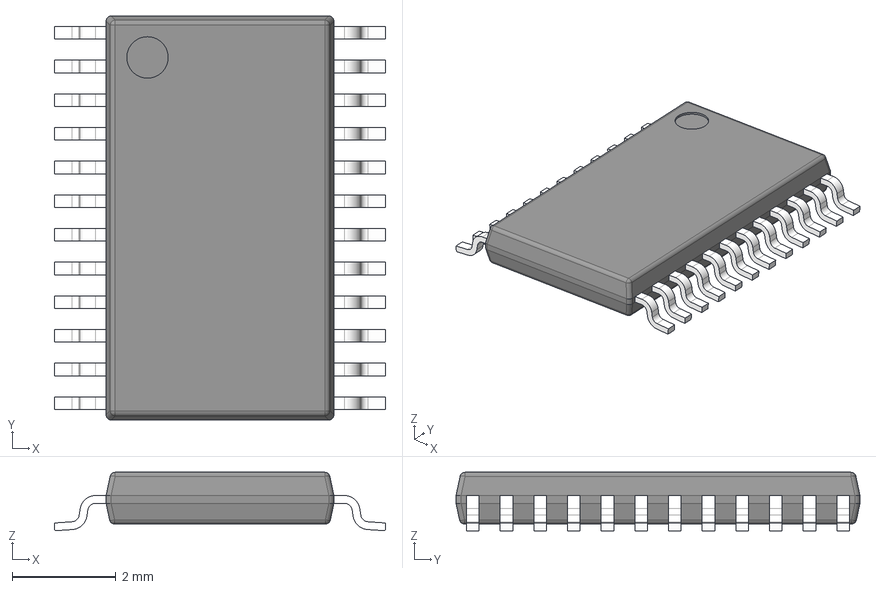
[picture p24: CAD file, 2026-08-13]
RASBB/Hardware/Rev.C/Design/Footprints/TPD12S016PWR.stp
6.40 x 7.80 x 1.13 mm
BODY-TSSOP
LEAD-TSSOP x 24
PIN1

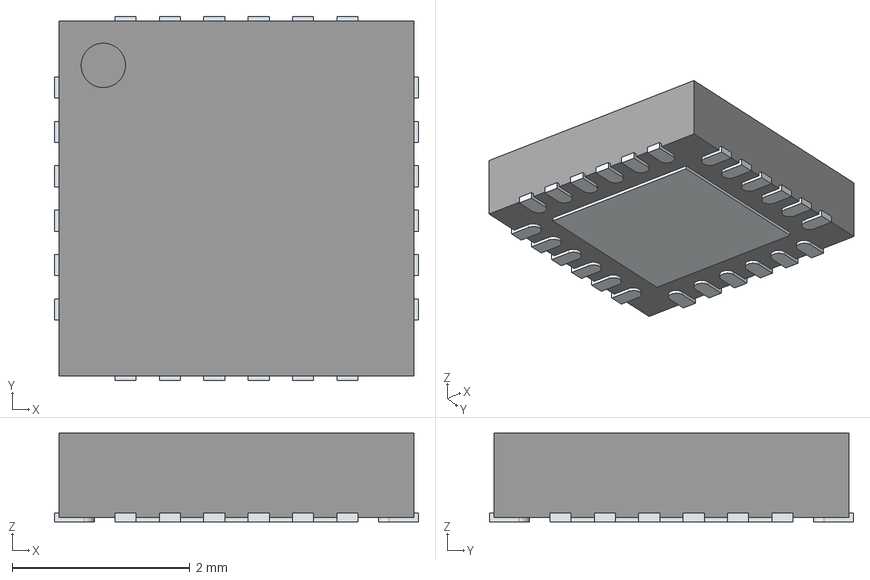
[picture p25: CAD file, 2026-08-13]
RASBB/Hardware/Rev.C/Design/Footprints/SX1280IMLTRT.stp
4.10 x 4.10 x 1.00 mm
ThermalPin
PinsArrayLR
PinsArrayTB

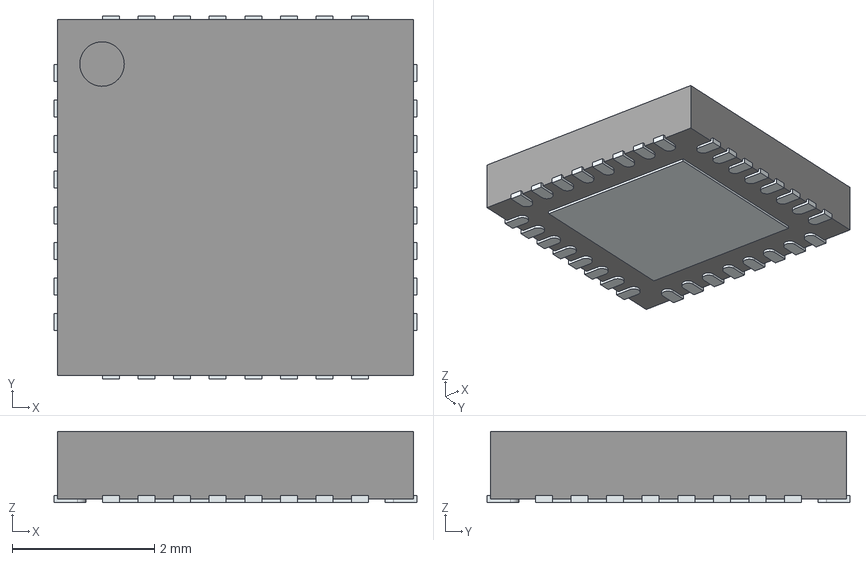
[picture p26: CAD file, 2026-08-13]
RASBB/Hardware/Rev.C/Design/Footprints/USB3320C-EZK-TR.stp
5.10 x 5.10 x 1.00 mm
ThermalPin
PinsArrayLR
PinsArrayTB

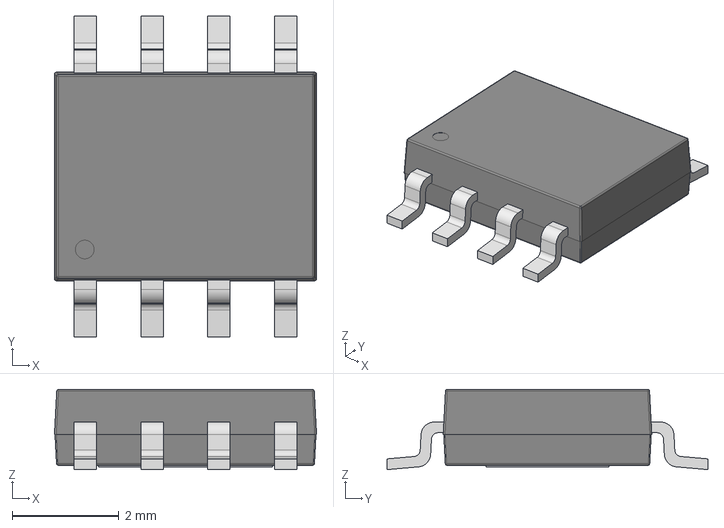
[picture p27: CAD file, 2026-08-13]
RASBB/Hardware/Rev.C/Design/Footprints/RT6365GSP.stp
4.90 x 6.00 x 1.50 mm

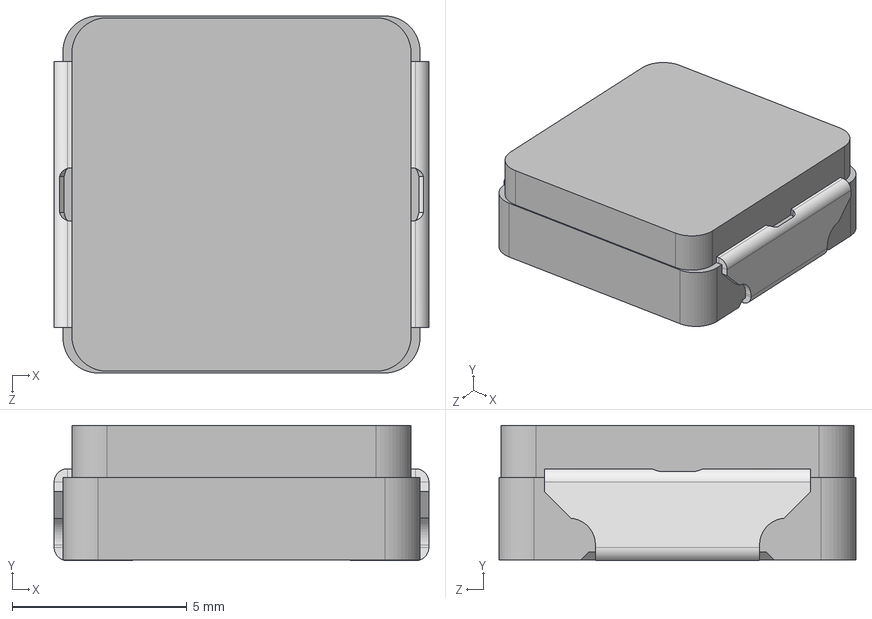
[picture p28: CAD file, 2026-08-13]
RASBB/Hardware/Rev.C/Design/Footprints/IHLP4040DZERR36M01.stp
10.7 x 3.87 x 10.2 mm

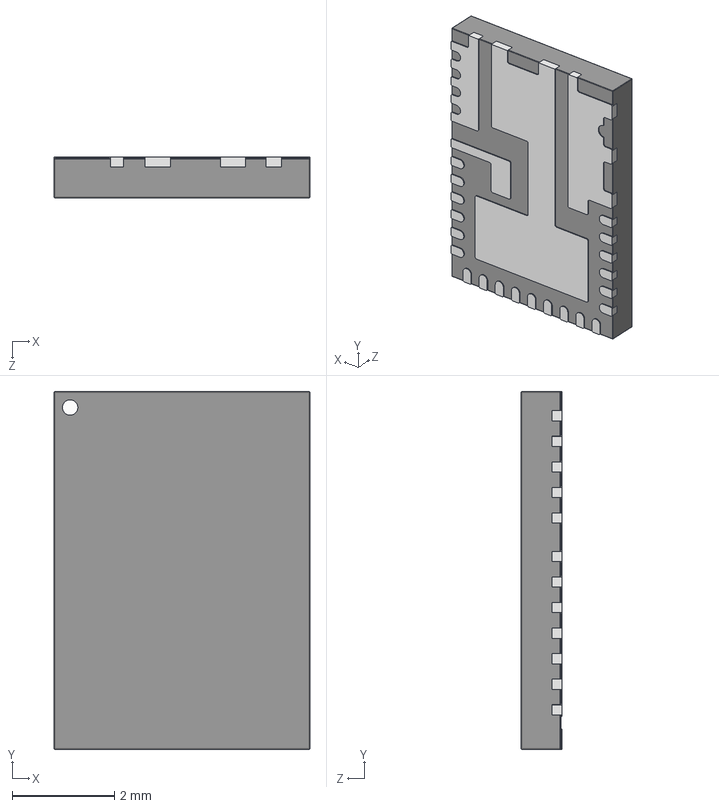
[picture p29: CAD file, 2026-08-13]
RASBB/Hardware/Rev.C/Design/Footprints/SIC453ED-T1-GE3.stp
5.00 x 7.00 x 0.803 mm
terminals
DOT

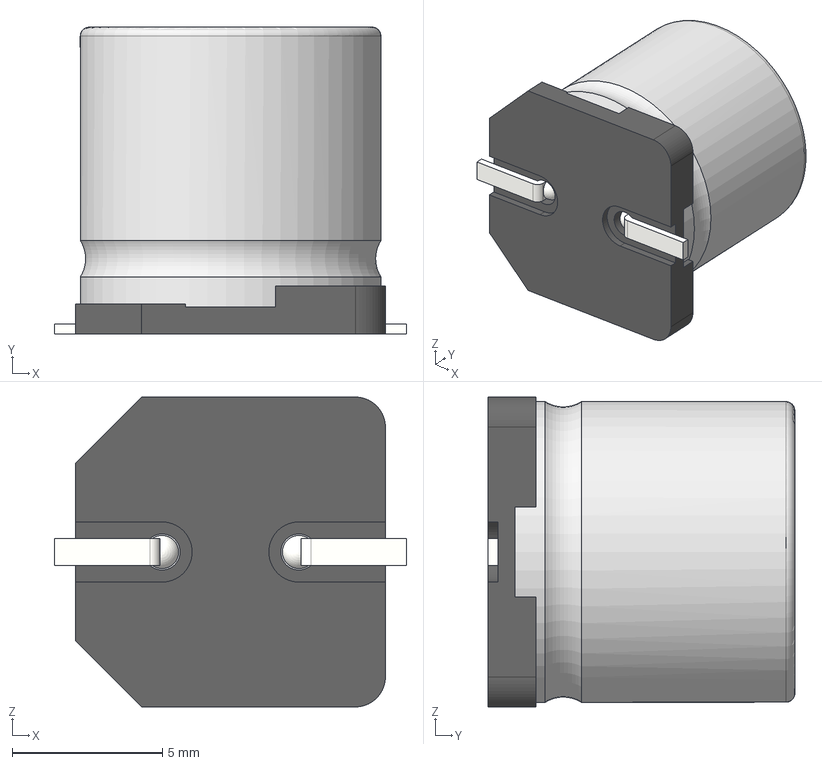
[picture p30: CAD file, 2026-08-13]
RASBB/Hardware/Rev.C/Design/Footprints/EEE-FP1V331AP.stp
11.7 x 10.2 x 10.3 mm
標準品ケースΦ10x9.3L SIDE CODE G
標準品座版Φ10 SIZE CODE G
標準品リード線Φ10 SIZE CODE G改 x 2

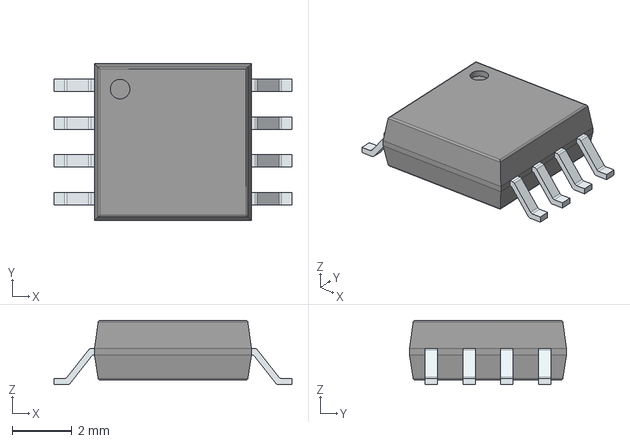
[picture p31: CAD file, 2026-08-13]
RASBB/Hardware/Rev.C/Design/Footprints/S25FL128LAGMFI010.stp
8.00 x 5.28 x 2.16 mm
PinsArrayLR

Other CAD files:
RASBB/Hardware/Rev.C/Design/Footprints/MMSZ5255BT1G.stp
RASBB/Hardware/Rev.C/Design/Footprints/B340LB-13-F.stp
RASBB/Hardware/Rev.C/Design/Footprints/VSSAF5L45HM3_A_H.stp
RASBB/Hardware/Rev.C/Design/Footprints/BLM15BD601SH1D.stp
RASBB/Hardware/Rev.C/Design/Footprints/1747981-1.stp
RASBB/Hardware/Rev.C/Design/Footprints/691305140002.stp
RASBB/Hardware/Rev.C/Design/Footprints/D5V0F4U6SO-7.stp
RASBB/Hardware/Rev.C/Design/Footprints/LIB_DS90LV028AQDQFRQ1/DS90LV028AQDQFRQ1/Allegro/son50p200x200x80-8n.psm
RASBB/Hardware/Rev.C/Design/Footprints/LIB_DS90LV028AQDQFRQ1/DS90LV028AQDQFRQ1/DEHDL/ds90lv028aqdqfrq1/chips/chips.prt
RASBB/Hardware/Rev.C/Design/Footprints/LIB_H1102NL/H1102NL/Allegro/soic127p940x597-16n.psm
RASBB/Hardware/Rev.C/Design/Footprints/LIB_H1102NL/H1102NL/DEHDL/h1102nl/chips/chips.prt
RASBB/Hardware/Rev.C/Design/Footprints/MT41K256M16TW-107_P.stp
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

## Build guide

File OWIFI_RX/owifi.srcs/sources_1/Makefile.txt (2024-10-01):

# Define the top module and file list
TOP_MODULE = top_module
FILE_LIST = filelist.txt

# Define Verilator commands
VERILATOR = verilator
VFLAGS = --cc --exe --build
CFLAGS = --top-module $(TOP_MODULE)

# Default target: compile and run
all: sim

# Simulation target
sim: $(FILE_LIST)
    $(VERILATOR) $(VFLAGS) $(CFLAGS) -f $(FILE_LIST)
    ./obj_dir/V$(TOP_MODULE)

# Clean target
clean:
    rm -rf obj_dir
    rm -f *.o *.d *.mk

.PHONY: all clean sim

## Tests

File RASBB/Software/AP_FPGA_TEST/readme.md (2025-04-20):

The project FPGA_TEST contains several blocks that can be used for testing the ADC data stream and HDMI port.
It puts the ADC samples decoded from the incoming LVDS signal into a parallel data word on Debug Pins D0 to D23
(Channel 1 and 2, reach 12 Bit of size)

Additionally, you can switch on the Spectrum display over HDMI and a waterfall view of the spectrum.

To activate thse additional steps, uncomment the following lines in rasm2400_pre_def.vh:

//`define USE_SPECTRUM //show a spectrum on the screen
//`define USE_WATERFALL //add a spectrogram (aka waterfall)

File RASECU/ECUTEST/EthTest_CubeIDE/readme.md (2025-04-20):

This CubeIDE project tests the 100MBpbs ethernet port of the STM32 on the RASBB.
The project is currently configured to listen on 10.0.10.55 for incoming ICMP pings
and replies to them.

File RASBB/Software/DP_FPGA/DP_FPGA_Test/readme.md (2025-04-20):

Digital processor FPGA test project file

This priject contains currently only some basic 50MHz input clock divider test.
It is at the beginning mostly used for setting up the VIVADO integraded logic analyzer.

Please feel free to add your custom code and subit a pull request.

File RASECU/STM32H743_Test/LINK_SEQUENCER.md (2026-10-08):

# Link sequencer (ported from LOTAG/LOGW/Firmware/ECU, 2026-08-29)

`Core/Src/logw_seq.c` runs as its own task and brings the receive chain up in
order: front end (I2C 0x42, model 0x21 = RASRF6000, STATUS INIT_DONE +
CLK_LOCK) → FPGA1 bitstream present (SPI STATUS signature `101` in bits 7:5)
→ HKU register 0x09 ramp ON → FPGA CONTROL RETRAIN → wait for trained →
ramp OFF → RUN, and re-runs the cycle when the FPGA disappears and comes back
(bitstream reload), when the front-end clock lock drops, or when the capture
loses "trained" for more than 2 s. Full description and the state table:
`LOTAG/LOGW/Firmware/ECU/README.md` (the authority, keep the copies in step).

Works with the FPGA designs that carry `spi_ctrl_if.v`: RASM2400
`top_LVDSTEST` (both capture modes) and LOGW. OWIFI_RX's `spi_frame_if` has
LINK_OK/FE_VALID but neither the signature nor a RETRAIN control, so with an
OWIFI bitstream the sequencer stays in WAIT_FPGA and touches nothing; the
frame read-out task keeps working (it now holds `logw_bus_lock()` around each
poll so it cannot tear a sequencer transaction).

Console (USART3): `LS` state + both statuses + lane taps + event history,
`LR` force one training cycle, `LP 0|1|2` automatic / park with ramp on / off.

Build: `STM32CubeIDE/Debug` (`make -j8 all` with the ST toolchain first on
PATH) - `subdir.mk`, `objects.list` and `.project` carry `logw_seq.c`.

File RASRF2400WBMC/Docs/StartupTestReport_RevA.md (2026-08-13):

## Bring-up and measurement results, RASRF2400WBMC revision A.

| ID | State | Description | Result |
|----|---|---|---|
| 1 | pass | MAX2831 PLL lock, all four channels | locked |
| 2 | pass | ADC3424 configuration verified over SDOUT, both devices | verified |
| 3 | pass | Deserialisation of all four channels to the RASPMO quad-split display | all four present |
| 4 | pass | Baseboard commands the array over I2C | responds |
| 5 | pass | Firmware identity, 32 KB read back over SWD against `Debug/RASRF2400BMC.elf` | byte-for-byte identical, stamp `097aab2` |
| 6 | pass | Live `s_rxGain` read from the running firmware | `68` |
| 7 | pass | I2C console commands `ID`, `ST`, `GG`, `SG`, `SF`, `GF` | all answered |
| 8 | pass | Retune time, command to settled | 56 ms |
| 9 | pass | Absolute calibration, −60 dBm CW at 2439 MHz | reads −18 dBFS |
| 10 | pass | Port referral derived from item 9 | 0 dBFS ≈ −42 dBm |
| 11 | pass | ADC clip point at the port | ≈ −42 dBm |
| 12 | pass | Ambient on-air signal recorded through the array | −45 dBFS ≈ −87 dBm |
| 13 | pass | RX gain code `0x68`, LNA high and VGA 16 dB, checked on air with the RASANT2400 | confirmed, left unchanged |
| 14 | pass | System power at 12 V, measured as an input delta | +2.92 W |
| 15 | pass | Image rejection, CH3 and CH4 | −45 dB |
| 16 | projected | Image rejection, CH1 and CH2 | −45 dB |
| 17 | pass | Four-channel amplitude match on air | −45 dBFS on all four |
| 18 | pass | Self-test register `0x08`, ramps either ADC on demand with the other live as a control | working |
| 19 | pass | `SR` / `GR` console commands, split a digital-path fault from an analogue one without a rebuild, a reflash, or moving the ST-LINK | working |
| 20 | pass | `SR` reads the register back rather than echoing the request | correct readback |
| 21 | — | Bring-up test video | https://www.youtube.com/watch?v=SnHPaw8y9vc |

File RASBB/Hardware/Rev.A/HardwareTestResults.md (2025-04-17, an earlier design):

**These are the test results of the functional blocks of Rev. A that have been found by the board bring-up**

* The configuration flash memories of both FPGASs have been tested. Flash 1 worked successfully, while an error was found in Flash 2 and will be corrected in Rev B.

* The two FPGAs are accessible via JTAG. They have been programmed with a test software.

* FPGA 1 is capable receiving the LVDS data of the ADC. The sample stream has bee routed 
to the debug header and verified for validity. We found a termination issue on the 
LVDS line which will be fixed in Rev. B.

* The output for the alarm device has been succesfully tested.

* All voltages from the DC/DC power converters have been tested. They are stable and supply
enough energy for the prupose of the biard.

* The DDR RAM chips could not be tested sucessfully because of a mistake of one power supply pin. 
We expect them to be operational in the next board revision B.

* The STM32 microcontroller has been succesfully programmed. A test program has been
run to proove correct operation.

* The HDMI output port has been tested with a test pattern generator program. The 
produced image is clean and stable.

* USB-C functionality has been tested and proved to run successfully."

* Ethernet on uController STM32 works with 100 Mbps full duplex

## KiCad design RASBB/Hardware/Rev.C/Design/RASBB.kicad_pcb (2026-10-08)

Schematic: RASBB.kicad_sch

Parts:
C1, C2: 1uF; C_0402_1005Metric; Mfr. Part # 0402X105M160CT; LCSC Part # C3889771
C270: 100nF; C_0402_1005Metric; Mfr. Part # 0402B104K500CT; LCSC Part # C152814
C271, C272: 2200pF; C_0402_1005Metric; Mfr. Part # 0402B222K500NT; LCSC Part # C1531
J20: PWM_DAC_OUT; PinHeader_1x02_P2.54mm_Vertical; Mfr. Part # PZ254V-11-02P; LCSC Part # C492401
R1, R2, R3, R4, R6, R7, R8, R11, R12, R13, R14, R15, R16, R22: 49.9; R_0402_1005Metric; Mfr. Part # RMCF0402FT49R9; LCSC Part # C4229190
R9, R10: 4K7; R_0402_1005Metric; Mfr. Part # WR04X4701FTL; LCSC Part # C163826
R17, R18, R19, R20, R23, R24: 22; R_0402_1005Metric; Mfr. Part # WR04X22R0FTL; LCSC Part # C163821
R21, R168, R169, R170, R171, R172, R173, R174, R175, R176, R177, R178, R179, R180, R181, R182, R183, R184: 100; R_0402_1005Metric; Mfr. Part # WR04X1000FTL; LCSC Part # C163808
R150: 0; R_0603_1608Metric; Mfr. Part # RC0603JR-070RL; LCSC Part # C95177
R151, R195, R200, R201: 10K; R_0603_1608Metric; Mfr. Part # 0603WAF1002T5E; LCSC Part # C25804
SW1, SW2: 435451019820; Mfr. Part # 435451019820
TP6, TP7, TP8, TP9, TP10, TP11, TP12, TP13, TP14, TP15, TP16, TP17, TP18, TP19, TP20, TP21, TP22: TestPoint; TestPoint_Pad_D1.0mm; not fitted
U5: TLV9001DBVR; SOT-23-5; Mfr. Part # TLV9001QDBVRQ1; LCSC Part # C19632595

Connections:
/Audio_IN-OUT/3V3: C270.1, R9.2, R10.2, R200.2, R201.2, U5.5 (V+); also elsewhere on the board
/Audio_IN-OUT/Audio_IN: R21.2; also elsewhere on the board
/Audio_IN-OUT/LM386_INP: C2.2; also elsewhere on the board
/CS_FLASH_uC: TP18.1 (1_1); also elsewhere on the board
/Config-SPI FLASH/MUX_EN1: TP19.1 (1_1); also elsewhere on the board
/Config-SPI FLASH/MUX_EN2: TP20.1 (1_1); also elsewhere on the board
/Config-SPI FLASH/SCK_FLASH_FPGA2: R6.1; also elsewhere on the board
/Config-SPI FLASH/SCK_Flash_FPGA1: R1.2; also elsewhere on the board
/Config-SPI FLASH/SI_FLASH_FPGA2: R7.1; also elsewhere on the board
/Config-SPI FLASH/SI_Flash_FPGA1: R2.2; also elsewhere on the board
/Config-SPI FLASH/SO_FLASH_FPGA2: R8.1; also elsewhere on the board
/Config-SPI FLASH/SO_Flash_FPGA1: R4.2; also elsewhere on the board
/Config-SPI FLASH/SWITCH_FLASH_1: TP22.1 (1_1); also elsewhere on the board
/Config-SPI FLASH/SWITCH_FLASH_2: TP21.1 (1_1); also elsewhere on the board
/Ethernet_uC/RMII_CRS_DV: R20.1; also elsewhere on the board
/Ethernet_uC/RMII_REFCLK: R18.1; also elsewhere on the board
/Ethernet_uC/RMII_RXD0: R23.1; also elsewhere on the board
/Ethernet_uC/RMII_RXD1: R24.1; also elsewhere on the board
/Ethernet_uC/RMII_TXD0: R19.1; also elsewhere on the board
/Ethernet_uC/RMII_TXD1: R17.1; also elsewhere on the board
/FPGA1_RESET: SW1.4; also elsewhere on the board
/FPGA2_RESET: SW2.4; also elsewhere on the board
/FPGA-01/FPGA1_CLK: R1.1; also elsewhere on the board
/FPGA-01/FPGA1_MISO: R4.1; also elsewhere on the board
/FPGA-01/FPGA1_MOSI: R2.1; also elsewhere on the board
/FPGA-02/F2_B35_J2: R195.1; also elsewhere on the board
/PCIE/PCIE_MISO: R12.1; also elsewhere on the board
/PCIE/PCIE_MOSI: R3.1; also elsewhere on the board
/PCIE/PCIE_SCK: R11.1; also elsewhere on the board
/PCIE/RX0_N: R168.1; also elsewhere on the board
/PCIE/RX0_P: R168.2; also elsewhere on the board
/PCIE/RX1_N: R169.1; also elsewhere on the board
/PCIE/RX1_P: R169.2; also elsewhere on the board
/PCIE/RX2_N: R170.1; also elsewhere on the board
/PCIE/RX2_P: R170.2; also elsewhere on the board
/PCIE/RX3_N: R171.1; also elsewhere on the board
/PCIE/RX3_P: R171.2; also elsewhere on the board
/PCIE/RX4_N: R172.1; also elsewhere on the board
/PCIE/RX4_P: R172.2; also elsewhere on the board
/PCIE/RX5_N: R173.1; also elsewhere on the board
/PCIE/RX5_P: R173.2; also elsewhere on the board
/PCIE/RX6_N: R174.1; also elsewhere on the board
/PCIE/RX6_P: R174.2; also elsewhere on the board
/PCIE/RX7_N: R175.1; also elsewhere on the board
/PCIE/RX7_P: R175.2; also elsewhere on the board
/PCIE/RX8_N: R176.1; also elsewhere on the board
/PCIE/RX8_P: R176.2; also elsewhere on the board
/PCIE/RX9_N: R177.1; also elsewhere on the board
/PCIE/RX9_P: R177.2; also elsewhere on the board
/PCIE/RX10_N: R178.1; also elsewhere on the board
/PCIE/RX10_P: R178.2; also elsewhere on the board
/PCIE/RX11_N: R179.1; also elsewhere on the board
/PCIE/RX11_P: R179.2; also elsewhere on the board
/PCIE/RX12_N: R180.1; also elsewhere on the board
/PCIE/RX12_P: R180.2; also elsewhere on the board
/PCIE/RX13_N: R181.1; also elsewhere on the board
/PCIE/RX13_P: R181.2; also elsewhere on the board
/PCIE/RX14_N: R182.1; also elsewhere on the board
/PCIE/RX14_P: R182.2; also elsewhere on the board
/PCIE/RX15_N: R183.1; also elsewhere on the board
/PCIE/RX15_P: R183.2; also elsewhere on the board
/PCIE/RX16_N: R184.1; also elsewhere on the board
/PCIE/RX16_P: R184.2; also elsewhere on the board
/PCIE/SMCLK: R10.1; also elsewhere on the board
/PCIE/SMDAT: R9.1; also elsewhere on the board
/RF_Transceiver/BUSY_LORA_G: TP13.1 (1_1); also elsewhere on the board
/RF_Transceiver/DIO1_LORA_G: TP12.1 (1_1); also elsewhere on the board
/RF_Transceiver/DIO2_LORA_G: TP11.1 (1_1); also elsewhere on the board
/RF_Transceiver/DIO3_LORA_G: TP10.1 (1_1); also elsewhere on the board
/RF_Transceiver/NRST_LORA_G: TP14.1 (1_1); also elsewhere on the board
/RF_Transceiver/SPI_MISO_LORA_G: R22.2; also elsewhere on the board
/RF_Transceiver/SPI_MOSI_LORA_G: R16.2, TP7.1 (1_1); also elsewhere on the board
/RF_Transceiver/SPI_NSS_LORA_G: TP9.1 (1_1); also elsewhere on the board
/RF_Transceiver/SPI_SCK_LORA_G: R15.2, TP8.1 (1_1); also elsewhere on the board
/SCK_FLASH_FPGA2: R6.2; also elsewhere on the board
/SCK_FLASH_uC: R13.1, TP17.1 (1_1); also elsewhere on the board
/SI_FLASH_FPGA2: R7.2; also elsewhere on the board
/SI_FLASH_uC: R14.1, TP16.1 (1_1); also elsewhere on the board
/SO_FLASH_FPGA2: R8.2; also elsewhere on the board
/SO_FLASH_uC: TP15.1 (1_1); also elsewhere on the board
/uController/ADC1_IN5: C1.1; also elsewhere on the board
/uController/uC_DAC2_OUT2: C2.1; also elsewhere on the board
/uController/uC_ETH_CRS_DV: R20.2; also elsewhere on the board
/uController/uC_ETH_REF_CLK: R18.2; also elsewhere on the board
/uController/uC_ETH_RXD0: R23.2; also elsewhere on the board
/uController/uC_ETH_RXD1: R24.2; also elsewhere on the board
/uController/uC_ETH_TXD0: R19.2; also elsewhere on the board
/uController/uC_ETH_TXD1: R17.2; also elsewhere on the board
/uController/uC_SPI2_MISO: R22.1, TP6.1 (1_1); also elsewhere on the board
/uController/uC_SPI2_MOSI: R16.1; also elsewhere on the board
/uController/uC_SPI2_SCK: R15.1; also elsewhere on the board
/uController/uC_SPI3_MISO: R3.2; also elsewhere on the board
/uController/uC_SPI3_MOSI: R12.2; also elsewhere on the board
/uController/uC_SPI3_SCK: R11.2; also elsewhere on the board
/uController/uC_SPI4_MOSI: R14.2; also elsewhere on the board
/uController/uC_SPI4_SCK: R13.2; also elsewhere on the board
GND: C270.2, C271.2, C272.2, J20.1, SW1.2, SW1.3, SW1.5 (GND), SW2.2, SW2.3, SW2.5 (GND), U5.2 (V-); also elsewhere on the board
unnamed: C1.2, R21.1
unnamed: C272.1, R151.2, R195.2
unnamed: J20.2, R150.1
unnamed: R200.1, SW1.1
unnamed: R201.1, SW2.1
unnamed: C271.1, R151.1, U5.3 (+)
unnamed: R150.2, U5.1, U5.4 (-)

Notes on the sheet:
f3dB:5Hz

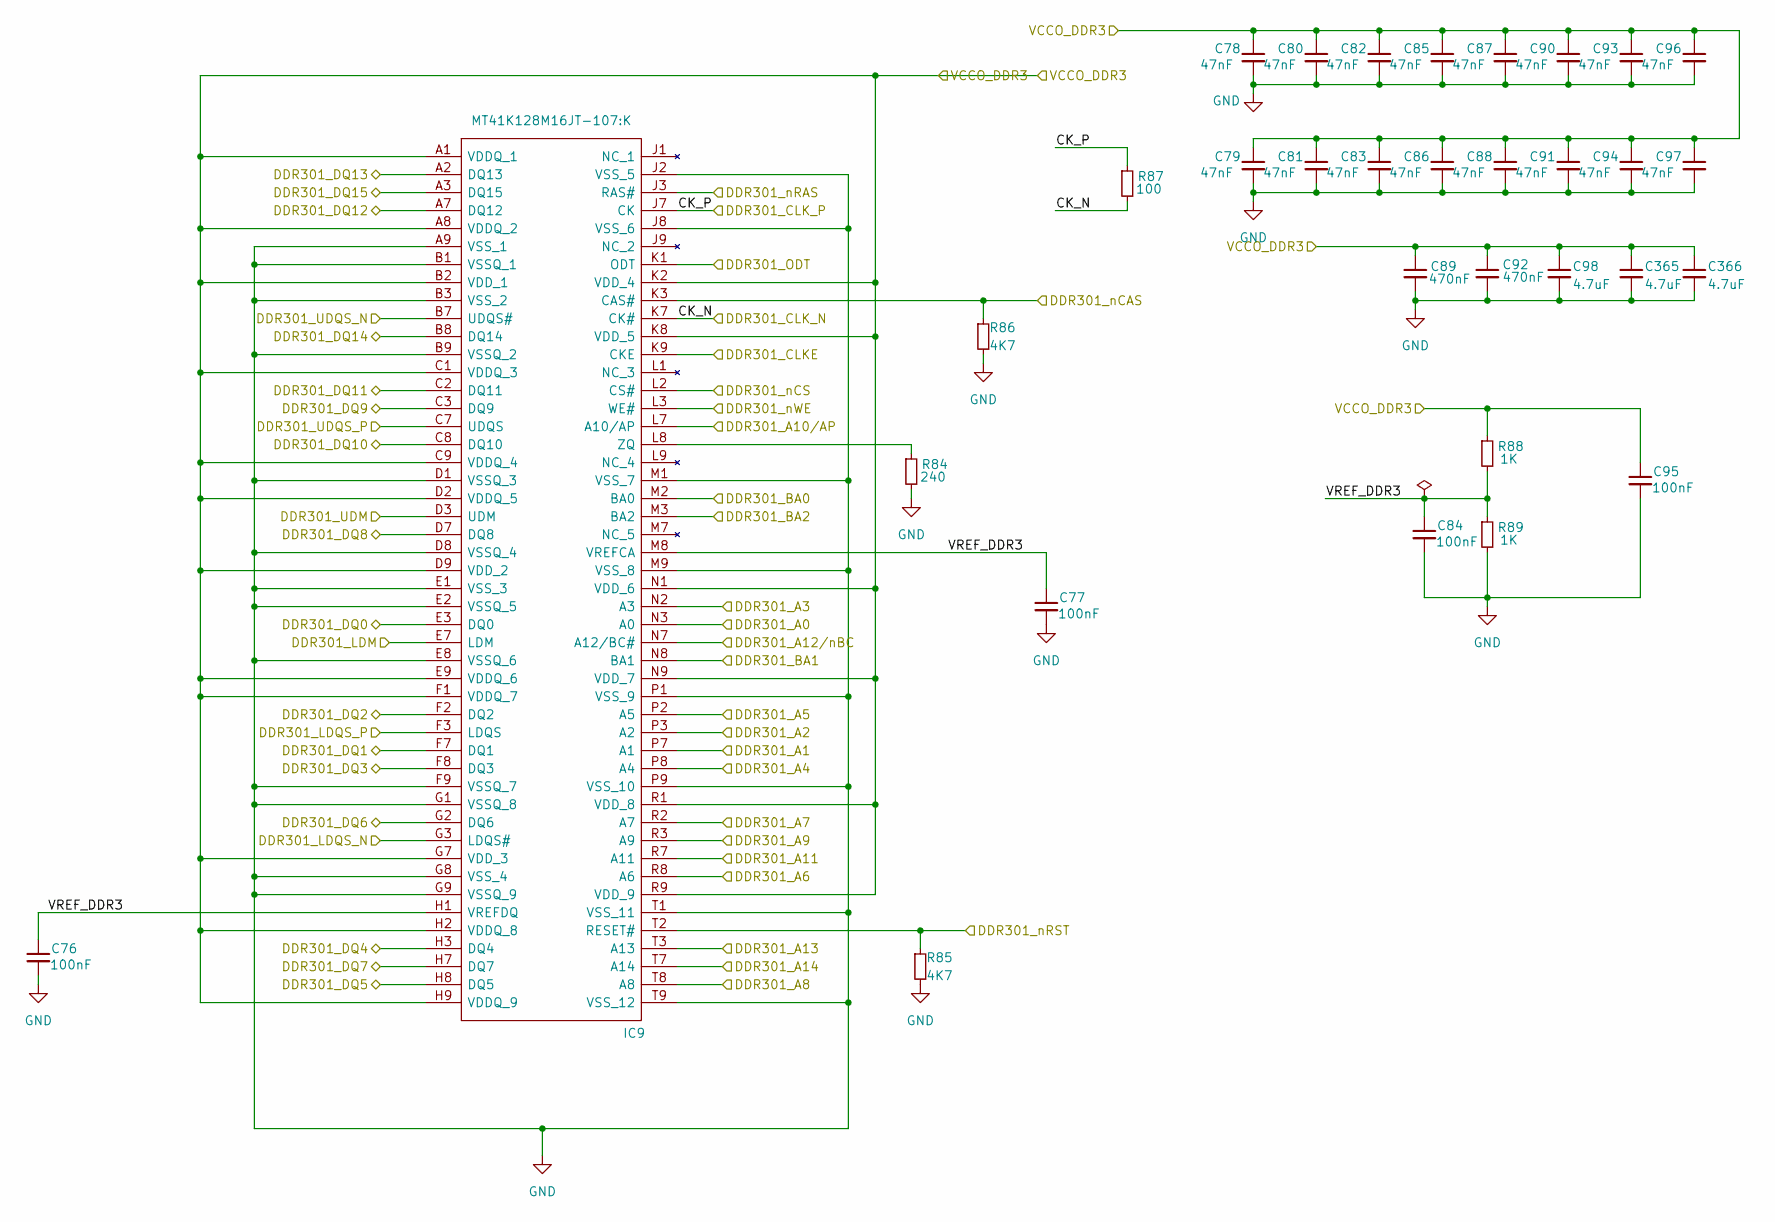
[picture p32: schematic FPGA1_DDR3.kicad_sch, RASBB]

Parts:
C76, C77, C84, C95: 100nF; C_0402_1005Metric; Mfr. Part # 0402B104K500CT; LCSC Part # C152814
C78, C79, C80, C81, C82, C83, C85, C86, C87, C88, C90, C91, C93, C94, C96, C97: 47nF; C_0402_1005Metric; Mfr. Part # C0402C473J8RAC7867; LCSC Part # C2178375
C89, C92: 470nF; C_0402_1005Metric; Mfr. Part # GRM155R71C474KE01D; LCSC Part # C471404
C98, C365, C366: 4.7uF; C_0603_1608Metric; Mfr. Part # GMK107BBJ475KA-T; LCSC Part # C7281848
IC9: MT41K128M16JT-107:K; BGA96C80P9X16_800X1400X120; Mfr. Part # MT41K128M16JT-107:K; LCSC Part # C2841151
R84: 240; R_0402_1005Metric; Mfr. Part # RT0402BRE07240RL; LCSC Part # C728568
R85, R86: 4K7; R_0402_1005Metric; Mfr. Part # WR04X4701FTL; LCSC Part # C163826
R87: 100; R_0402_1005Metric; Mfr. Part # WR04X1000FTL; LCSC Part # C163808
R88, R89: 1K; R_0402_1005Metric; Mfr. Part # MR04X1001FTL; LCSC Part # C327796

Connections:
/DDR3-01/CK_N: IC9.K7 (CK#), R87.2; also elsewhere on the board
/DDR3-01/CK_P: IC9.J7 (CK), R87.1; also elsewhere on the board
/DDR3-01/DDR301_A0: IC9.N3 (A0); also elsewhere on the board
/DDR3-01/DDR301_A1: IC9.P7 (A1); also elsewhere on the board
/DDR3-01/DDR301_A2: IC9.P3 (A2); also elsewhere on the board
/DDR3-01/DDR301_A3: IC9.N2 (A3); also elsewhere on the board
/DDR3-01/DDR301_A4: IC9.P8 (A4); also elsewhere on the board
/DDR3-01/DDR301_A5: IC9.P2 (A5); also elsewhere on the board
/DDR3-01/DDR301_A6: IC9.R8 (A6); also elsewhere on the board
/DDR3-01/DDR301_A7: IC9.R2 (A7); also elsewhere on the board
/DDR3-01/DDR301_A8: IC9.T8 (A8); also elsewhere on the board
/DDR3-01/DDR301_A9: IC9.R3 (A9); also elsewhere on the board
/DDR3-01/DDR301_A10/AP: IC9.L7 (A10/AP); also elsewhere on the board
/DDR3-01/DDR301_A11: IC9.R7 (A11); also elsewhere on the board
/DDR3-01/DDR301_A12/nBC: IC9.N7 (A12/BC#); also elsewhere on the board
/DDR3-01/DDR301_A13: IC9.T3 (A13); also elsewhere on the board
/DDR3-01/DDR301_A14: IC9.T7 (A14); also elsewhere on the board
/DDR3-01/DDR301_BA0: IC9.M2 (BA0); also elsewhere on the board
/DDR3-01/DDR301_BA1: IC9.N8 (BA1); also elsewhere on the board
/DDR3-01/DDR301_BA2: IC9.M3 (BA2); also elsewhere on the board
/DDR3-01/DDR301_CLKE: IC9.K9 (CKE); also elsewhere on the board
/DDR3-01/DDR301_DQ0: IC9.E3 (DQ0); also elsewhere on the board
/DDR3-01/DDR301_DQ1: IC9.F7 (DQ1); also elsewhere on the board
/DDR3-01/DDR301_DQ2: IC9.F2 (DQ2); also elsewhere on the board
/DDR3-01/DDR301_DQ3: IC9.F8 (DQ3); also elsewhere on the board
/DDR3-01/DDR301_DQ4: IC9.H3 (DQ4); also elsewhere on the board
/DDR3-01/DDR301_DQ5: IC9.H8 (DQ5); also elsewhere on the board
/DDR3-01/DDR301_DQ6: IC9.G2 (DQ6); also elsewhere on the board
/DDR3-01/DDR301_DQ7: IC9.H7 (DQ7); also elsewhere on the board
/DDR3-01/DDR301_DQ8: IC9.D7 (DQ8); also elsewhere on the board
/DDR3-01/DDR301_DQ9: IC9.C3 (DQ9); also elsewhere on the board
/DDR3-01/DDR301_DQ10: IC9.C8 (DQ10); also elsewhere on the board
/DDR3-01/DDR301_DQ11: IC9.C2 (DQ11); also elsewhere on the board
/DDR3-01/DDR301_DQ12: IC9.A7 (DQ12); also elsewhere on the board
/DDR3-01/DDR301_DQ13: IC9.A2 (DQ13); also elsewhere on the board
/DDR3-01/DDR301_DQ14: IC9.B8 (DQ14); also elsewhere on the board
/DDR3-01/DDR301_DQ15: IC9.A3 (DQ15); also elsewhere on the board
/DDR3-01/DDR301_LDM: IC9.E7 (LDM); also elsewhere on the board
/DDR3-01/DDR301_LDQS_N: IC9.G3 (LDQS#); also elsewhere on the board
/DDR3-01/DDR301_LDQS_P: IC9.F3 (LDQS); also elsewhere on the board
/DDR3-01/DDR301_ODT: IC9.K1 (ODT); also elsewhere on the board
/DDR3-01/DDR301_UDM: IC9.D3 (UDM); also elsewhere on the board
/DDR3-01/DDR301_UDQS_N: IC9.B7 (UDQS#); also elsewhere on the board
/DDR3-01/DDR301_UDQS_P: IC9.C7 (UDQS); also elsewhere on the board
/DDR3-01/DDR301_nCAS: IC9.K3 (CAS#), R86.1; also elsewhere on the board
/DDR3-01/DDR301_nCS: IC9.L2 (CS#); also elsewhere on the board
/DDR3-01/DDR301_nRAS: IC9.J3 (RAS#); also elsewhere on the board
/DDR3-01/DDR301_nRST: IC9.T2 (RESET#), R85.1; also elsewhere on the board
/DDR3-01/DDR301_nWE: IC9.L3 (WE#); also elsewhere on the board
/DDR3-01/VCCO_DDR3: C78.1, C79.1, C80.1, C81.1, C82.1, C83.1, C85.1, C86.1, C87.1, C88.1, C89.1, C90.1, C91.1, C92.1, C93.1, C94.1, C95.1, C96.1, C97.1, C98.1, C365.1, C366.1, IC9.A1 (VDDQ_1), IC9.A8 (VDDQ_2), IC9.B2 (VDD_1), IC9.C1 (VDDQ_3), IC9.C9 (VDDQ_4), IC9.D2 (VDDQ_5), IC9.D9 (VDD_2), IC9.E9 (VDDQ_6), IC9.F1 (VDDQ_7), IC9.G7 (VDD_3), IC9.H2 (VDDQ_8), IC9.H9 (VDDQ_9), IC9.K2 (VDD_4), IC9.K8 (VDD_5), IC9.N1 (VDD_6), IC9.N9 (VDD_7), IC9.R1 (VDD_8), IC9.R9 (VDD_9), R88.1; also elsewhere on the board
/DDR3-01/VREF_DDR3: C76.1, C77.1, C84.1, IC9.H1 (VREFDQ), IC9.M8 (VREFCA), R88.2, R89.1
GND: C76.2, C77.2, C78.2, C79.2, C80.2, C81.2, C82.2, C83.2, C84.2, C85.2, C86.2, C87.2, C88.2, C89.2, C90.2, C91.2, C92.2, C93.2, C94.2, C95.2, C96.2, C97.2, C98.2, C365.2, C366.2, IC9.A9 (VSS_1), IC9.B1 (VSSQ_1), IC9.B3 (VSS_2), IC9.B9 (VSSQ_2), IC9.D1 (VSSQ_3), IC9.D8 (VSSQ_4), IC9.E1 (VSS_3), IC9.E2 (VSSQ_5), IC9.E8 (VSSQ_6), IC9.F9 (VSSQ_7), IC9.G1 (VSSQ_8), IC9.G8 (VSS_4), IC9.G9 (VSSQ_9), IC9.J2 (VSS_5), IC9.J8 (VSS_6), IC9.M1 (VSS_7), IC9.M9 (VSS_8), IC9.P1 (VSS_9), IC9.P9 (VSS_10), IC9.T1 (VSS_11), IC9.T9 (VSS_12), R84.2, R85.2, R86.2, R89.2; also elsewhere on the board
unnamed: IC9.L8 (ZQ), R84.1

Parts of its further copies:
C99, C100, C107, C118: 100nF; C_0402_1005Metric; Mfr. Part # 0402B104K500CT; LCSC Part # C152814
C101, C102, C103, C104, C105, C106, C108, C109, C110, C111, C113, C114, C116, C117, C119, C120: 47nF; C_0402_1005Metric; Mfr. Part # C0402C473J8RAC7867; LCSC Part # C2178375
C112, C238: 470nF; C_0402_1005Metric; Mfr. Part # GRM155R71C474KE01D; LCSC Part # C471404
C115, C121, C186: 4.7uF; C_0603_1608Metric; Mfr. Part # GMK107BBJ475KA-T; LCSC Part # C7281848
IC10: MT41K128M16JT-107:K; BGA96C80P9X16_800X1400X120; Mfr. Part # MT41K128M16JT-107:K; LCSC Part # C2841151
R90: 240; R_0402_1005Metric; Mfr. Part # RT0402BRE07240RL; LCSC Part # C728568
R91, R92: 4K7; R_0402_1005Metric; Mfr. Part # WR04X4701FTL; LCSC Part # C163826
R93: 100; R_0402_1005Metric; Mfr. Part # WR04X1000FTL; LCSC Part # C163808
R94, R95: 1K; R_0402_1005Metric; Mfr. Part # MR04X1001FTL; LCSC Part # C327796

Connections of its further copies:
/DDR3-01/VCCO_DDR3: C101.1, C102.1, C103.1, C104.1, C105.1, C106.1, C108.1, C109.1, C110.1, C111.1, C112.1, C113.1, C114.1, C115.1, C116.1, C117.1, C118.1, C119.1, C120.1, C121.1, C186.1, C238.1, IC10.A1 (VDDQ_1), IC10.A8 (VDDQ_2), IC10.B2 (VDD_1), IC10.C1 (VDDQ_3), IC10.C9 (VDDQ_4), IC10.D2 (VDDQ_5), IC10.D9 (VDD_2), IC10.E9 (VDDQ_6), IC10.F1 (VDDQ_7), IC10.G7 (VDD_3), IC10.H2 (VDDQ_8), IC10.H9 (VDDQ_9), IC10.K2 (VDD_4), IC10.K8 (VDD_5), IC10.N1 (VDD_6), IC10.N9 (VDD_7), IC10.R1 (VDD_8), IC10.R9 (VDD_9), R94.1; also elsewhere on the board
/DDR3-2/CK_N: IC10.K7 (CK#), R93.2; also elsewhere on the board
/DDR3-2/CK_P: IC10.J7 (CK), R93.1; also elsewhere on the board
/DDR3-2/DDR301_A0: IC10.N3 (A0); also elsewhere on the board
/DDR3-2/DDR301_A1: IC10.P7 (A1); also elsewhere on the board
/DDR3-2/DDR301_A2: IC10.P3 (A2); also elsewhere on the board
/DDR3-2/DDR301_A3: IC10.N2 (A3); also elsewhere on the board
/DDR3-2/DDR301_A4: IC10.P8 (A4); also elsewhere on the board
/DDR3-2/DDR301_A5: IC10.P2 (A5); also elsewhere on the board
/DDR3-2/DDR301_A6: IC10.R8 (A6); also elsewhere on the board
/DDR3-2/DDR301_A7: IC10.R2 (A7); also elsewhere on the board
/DDR3-2/DDR301_A8: IC10.T8 (A8); also elsewhere on the board
/DDR3-2/DDR301_A9: IC10.R3 (A9); also elsewhere on the board
/DDR3-2/DDR301_A10/AP: IC10.L7 (A10/AP); also elsewhere on the board
/DDR3-2/DDR301_A11: IC10.R7 (A11); also elsewhere on the board
/DDR3-2/DDR301_A12/nBC: IC10.N7 (A12/BC#); also elsewhere on the board
/DDR3-2/DDR301_A13: IC10.T3 (A13); also elsewhere on the board
/DDR3-2/DDR301_A14: IC10.T7 (A14); also elsewhere on the board
/DDR3-2/DDR301_BA0: IC10.M2 (BA0); also elsewhere on the board
/DDR3-2/DDR301_BA1: IC10.N8 (BA1); also elsewhere on the board
/DDR3-2/DDR301_BA2: IC10.M3 (BA2); also elsewhere on the board
/DDR3-2/DDR301_CLKE: IC10.K9 (CKE); also elsewhere on the board
/DDR3-2/DDR301_DQ0: IC10.E3 (DQ0); also elsewhere on the board
/DDR3-2/DDR301_DQ1: IC10.F7 (DQ1); also elsewhere on the board
/DDR3-2/DDR301_DQ2: IC10.F2 (DQ2); also elsewhere on the board
/DDR3-2/DDR301_DQ3: IC10.F8 (DQ3); also elsewhere on the board
/DDR3-2/DDR301_DQ4: IC10.H3 (DQ4); also elsewhere on the board
/DDR3-2/DDR301_DQ5: IC10.H8 (DQ5); also elsewhere on the board
/DDR3-2/DDR301_DQ6: IC10.G2 (DQ6); also elsewhere on the board
/DDR3-2/DDR301_DQ7: IC10.H7 (DQ7); also elsewhere on the board
/DDR3-2/DDR301_DQ8: IC10.D7 (DQ8); also elsewhere on the board
/DDR3-2/DDR301_DQ9: IC10.C3 (DQ9); also elsewhere on the board
/DDR3-2/DDR301_DQ10: IC10.C8 (DQ10); also elsewhere on the board
/DDR3-2/DDR301_DQ11: IC10.C2 (DQ11); also elsewhere on the board
/DDR3-2/DDR301_DQ12: IC10.A7 (DQ12); also elsewhere on the board
/DDR3-2/DDR301_DQ13: IC10.A2 (DQ13); also elsewhere on the board
/DDR3-2/DDR301_DQ14: IC10.B8 (DQ14); also elsewhere on the board
/DDR3-2/DDR301_DQ15: IC10.A3 (DQ15); also elsewhere on the board
/DDR3-2/DDR301_LDM: IC10.E7 (LDM); also elsewhere on the board
/DDR3-2/DDR301_LDQS_N: IC10.G3 (LDQS#); also elsewhere on the board
/DDR3-2/DDR301_LDQS_P: IC10.F3 (LDQS); also elsewhere on the board
/DDR3-2/DDR301_ODT: IC10.K1 (ODT); also elsewhere on the board
/DDR3-2/DDR301_UDM: IC10.D3 (UDM); also elsewhere on the board
/DDR3-2/DDR301_UDQS_N: IC10.B7 (UDQS#); also elsewhere on the board
/DDR3-2/DDR301_UDQS_P: IC10.C7 (UDQS); also elsewhere on the board
/DDR3-2/DDR301_nCAS: IC10.K3 (CAS#), R92.1; also elsewhere on the board
/DDR3-2/DDR301_nCS: IC10.L2 (CS#); also elsewhere on the board
/DDR3-2/DDR301_nRAS: IC10.J3 (RAS#); also elsewhere on the board
/DDR3-2/DDR301_nRST: IC10.T2 (RESET#), R91.1; also elsewhere on the board
/DDR3-2/DDR301_nWE: IC10.L3 (WE#); also elsewhere on the board
/DDR3-2/VREF_DDR3: C99.1, C100.1, C107.1, IC10.H1 (VREFDQ), IC10.M8 (VREFCA), R94.2, R95.1
GND: C99.2, C100.2, C101.2, C102.2, C103.2, C104.2, C105.2, C106.2, C107.2, C108.2, C109.2, C110.2, C111.2, C112.2, C113.2, C114.2, C115.2, C116.2, C117.2, C118.2, C119.2, C120.2, C121.2, C186.2, C238.2, IC10.A9 (VSS_1), IC10.B1 (VSSQ_1), IC10.B3 (VSS_2), IC10.B9 (VSSQ_2), IC10.D1 (VSSQ_3), IC10.D8 (VSSQ_4), IC10.E1 (VSS_3), IC10.E2 (VSSQ_5), IC10.E8 (VSSQ_6), IC10.F9 (VSSQ_7), IC10.G1 (VSSQ_8), IC10.G8 (VSS_4), IC10.G9 (VSSQ_9), IC10.J2 (VSS_5), IC10.J8 (VSS_6), IC10.M1 (VSS_7), IC10.M9 (VSS_8), IC10.P1 (VSS_9), IC10.P9 (VSS_10), IC10.T1 (VSS_11), IC10.T9 (VSS_12), R90.2, R91.2, R92.2, R95.2; also elsewhere on the board
unnamed: IC10.L8 (ZQ), R90.1

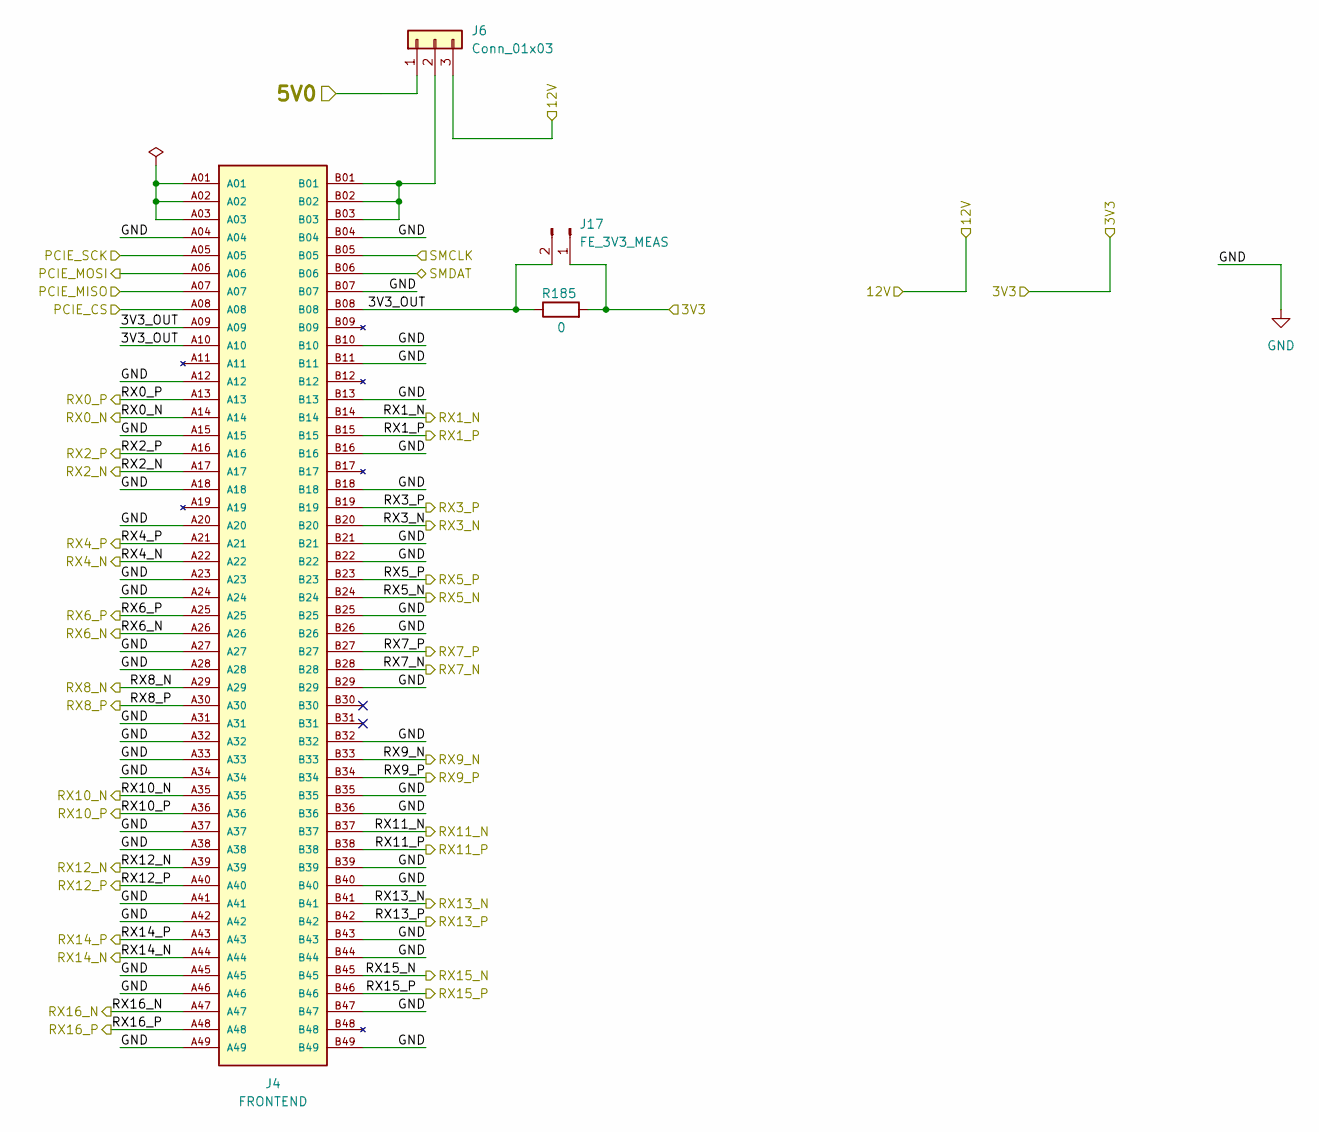
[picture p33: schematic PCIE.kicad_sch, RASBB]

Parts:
J4: FRONTEND; SAMTEC_PCIE-098-02-X-D-EMS3; Mfr. Part # X3157WS-98-9TV30; LCSC Part # C5711253
J6: Conn_01x03; PinHeader_1x03_P2.54mm_Vertical; Mfr. Part # PZ254V-11-03P; LCSC Part # C2937625
J17: FE_3V3_MEAS; PinHeader_1x02_P2.54mm_Vertical; Mfr. Part # PZ254V-11-02P; LCSC Part # C492401
R185: 0; R_1206_3216Metric; Mfr. Part # 1206W4F0000T5E; LCSC Part # C17888

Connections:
/Audio_IN-OUT/3V3: J17.1, R185.2; also elsewhere on the board
/Audio_IN-OUT/5V0: J6.1; also elsewhere on the board
/PCIE/3V3_OUT: J4.A09, J4.A10, J4.B08, J17.2, R185.1
/PCIE/12V: J6.3; also elsewhere on the board
/PCIE/PCIE_CS: J4.A08; also elsewhere on the board
/PCIE/PCIE_MISO: J4.A07; also elsewhere on the board
/PCIE/PCIE_MOSI: J4.A06; also elsewhere on the board
/PCIE/PCIE_SCK: J4.A05; also elsewhere on the board
/PCIE/RX0_N: J4.A14; also elsewhere on the board
/PCIE/RX0_P: J4.A13; also elsewhere on the board
/PCIE/RX1_N: J4.B14; also elsewhere on the board
/PCIE/RX1_P: J4.B15; also elsewhere on the board
/PCIE/RX2_N: J4.A17; also elsewhere on the board
/PCIE/RX2_P: J4.A16; also elsewhere on the board
/PCIE/RX3_N: J4.B20; also elsewhere on the board
/PCIE/RX3_P: J4.B19; also elsewhere on the board
/PCIE/RX4_N: J4.A22; also elsewhere on the board
/PCIE/RX4_P: J4.A21; also elsewhere on the board
/PCIE/RX5_N: J4.B24; also elsewhere on the board
/PCIE/RX5_P: J4.B23; also elsewhere on the board
/PCIE/RX6_N: J4.A26; also elsewhere on the board
/PCIE/RX6_P: J4.A25; also elsewhere on the board
/PCIE/RX7_N: J4.B28; also elsewhere on the board
/PCIE/RX7_P: J4.B27; also elsewhere on the board
/PCIE/RX8_N: J4.A29; also elsewhere on the board
/PCIE/RX8_P: J4.A30; also elsewhere on the board
/PCIE/RX9_N: J4.B33; also elsewhere on the board
/PCIE/RX9_P: J4.B34; also elsewhere on the board
/PCIE/RX10_N: J4.A35; also elsewhere on the board
/PCIE/RX10_P: J4.A36; also elsewhere on the board
/PCIE/RX11_N: J4.B37; also elsewhere on the board
/PCIE/RX11_P: J4.B38; also elsewhere on the board
/PCIE/RX12_N: J4.A39; also elsewhere on the board
/PCIE/RX12_P: J4.A40; also elsewhere on the board
/PCIE/RX13_N: J4.B41; also elsewhere on the board
/PCIE/RX13_P: J4.B42; also elsewhere on the board
/PCIE/RX14_N: J4.A44; also elsewhere on the board
/PCIE/RX14_P: J4.A43; also elsewhere on the board
/PCIE/RX15_N: J4.B45; also elsewhere on the board
/PCIE/RX15_P: J4.B46; also elsewhere on the board
/PCIE/RX16_N: J4.A47; also elsewhere on the board
/PCIE/RX16_P: J4.A48; also elsewhere on the board
/PCIE/SMCLK: J4.B05; also elsewhere on the board
/PCIE/SMDAT: J4.B06; also elsewhere on the board
GND: J4.A04, J4.A12, J4.A15, J4.A18, J4.A20, J4.A23, J4.A24, J4.A27, J4.A28, J4.A31, J4.A32, J4.A33, J4.A34, J4.A37, J4.A38, J4.A41, J4.A42, J4.A45, J4.A46, J4.A49, J4.B04, J4.B07, J4.B10, J4.B11, J4.B13, J4.B16, J4.B18, J4.B21, J4.B22, J4.B25, J4.B26, J4.B29, J4.B32, J4.B35, J4.B36, J4.B39, J4.B40, J4.B43, J4.B44, J4.B47, J4.B49; also elsewhere on the board
unnamed: J4.A01, J4.A02, J4.A03
unnamed: J4.B01, J4.B02, J4.B03, J6.2

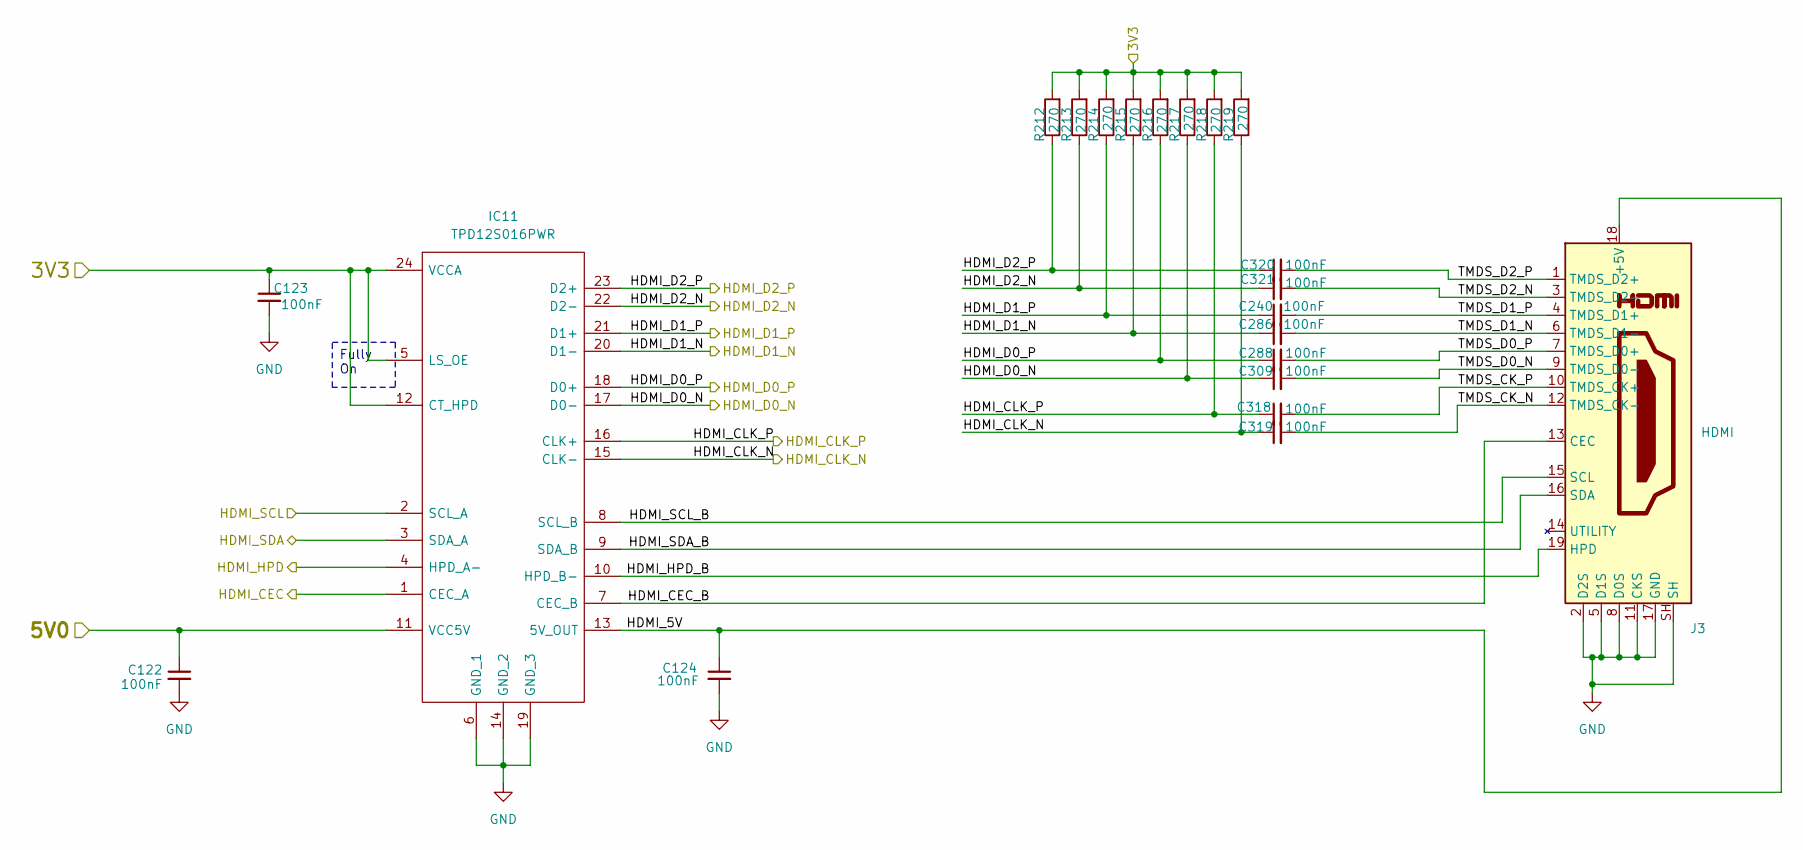
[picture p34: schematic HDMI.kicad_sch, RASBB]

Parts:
C122, C123, C124, C240, C286, C288, C309, C318, C319, C320, C321: 100nF; C_0402_1005Metric; Mfr. Part # 0402B104K500CT; LCSC Part # C152814
IC11: TPD12S016PWR; SOP65P640X120-24N; Mfr. Part # TPD12S016PWR; LCSC Part # C201665
J3: HDMI; HDMI-001A; Mfr. Part # HDMI-001A; LCSC Part # C41347845
R212, R213, R214, R215, R216, R217, R218, R219: 270; R_0402_1005Metric; Mfr. Part # SR04X271JTL; LCSC Part # C880838

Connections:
/Audio_IN-OUT/3V3: C123.1, IC11.5 (LS_OE), IC11.12 (CT_HPD), IC11.24 (VCCA), R212.2, R213.2, R214.2, R215.2, R216.2, R217.2, R218.2, R219.2; also elsewhere on the board
/Audio_IN-OUT/5V0: C122.1, IC11.11 (VCC5V); also elsewhere on the board
/FPGA-01/F1_B15_C15: IC11.4 (HPD_A-); also elsewhere on the board
/FPGA-01/F1_B15_D15: IC11.3 (SDA_A); also elsewhere on the board
/FPGA-01/F1_B15_E15: IC11.2 (SCL_A); also elsewhere on the board
/FPGA-01/F1_B15_E16: IC11.1 (CEC_A); also elsewhere on the board
/HDMI/HDMI_5V: C124.1, IC11.13 (5V_OUT), J3.18 (+5V)
/HDMI/HDMI_CEC_B: IC11.7 (CEC_B), J3.13 (CEC)
/HDMI/HDMI_CLK_N: C319.1, IC11.15 (CLK-), R219.1; also elsewhere on the board
/HDMI/HDMI_CLK_P: C318.1, IC11.16 (CLK+), R218.1; also elsewhere on the board
/HDMI/HDMI_D0_N: C309.1, IC11.17 (D0-), R217.1; also elsewhere on the board
/HDMI/HDMI_D0_P: C288.1, IC11.18 (D0+), R216.1; also elsewhere on the board
/HDMI/HDMI_D1_N: C286.1, IC11.20 (D1-), R215.1; also elsewhere on the board
/HDMI/HDMI_D1_P: C240.1, IC11.21 (D1+), R214.1; also elsewhere on the board
/HDMI/HDMI_D2_N: C321.1, IC11.22 (D2-), R213.1; also elsewhere on the board
/HDMI/HDMI_D2_P: C320.1, IC11.23 (D2+), R212.1; also elsewhere on the board
/HDMI/HDMI_HPD_B: IC11.10 (HPD_B-), J3.19 (HPD)
/HDMI/HDMI_SCL_B: IC11.8 (SCL_B), J3.15 (SCL)
/HDMI/HDMI_SDA_B: IC11.9 (SDA_B), J3.16 (SDA)
/HDMI/TMDS_CK_N: C319.2, J3.12 (TMDS_CK-)
/HDMI/TMDS_CK_P: C318.2, J3.10 (TMDS_CK+)
/HDMI/TMDS_D0_N: C309.2, J3.9 (TMDS_D0-)
/HDMI/TMDS_D0_P: C288.2, J3.7 (TMDS_D0+)
/HDMI/TMDS_D1_N: C286.2, J3.6 (TMDS_D1-)
/HDMI/TMDS_D1_P: C240.2, J3.4 (TMDS_D1+)
/HDMI/TMDS_D2_N: C321.2, J3.3 (TMDS_D2-)
/HDMI/TMDS_D2_P: C320.2, J3.1 (TMDS_D2+)
GND: C122.2, C123.2, C124.2, IC11.6 (GND_1), IC11.14 (GND_2), IC11.19 (GND_3), J3.2 (D2S), J3.5 (D1S), J3.8 (D0S), J3.11 (CKS), J3.17 (GND), J3.SH; also elsewhere on the board

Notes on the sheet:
Fully On

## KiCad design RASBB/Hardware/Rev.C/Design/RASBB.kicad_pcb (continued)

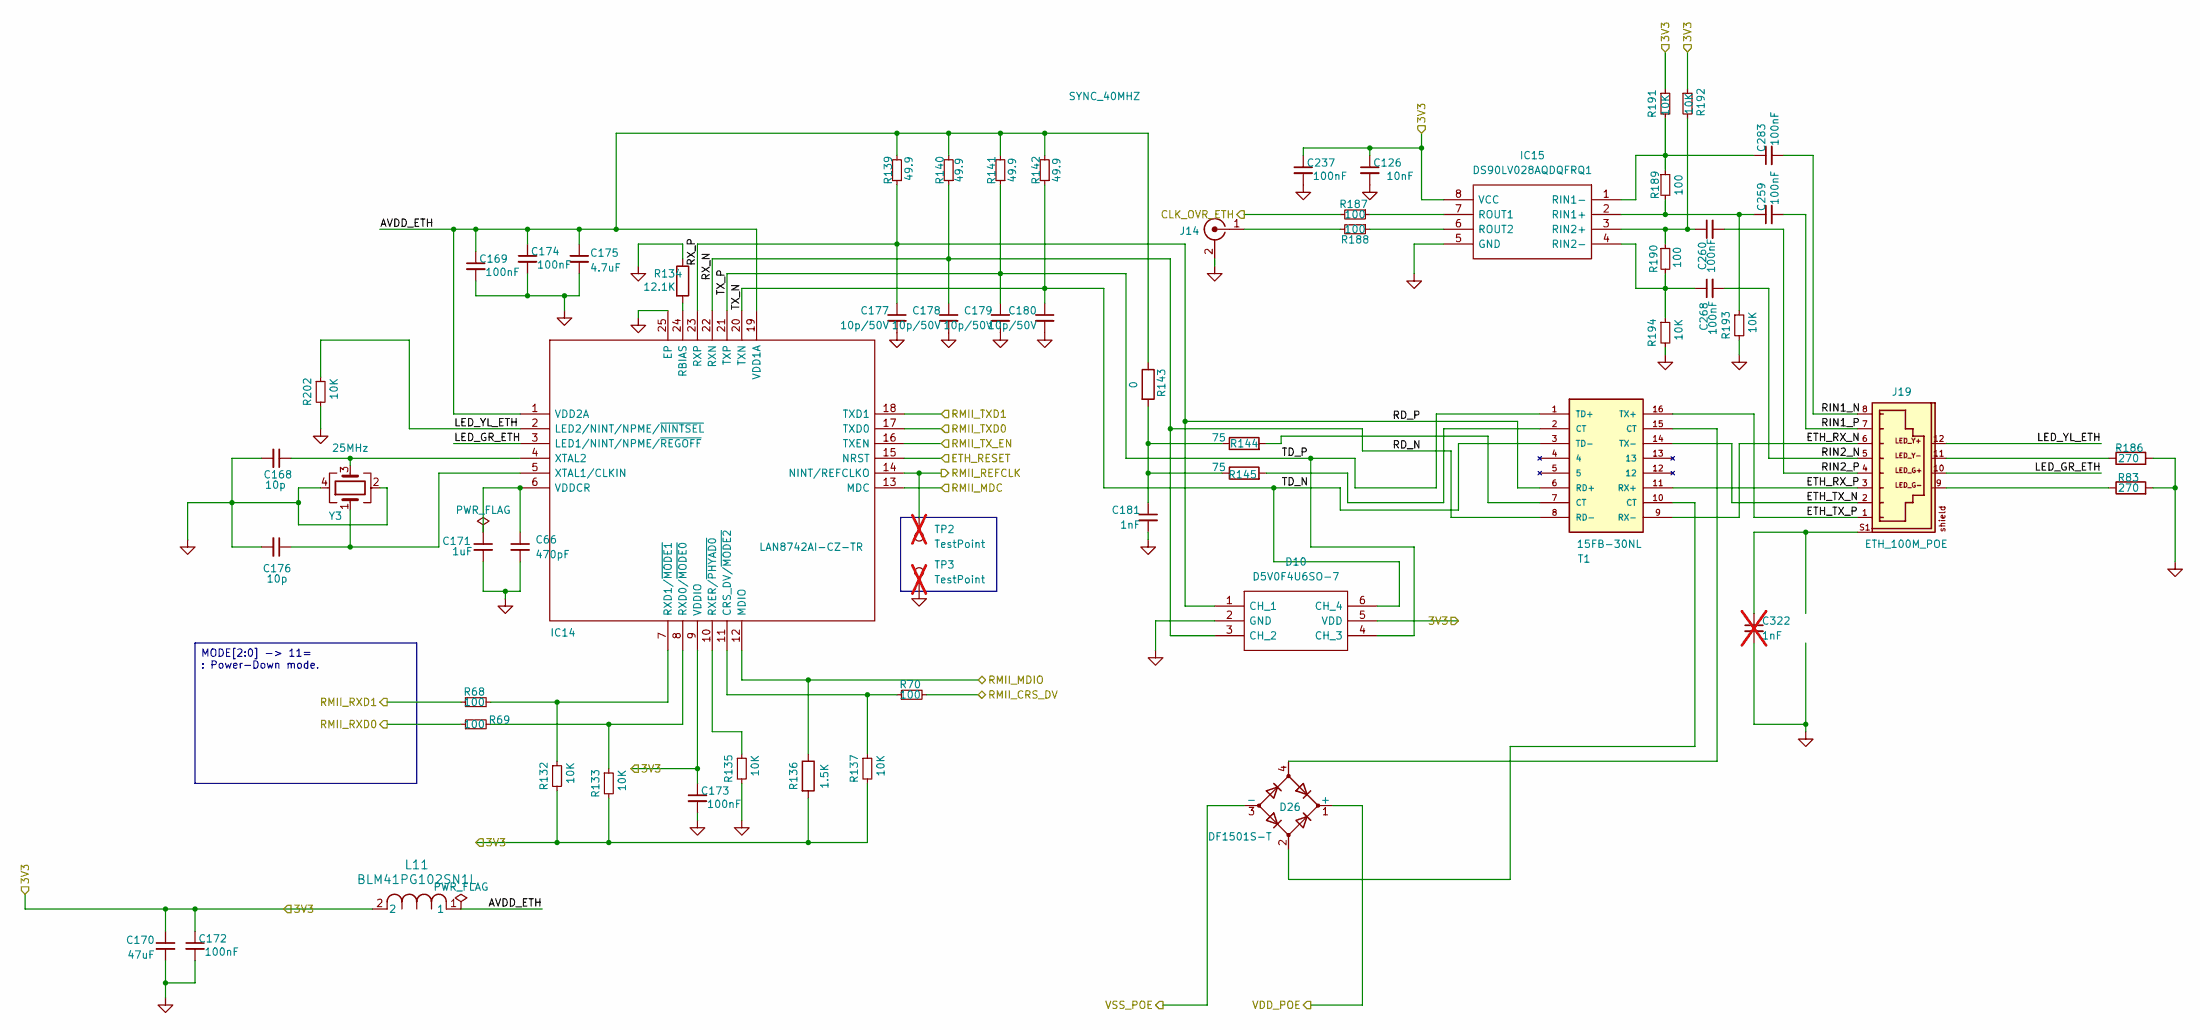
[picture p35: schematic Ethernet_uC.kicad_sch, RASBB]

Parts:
C66: 470pF; C_0402_1005Metric; Mfr. Part # CC0402JRNPO7BN471; LCSC Part # C526993
C126: 10nF; C_0402_1005Metric; Mfr. Part # 0402B103K500CT; LCSC Part # C301927
C168, C176: 10p; C_0402_1005Metric; Mfr. Part # 0402N100J500CT; LCSC Part # C301961
C169, C172, C173, C174, C237, C259, C260, C268, C283: 100nF; C_0402_1005Metric; Mfr. Part # 0402B104K500CT; LCSC Part # C152814
C170: 47uF; C_0805_2012Metric; Mfr. Part # GRM21BR61A476ME15L; LCSC Part # C124129
C171: 1uF; C_0402_1005Metric; Mfr. Part # 0402X105M160CT; LCSC Part # C3889771
C175: 4.7uF; C_0603_1608Metric; Mfr. Part # GMK107BBJ475KA-T; LCSC Part # C7281848
C177, C178, C179, C180: 10p/50V; C_0603_1608Metric; Mfr. Part # 0603N100J500CT; LCSC Part # C152928
C181: 1nF; C_1206_3216Metric; Mfr. Part # 1206B102K202CT; LCSC Part # C303946
C322: 1nF; C_1206_3216Metric; not fitted
D10: D5V0F4U6SO-7; SOT95P285X140-6N; Mfr. Part # D5V0F4U6SO-7; LCSC Part # C445539
D26: DF1501S-T; DF1501ST; Mfr. Part # DF1501S-T; LCSC Part # C155338
IC14: LAN8742AI-CZ-TR; QFN50P400X400X100-25N-D; Mfr. Part # LAN8742AI-CZ-TR; LCSC Part # C621425
IC15: DS90LV028AQDQFRQ1; SON50P200X200X80-8N; Mouser Part Number 595-S90LV028AQDQFRQ1
J14: SYNC_40MHZ; J_Wurth_WR-UMRF_636101112001; Mfr. Part # 636101112001
J19: ETH_100M_POE; HC-WK88-H16-DB; Mfr. Part # HC-WK88-H16-DB; LCSC Part # C7501824
L11: BLM41PG102SN1L; IND_BLM41_1806_MUR-M; Mfr. Part # BLM41PG102SN1L; LCSC Part # C88999
R68, R69, R70, R187, R188, R189, R190: 100; R_0402_1005Metric; Mfr. Part # WR04X1000FTL; LCSC Part # C163808
R83, R186: 270; R_0402_1005Metric; Mfr. Part # SR04X271JTL; LCSC Part # C880838
R132, R133, R135, R137, R191, R192, R193, R194, R202: 10K; R_0402_1005Metric; Mfr. Part # WR04X1002FTL; LCSC Part # C163810
R134: 12.1K; R_0402_1005Metric; Mfr. Part # WR04X1212FTL; LCSC Part # C168199
R136: 1.5K; R_0402_1005Metric; Mfr. Part # WR04X152JTL; LCSC Part # C384376
R139, R140, R141, R142: 49.9; R_0402_1005Metric; Mfr. Part # RMCF0402FT49R9; LCSC Part # C4229190
R143: 0; R_0603_1608Metric; Mfr. Part # RCS06030000Z0EC; LCSC Part # C2094997
R144, R145: 75; R_0603_1608Metric; Mfr. Part # ESR03EZPF75R0; LCSC Part # C2074227
T1: 15FB-30NL; SOIC127P940X597-16N; Mfr. Part # 15FB-30NL; LCSC Part # C2987675
TP2, TP3: TestPoint; TestPoint_Pad_D1.0mm; not fitted
Y3: 25MHz; Crystal_SMD_3225-4Pin_3.2x2.5mm; Mfr. Part # XL2EL89CSI-111YLC-25M; LCSC Part # C5280577

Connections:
/Audio_IN-OUT/3V3: C126.1, C170.1, C172.1, C173.1, C237.1, D10.5 (VDD), IC14.9 (VDDIO), IC15.8 (VCC), L11.2, R132.2, R133.2, R136.2, R137.2, R191.1, R192.1; also elsewhere on the board
/CLK_OVR_ETH: R187.2; also elsewhere on the board
/Ethernet_uC/AVDD_ETH: C169.1, C174.1, C175.1, IC14.1 (VDD2A), IC14.19 (VDD1A), L11.1, R139.2, R140.2, R141.2, R142.2, R143.1
/Ethernet_uC/ETH_RESET: IC14.15 (NRST); also elsewhere on the board
/Ethernet_uC/ETH_RX_N: J19.6, T1.9 (RX-)
/Ethernet_uC/ETH_RX_P: J19.3, T1.11 (RX+)
/Ethernet_uC/ETH_TX_N: J19.2, T1.14 (TX-)
/Ethernet_uC/ETH_TX_P: J19.1, T1.16 (TX+)
/Ethernet_uC/LED_GR_ETH: IC14.3 (LED1/NINT/NPME/~REGOFF), J19.10
/Ethernet_uC/LED_YL_ETH: IC14.2 (LED2/NINT/NPME/~NINTSEL), J19.12, R202.1
/Ethernet_uC/RD_N: C178.1, D10.3 (CH_2), IC14.22 (RXN), R140.1, T1.8 (RD-)
/Ethernet_uC/RD_P: C177.1, D10.1 (CH_1), IC14.23 (RXP), R139.1, T1.6 (RD+)
/Ethernet_uC/RIN1_N: C283.2, J19.8
/Ethernet_uC/RIN1_P: C259.2, J19.7
/Ethernet_uC/RIN2_N: C268.2, J19.5
/Ethernet_uC/RIN2_P: C260.2, J19.4
/Ethernet_uC/RMII_CRS_DV: R70.2; also elsewhere on the board
/Ethernet_uC/RMII_MDC: IC14.13 (MDC); also elsewhere on the board
/Ethernet_uC/RMII_MDIO: IC14.12 (MDIO), R136.1; also elsewhere on the board
/Ethernet_uC/RMII_REFCLK: IC14.14 (NINT/REFCLKO), TP2.1 (1_1); also elsewhere on the board
/Ethernet_uC/RMII_RXD0: R69.1; also elsewhere on the board
/Ethernet_uC/RMII_RXD1: R68.1; also elsewhere on the board
/Ethernet_uC/RMII_TXD0: IC14.17 (TXD0); also elsewhere on the board
/Ethernet_uC/RMII_TXD1: IC14.18 (TXD1); also elsewhere on the board
/Ethernet_uC/RMII_TX_EN: IC14.16 (TXEN); also elsewhere on the board
/Ethernet_uC/TD_N: C180.1, D10.6 (CH_4), IC14.20 (TXN), R142.1, T1.3 (TD-)
/Ethernet_uC/TD_P: C179.1, D10.4 (CH_3), IC14.21 (TXP), R141.1, T1.1 (TD+)
/VDC_IN: D26.1 (+); also elsewhere on the board
/VSS_POE: D26.3 (-); also elsewhere on the board
GND: C66.2, C126.2, C168.2, C169.2, C170.2, C171.2, C172.2, C173.2, C174.2, C175.2, C176.2, C177.2, C178.2, C179.2, C180.2, C181.2, C237.2, C322.2, D10.2 (GND), IC14.25 (EP), IC15.5 (GND), J14.2 (Ext), R83.2, R134.1, R135.2, R186.2, R193.2, R194.2, R202.2, TP3.1 (1_1), Y3.2, Y3.4; also elsewhere on the board
unnamed: C181.1, R143.2, R144.1, R145.1
unnamed 446: C322.1, J19.S1, J19.S2; also elsewhere on the board
unnamed: D26.2, T1.10 (CT)
unnamed: D26.4, T1.15 (CT)
unnamed: IC14.11 (CRS_DV/~MODE2), R70.1, R137.1
unnamed: IC14.24 (RBIAS), R134.2
unnamed: IC14.8 (RXD0/~MODE0), R69.2, R133.1
unnamed: IC14.7 (RXD1/~MODE1), R68.2, R132.1
unnamed: IC14.10 (RXER/~PHYAD0), R135.1
unnamed: C66.1, C171.1, IC14.6 (VDDCR)
unnamed: C176.1, IC14.5 (XTAL1/CLKIN), Y3.1
unnamed: C168.1, IC14.4 (XTAL2), Y3.3
unnamed: C259.1, IC15.2 (RIN1+), R189.2, R193.1
unnamed: C283.1, IC15.1 (RIN1-), R189.1, R191.2
unnamed: C260.1, IC15.3 (RIN2+), R190.1, R192.2
unnamed: C268.1, IC15.4 (RIN2-), R190.2, R194.1
unnamed: IC15.7 (ROUT1), R187.1
unnamed: IC15.6 (ROUT2), R188.1
unnamed: J14.1 (In), R188.2
unnamed: J19.9, R83.1
unnamed: J19.11, R186.1
unnamed: R144.2, T1.7 (CT)
unnamed: R145.2, T1.2 (CT)

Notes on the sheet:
MODE[2:0] -> 11= : Power-Down mode.

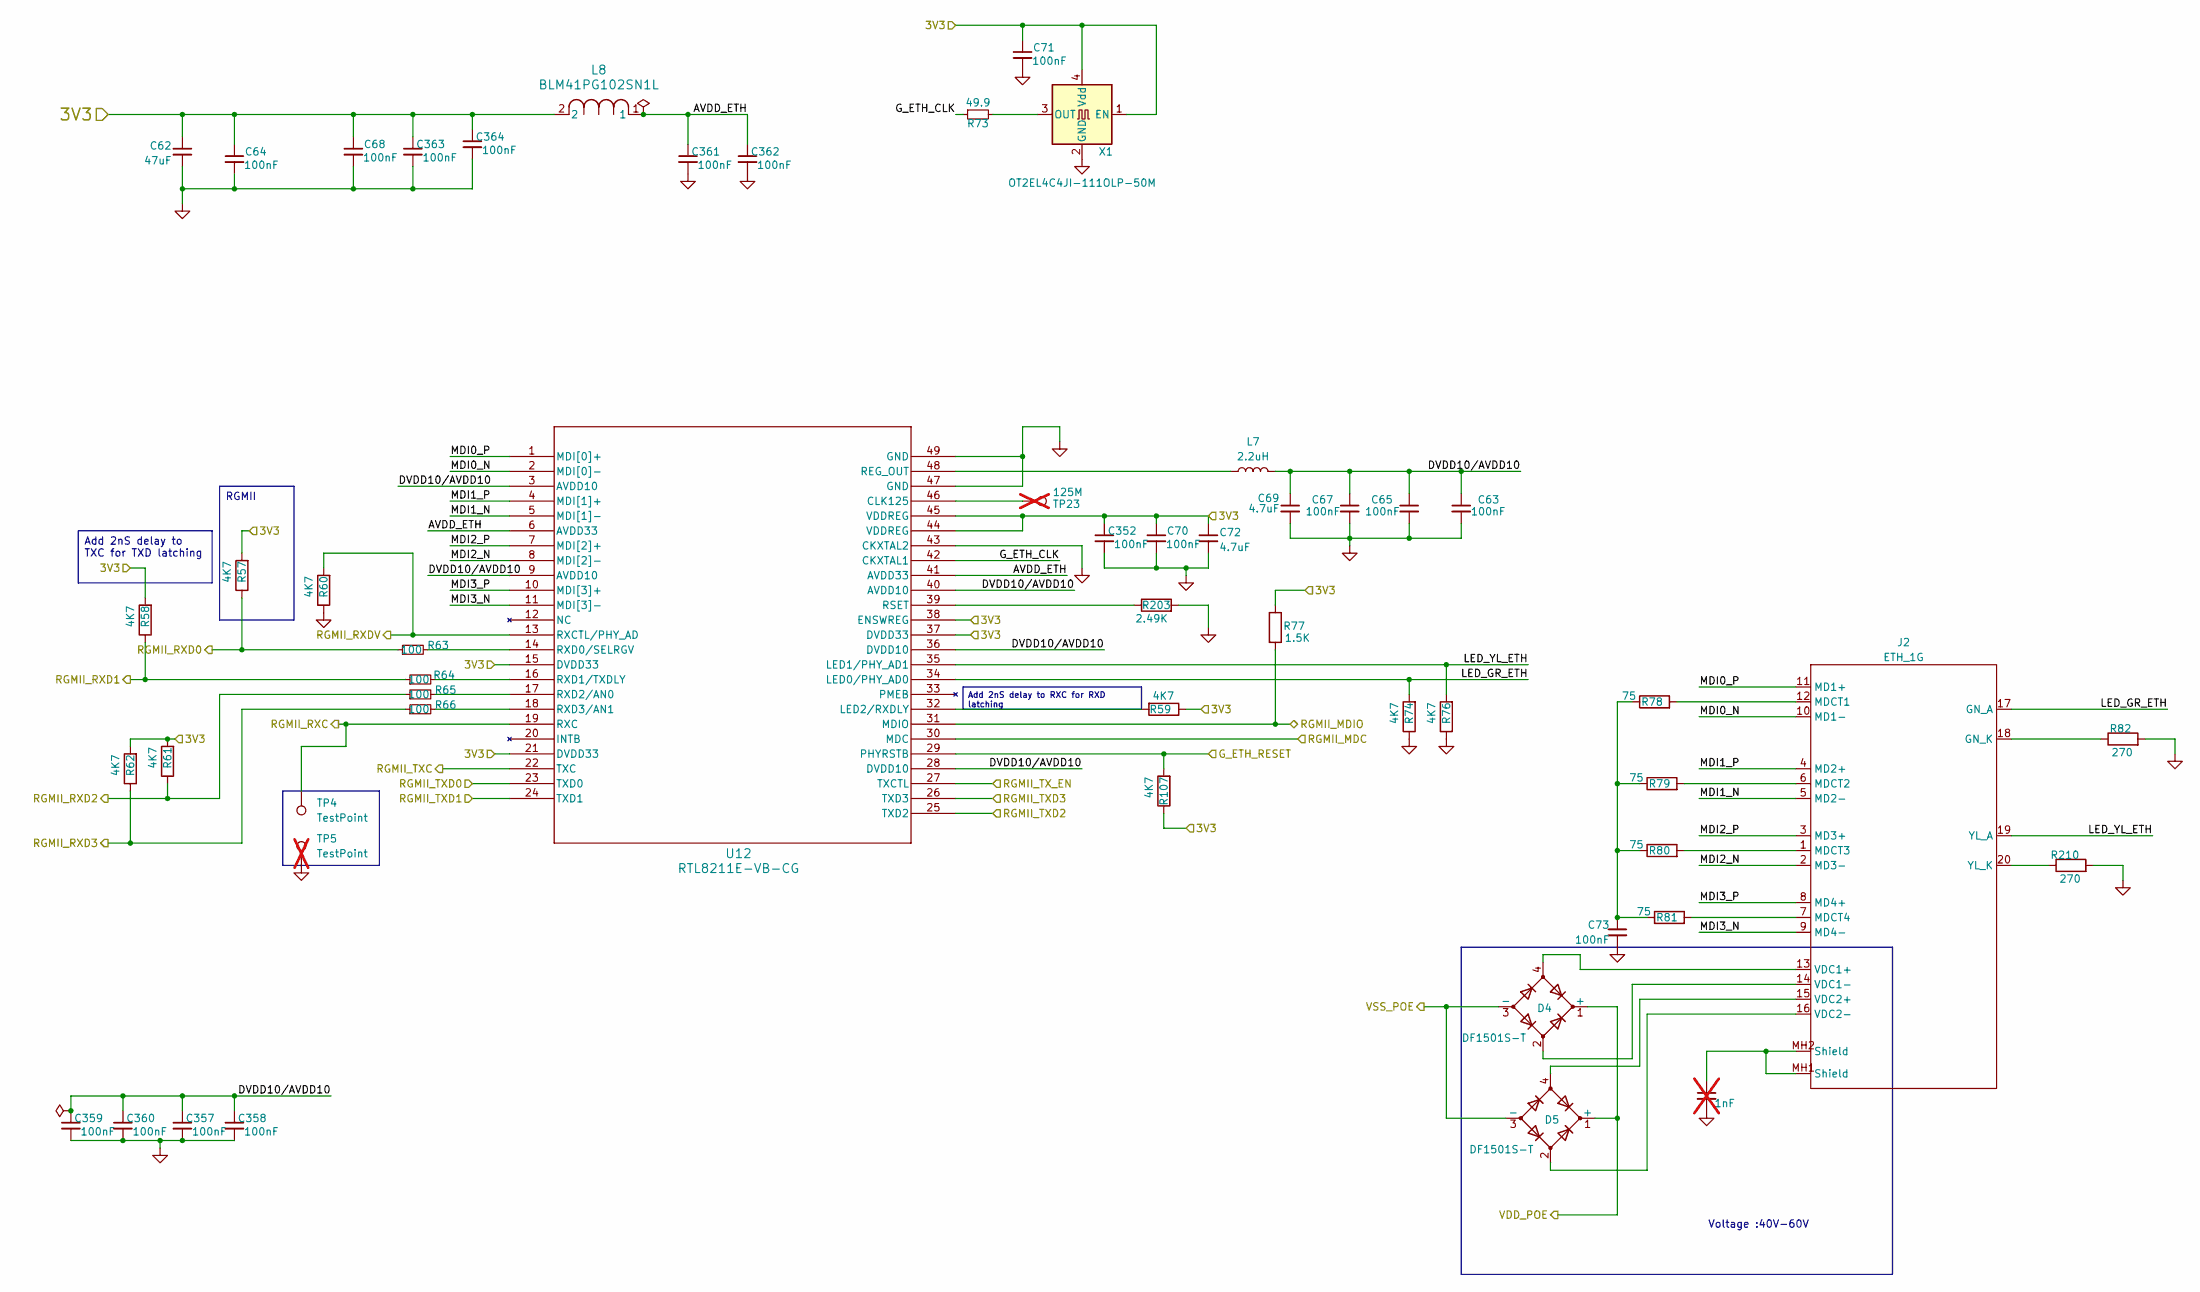
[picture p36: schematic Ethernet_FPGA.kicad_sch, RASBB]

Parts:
C62: 47uF; C_0805_2012Metric; Mfr. Part # GRM21BR61A476ME15L; LCSC Part # C124129
C63, C64, C65, C67, C68, C70, C71, C352, C357, C358, C359, C360, C361, C362, C363, C364: 100nF; C_0402_1005Metric; Mfr. Part # 0402B104K500CT; LCSC Part # C152814
C69, C72: 4.7uF; C_0402_1005Metric; Mfr. Part # GRM155R61A475KEAAD; LCSC Part # C77004
C73: 100nF; C_2220_5750Metric; Mfr. Part # FV55X104K202EGG; LCSC Part # C5290327
C74: 1nF; C_1206_3216Metric; not fitted
D4, D5: DF1501S-T; DF1501ST; Mfr. Part # DF1501S-T; LCSC Part # C155338
J2: ETH_1G; JK00229NL; Mfr. Part # HR911196AE; LCSC Part # C5149194
L7: 2.2uH; L_1206_3216Metric; Mfr. Part # MGFL3216F2R2MT-LF; LCSC Part # C486337
L8: BLM41PG102SN1L; IND_BLM41_1806_MUR-M; Mfr. Part # BLM41PG102SN1L; LCSC Part # C88999
R57, R58, R59, R60, R61, R62, R74, R76, R107: 4K7; R_0402_1005Metric; Mfr. Part # WR04X4701FTL; LCSC Part # C163826
R63, R64, R65, R66: 100; R_0402_1005Metric; Mfr. Part # WR04X1000FTL; LCSC Part # C163808
R73: 49.9; R_0402_1005Metric; Mfr. Part # RMCF0402FT49R9; LCSC Part # C4229190
R77: 1.5K; R_0402_1005Metric; Mfr. Part # WR04X152JTL; LCSC Part # C384376
R78, R79, R80, R81: 75; R_0603_1608Metric; Mfr. Part # ESR03EZPF75R0; LCSC Part # C2074227
R82, R210: 270; R_0402_1005Metric; Mfr. Part # SR04X271JTL; LCSC Part # C880838
R203: 2.49K; R_0402_1005Metric; Mfr. Part # RC0402FR-072K49L; LCSC Part # C145071
TP4: TestPoint; TestPoint_Pad_D1.0mm
TP5: TestPoint; TestPoint_Pad_D1.0mm; not fitted
TP23: 125M; TestPoint_Pad_D1.0mm; not fitted
U12: RTL8211E-VB-CG; QFN48_6X6X0P85_RTK; Mfr. Part # RTL8211E-VB-CG; LCSC Part # C90735
X1: OT2EL4C4JI-111OLP-50M; Oscillator_SMD_Abracon_ASE-4Pin_3.2x2.5mm; Mfr. Part # OT2EL4C4JI-111OLP-50M; LCSC Part # C5203552

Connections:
/Audio_IN-OUT/3V3: C62.1, C64.1, C68.1, C70.1, C71.1, C72.1, C352.1, C363.1, C364.1, L8.2, R57.2, R58.2, R59.1, R61.2, R62.2, R77.1, R107.1, U12.15 (DVDD33), U12.21 (DVDD33), U12.37 (DVDD33), U12.38 (ENSWREG), U12.44 (VDDREG), U12.45 (VDDREG), X1.1 (EN), X1.4 (Vdd); also elsewhere on the board
/Ethernet_FPGA/AVDD_ETH: C361.1, C362.1, L8.1, U12.6 (AVDD33), U12.41 (AVDD33)
/Ethernet_FPGA/DVDD10/AVDD10: C63.1, C65.1, C67.1, C69.1, C357.1, C358.1, C359.1, C360.1, L7.1, U12.3 (AVDD10), U12.9 (AVDD10), U12.28 (DVDD10), U12.36 (DVDD10), U12.40 (AVDD10)
/Ethernet_FPGA/G_ETH_CLK: R73.1, U12.42 (CKXTAL1)
/Ethernet_FPGA/G_ETH_RESET: R107.2, U12.29 (PHYRSTB); also elsewhere on the board
/Ethernet_FPGA/LED_GR_ETH: J2.17 (GN_A), R74.2, U12.34 (LED0/PHY_AD0)
/Ethernet_FPGA/LED_YL_ETH: J2.19 (YL_A), R76.2, U12.35 (LED1/PHY_AD1)
/Ethernet_FPGA/MDI0_N: J2.10 (MD1-), U12.2 (MDI[0]-)
/Ethernet_FPGA/MDI0_P: J2.11 (MD1+), U12.1 (MDI[0]+)
/Ethernet_FPGA/MDI1_N: J2.5 (MD2-), U12.5 (MDI[1]-)
/Ethernet_FPGA/MDI1_P: J2.4 (MD2+), U12.4 (MDI[1]+)
/Ethernet_FPGA/MDI2_N: J2.2 (MD3-), U12.8 (MDI[2]-)
/Ethernet_FPGA/MDI2_P: J2.3 (MD3+), U12.7 (MDI[2]+)
/Ethernet_FPGA/MDI3_N: J2.9 (MD4-), U12.11 (MDI[3]-)
/Ethernet_FPGA/MDI3_P: J2.8 (MD4+), U12.10 (MDI[3]+)
/Ethernet_FPGA/RGMII_MDC: U12.30 (MDC); also elsewhere on the board
/Ethernet_FPGA/RGMII_MDIO: R77.2, U12.31 (MDIO); also elsewhere on the board
/Ethernet_FPGA/RGMII_RXC: TP4.1 (1_1), U12.19 (RXC); also elsewhere on the board
/Ethernet_FPGA/RGMII_RXD0: R57.1, R63.1; also elsewhere on the board
/Ethernet_FPGA/RGMII_RXD1: R58.1, R64.1; also elsewhere on the board
/Ethernet_FPGA/RGMII_RXD2: R61.1, R65.1; also elsewhere on the board
/Ethernet_FPGA/RGMII_RXD3: R62.1, R66.1; also elsewhere on the board
/Ethernet_FPGA/RGMII_RXDV: R60.2, U12.13 (RXCTL/PHY_AD); also elsewhere on the board
/Ethernet_FPGA/RGMII_TXC: U12.22 (TXC); also elsewhere on the board
/Ethernet_FPGA/RGMII_TXD0: U12.23 (TXD0); also elsewhere on the board
/Ethernet_FPGA/RGMII_TXD1: U12.24 (TXD1); also elsewhere on the board
/Ethernet_FPGA/RGMII_TXD2: U12.25 (TXD2); also elsewhere on the board
/Ethernet_FPGA/RGMII_TXD3: U12.26 (TXD3); also elsewhere on the board
/Ethernet_FPGA/RGMII_TX_EN: U12.27 (TXCTL); also elsewhere on the board
/VDC_IN: D4.1 (+), D5.1 (+); also elsewhere on the board
/VSS_POE: D4.3 (-), D5.3 (-); also elsewhere on the board
GND: C62.2, C63.2, C64.2, C65.2, C67.2, C68.2, C69.2, C70.2, C71.2, C72.2, C73.2, C74.2, C352.2, C357.2, C358.2, C359.2, C360.2, C361.2, C362.2, C363.2, C364.2, R60.1, R74.1, R76.1, R82.2, R203.2, R210.2, TP5.1 (1_1), U12.43 (CKXTAL2), U12.47 (GND), U12.49 (GND), X1.2 (GND); also elsewhere on the board
unnamed: C73.1, R78.1, R79.1, R80.1, R81.1
unnamed: C74.1, J2.MH1 (Shield), J2.MH2 (Shield)
unnamed: J2.18 (GN_K), R82.1
unnamed: J2.12 (MDCT1), R78.2
unnamed: J2.6 (MDCT2), R79.2
unnamed: J2.1 (MDCT3), R80.2
unnamed: J2.7 (MDCT4), R81.2
unnamed: D4.4, J2.13 (VDC1+)
unnamed: D4.2, J2.14 (VDC1-)
unnamed: D5.4, J2.15 (VDC2+)
unnamed: D5.2, J2.16 (VDC2-)
unnamed: J2.20 (YL_K), R210.1
unnamed: TP23.1 (1_1), U12.46 (CLK125)
unnamed: R59.2, U12.32 (LED2/RXDLY)
unnamed: L7.2, U12.48 (REG_OUT)
unnamed: R203.1, U12.39 (RSET)
unnamed: R63.2, U12.14 (RXD0/SELRGV)
unnamed: R64.2, U12.16 (RXD1/TXDLY)
unnamed: R65.2, U12.17 (RXD2/AN0)
unnamed: R66.2, U12.18 (RXD3/AN1)
unnamed: R73.2, X1.3 (OUT)

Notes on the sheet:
Voltage :40V-60V
Add 2nS delay to TXC for TXD latching
RGMII
Add 2nS delay to RXC for RXD latching

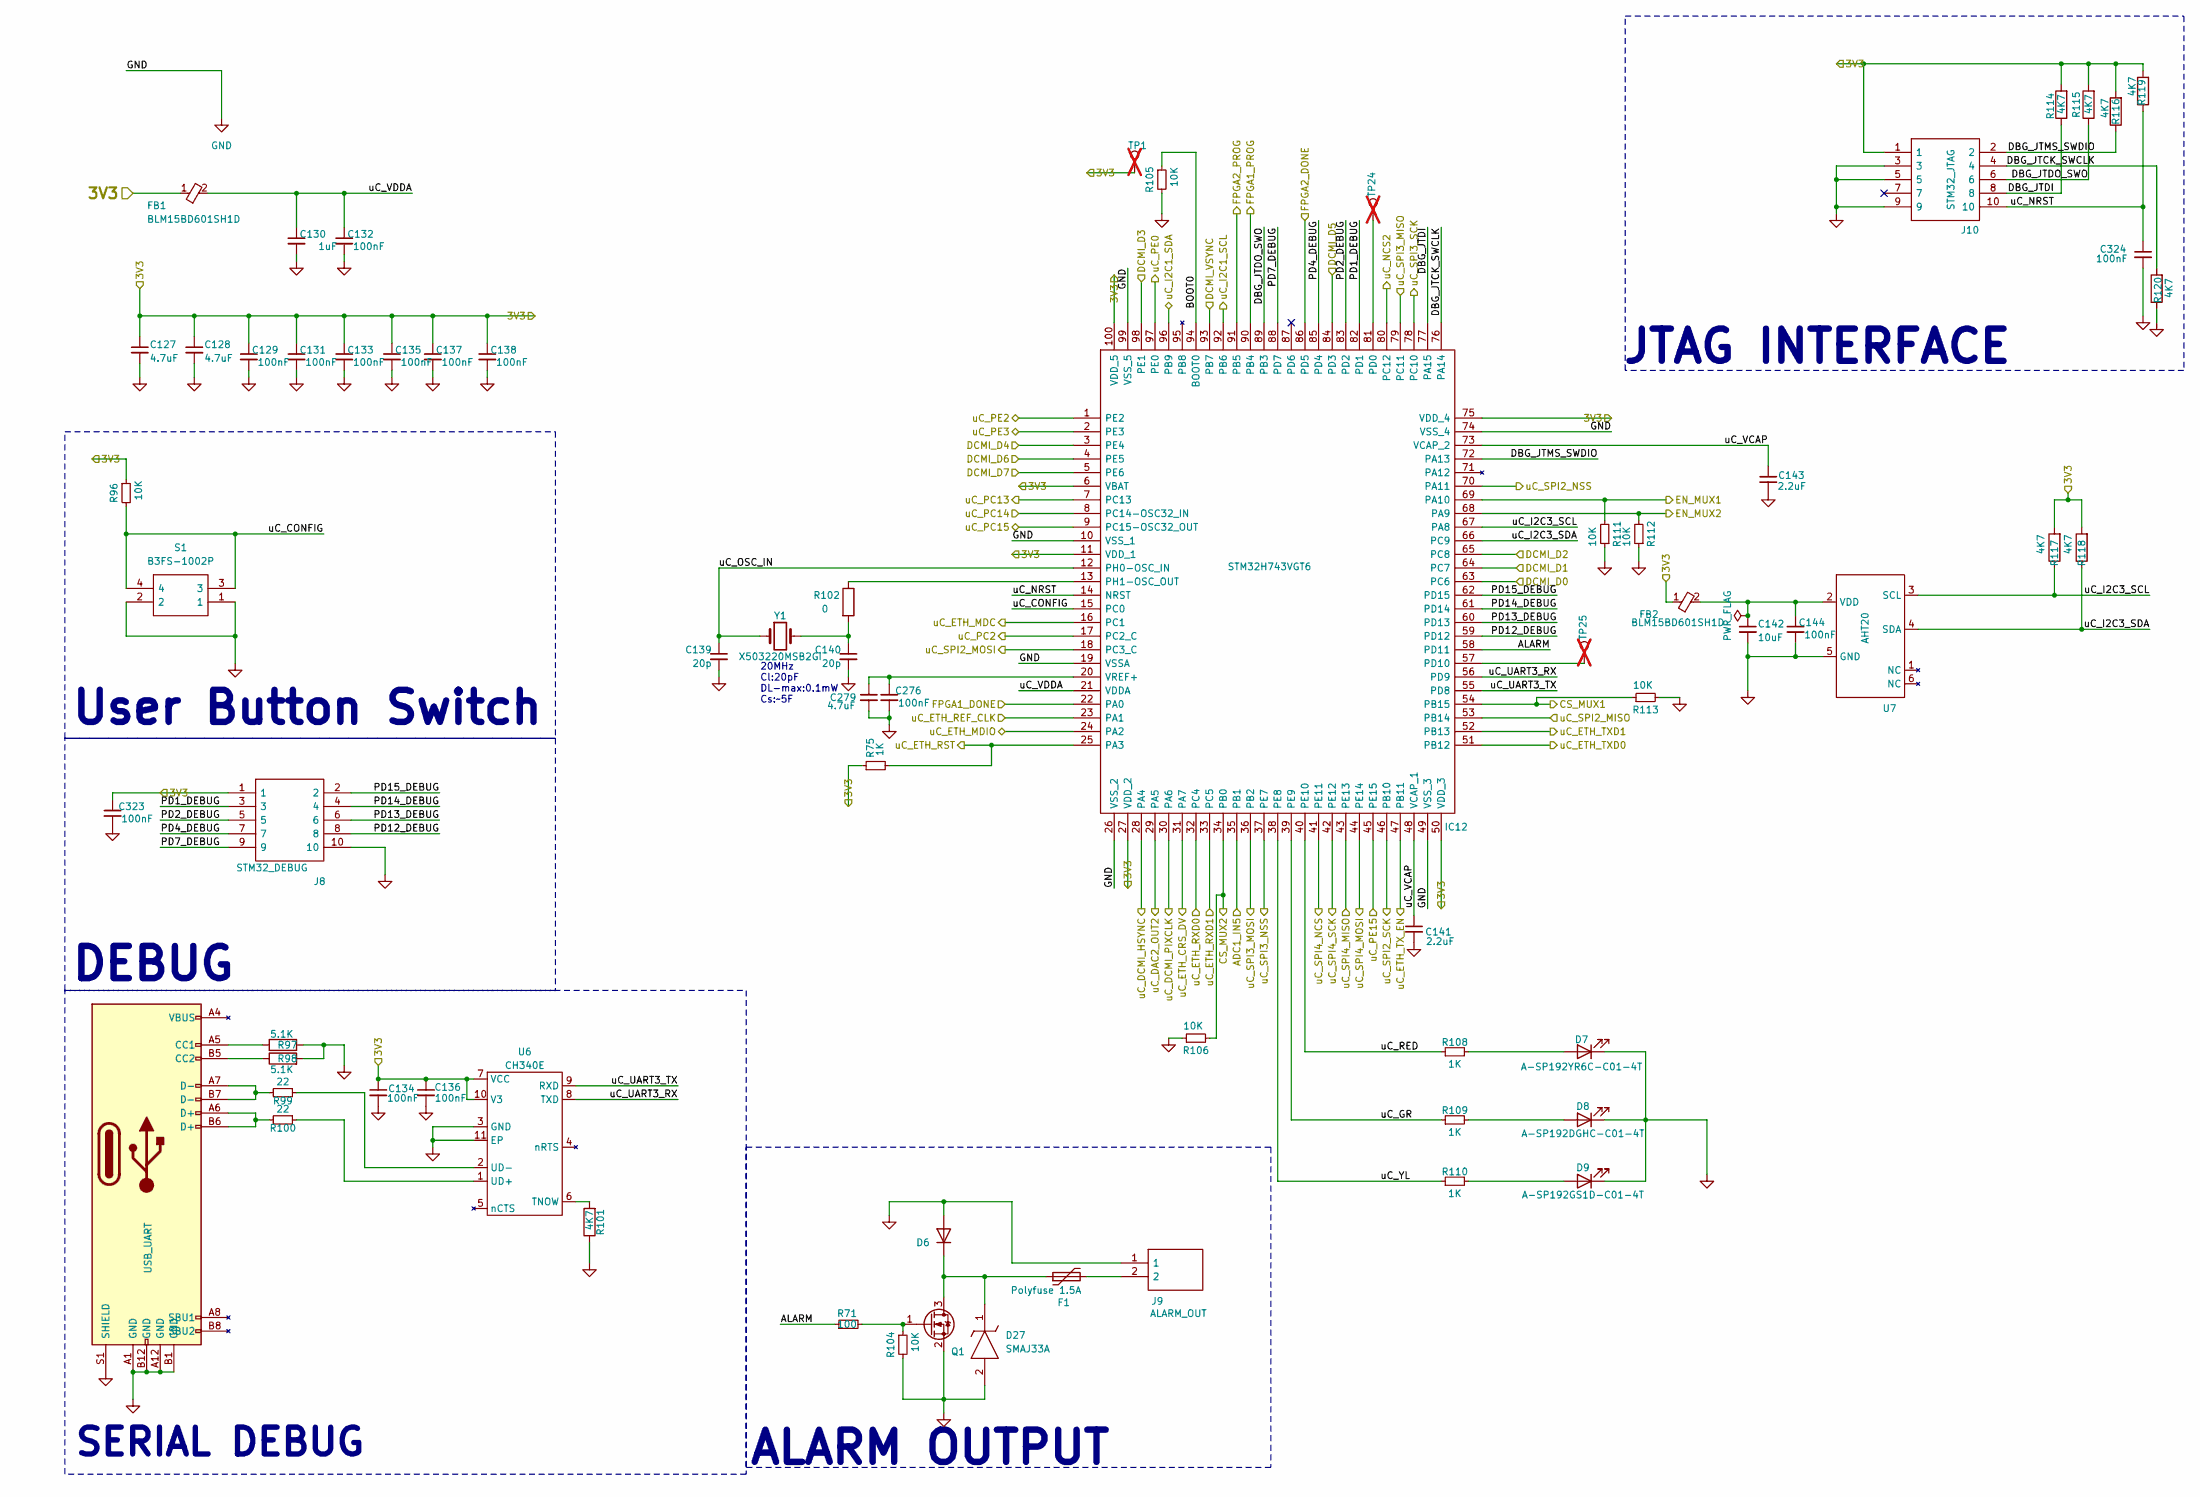
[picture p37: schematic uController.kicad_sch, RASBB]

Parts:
C127, C128, C279: 4.7uF; C_0603_1608Metric; Mfr. Part # GMK107BBJ475KA-T; LCSC Part # C7281848
C129, C131, C132, C133, C134, C135, C136, C137, C138, C144, C276, C323, C324: 100nF; C_0402_1005Metric; Mfr. Part # 0402B104K500CT; LCSC Part # C152814
C130: 1uF; C_0402_1005Metric; Mfr. Part # 0402X105M160CT; LCSC Part # C3889771
C139, C140: 20p; C_0402_1005Metric; Mfr. Part # 0402N200J500CT; LCSC Part # C123468
C141, C143: 2.2uF; C_0402_1005Metric; Mfr. Part # 0402X225M160CT; LCSC Part # C3905586
C142: 10uF; C_0402_1005Metric; Mfr. Part # 0402X106M100CT; LCSC Part # C2992625
D6: S210_R1_00001; D_SMB; Mfr. Part # S210_R1_00001; LCSC Part # C391676
D7: A-SP192YR6C-C01-4T; LED_0603_1608Metric; Mfr. Part # A-SP192YR6C-C01-4T; LCSC Part # C5355433
D8: A-SP192DGHC-C01-4T; LED_0603_1608Metric; Mfr. Part # A-SP192DGHC-C01-4T; LCSC Part # C19171301
D9: A-SP192GS1D-C01-4T; LED_0603_1608Metric; Mfr. Part # A-SP192GS1D-C01-4T; LCSC Part # C5355434
D27: SMAJ33A; DIOM5026X229N; Mouser Part Number 576-SMAJ33A
F1: Polyfuse 1.5A; BSMD1812; Mfr. Part # BSMD1812-150-33V; LCSC Part # C883154
FB1, FB2: BLM15BD601SH1D; NFZ15SG152SN10B; Mfr. Part # BLM15BD601SH1D; LCSC Part # C710334
IC12: STM32H743VGT6; QFP50P1600X1600X160-100N; Mfr. Part # STM32H743VGT6; LCSC Part # C730183
J7: USB_UART; USB_C_Receptacle_Palconn_UTC16-G; Mfr. Part # TYPE-C 16PIN 2MD(073); LCSC Part # C2765186
J8: STM32_DEBUG; PinHeader_2x05_P1.27mm_Vertical_SMD; Mfr. Part # ZX-PZ1.27-2-5PWZ; LCSC Part # C41370773
J9: ALARM_OUT; SHDRRA2W80P0X350_1X2_1050X920X750P; Mfr. Part # KF2EDGR-3.5-2P; LCSC Part # C441171
J10: STM32_JTAG; PinHeader_2x05_P1.27mm_Vertical_SMD; Mfr. Part # ZX-PZ1.27-2-5PWZ; LCSC Part # C41370773
Q1: DMN6075S; SOT-23; Mfr. Part # DMN6075S; LCSC Part # C5122015
R71: 100; R_0402_1005Metric; Mfr. Part # WR04X1000FTL; LCSC Part # C163808
R75, R108, R109, R110: 1K; R_0402_1005Metric; Mfr. Part # MR04X1001FTL; LCSC Part # C327796
R96, R104, R105, R106, R111, R112, R113: 10K; R_0402_1005Metric; Mfr. Part # WR04X1002FTL; LCSC Part # C163810
R97, R98: 5.1K; R_0402_1005Metric; Mfr. Part # WR04X512JTL; LCSC Part # C384321
R99, R100: 22; R_0402_1005Metric; Mfr. Part # WR04X22R0FTL; LCSC Part # C163821
R101, R114, R115, R116, R117, R118, R119, R120: 4K7; R_0402_1005Metric; Mfr. Part # WR04X4701FTL; LCSC Part # C163826
R102: 0; R_0402_1005Metric; Mfr. Part # MR04X000PTL; LCSC Part # C396825
S1: B3FS-1002P; B3FS-1000P; Mfr. Part # B3FS-1002P; LCSC Part # C271750
TP1, TP24, TP25: TestPoint; TestPoint_Pad_D1.0mm; not fitted
U6: CH340E; MSOP-10-1EP_3x3mm_P0.5mm_EP1.68x1.88mm; Mfr. Part # CH340E; LCSC Part # C99652
U7: AHT20; Mfr. Part # AHT20; LCSC Part # C2757850
Y1: X503220MSB2GI; Mfr. Part # X503220MSB2GI; LCSC Part # C112566

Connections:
/Audio_IN-OUT/3V3: C127.1, C128.1, C129.1, C131.1, C133.1, C134.1, C135.1, C136.1, C137.1, C138.1, C323.1, FB1.1, FB2.1, IC12.6 (VBAT), IC12.11 (VDD_1), IC12.27 (VDD_2), IC12.50 (VDD_3), IC12.75 (VDD_4), IC12.100 (VDD_5), J8.1, J10.1, R75.1, R96.1, R114.2, R115.2, R116.2, R117.2, R118.2, R119.2, TP1.1 (1_1), U6.7 (VCC), U6.10 (V3); also elsewhere on the board
/Audio_IN-OUT/Audio_PTT: IC12.45 (PE15); also elsewhere on the board
/CS2_FLASH_uC: IC12.80 (PC12); also elsewhere on the board
/CS_FLASH_uC: IC12.41 (PE11); also elsewhere on the board
/Config-SPI FLASH/MUX_EN1: IC12.69 (PA10), R111.2; also elsewhere on the board
/Config-SPI FLASH/MUX_EN2: IC12.68 (PA9), R112.2; also elsewhere on the board
/Config-SPI FLASH/SWITCH_FLASH_1: IC12.54 (PB15), R113.1; also elsewhere on the board
/Config-SPI FLASH/SWITCH_FLASH_2: IC12.34 (PB0), R106.2; also elsewhere on the board
/Ethernet_uC/ETH_RESET: IC12.25 (PA3), R75.2; also elsewhere on the board
/Ethernet_uC/RMII_MDC: IC12.16 (PC1); also elsewhere on the board
/Ethernet_uC/RMII_MDIO: IC12.24 (PA2); also elsewhere on the board
/Ethernet_uC/RMII_TX_EN: IC12.47 (PB11); also elsewhere on the board
/FPGA1_RESET: IC12.97 (PE0); also elsewhere on the board
/FPGA2_RESET: IC12.17 (PC2_C); also elsewhere on the board
/FPGA-01/BANK0/FPGA1_DONE: IC12.22 (PA0); also elsewhere on the board
/FPGA-01/FPGA1_PROG: IC12.90 (PB4); also elsewhere on the board
/FPGA-02/BANK0/FPGA2_DONE: IC12.86 (PD5); also elsewhere on the board
/FPGA-02/F2_B14_P15: IC12.98 (PE1); also elsewhere on the board
/FPGA-02/F2_B14_R15: IC12.3 (PE4); also elsewhere on the board
/FPGA-02/F2_B14_R16: IC12.4 (PE5); also elsewhere on the board
/FPGA-02/F2_B14_T15: IC12.5 (PE6); also elsewhere on the board
/FPGA-02/F2_B14_T16: IC12.28 (PA4); also elsewhere on the board
/FPGA-02/F2_B14_U14: IC12.64 (PC7); also elsewhere on the board
/FPGA-02/F2_B14_U16: IC12.30 (PA6); also elsewhere on the board
/FPGA-02/F2_B14_V14: IC12.63 (PC6); also elsewhere on the board
/FPGA-02/F2_B14_V15: IC12.65 (PC8); also elsewhere on the board
/FPGA-02/F2_B14_V16: IC12.84 (PD3); also elsewhere on the board
/FPGA-02/F2_B14_V17: IC12.93 (PB7); also elsewhere on the board
/FPGA-02/FPGA2_PROG: IC12.91 (PB5); also elsewhere on the board
/PCIE/PCIE_CS: IC12.37 (PE7); also elsewhere on the board
/PCIE/SMCLK: IC12.92 (PB6); also elsewhere on the board
/PCIE/SMDAT: IC12.96 (PB9); also elsewhere on the board
/RF_Transceiver/BUSY_LORA_G: IC12.8 (PC14-OSC32_IN); also elsewhere on the board
/RF_Transceiver/DIO1_LORA_G: IC12.1 (PE2); also elsewhere on the board
/RF_Transceiver/DIO2_LORA_G: IC12.2 (PE3); also elsewhere on the board
/RF_Transceiver/DIO3_LORA_G: IC12.9 (PC15-OSC32_OUT); also elsewhere on the board
/RF_Transceiver/NRST_LORA_G: IC12.7 (PC13); also elsewhere on the board
/RF_Transceiver/SPI_NSS_LORA_G: IC12.70 (PA11); also elsewhere on the board
/SO_FLASH_uC: IC12.43 (PE13); also elsewhere on the board
/uController/ADC1_IN5: IC12.35 (PB1); also elsewhere on the board
/uController/ALARM: IC12.58 (PD11), R71.1
/uController/BOOT0: IC12.94 (BOOT0), R105.1
/uController/DBG_JTCK_SWCLK: IC12.76 (PA14), J10.4, R120.2
/uController/DBG_JTDI: IC12.77 (PA15), J10.8, R114.1
/uController/DBG_JTDO_SWO: IC12.89 (PB3), J10.6, R115.1
/uController/DBG_JTMS_SWDIO: IC12.72 (PA13), J10.2, R116.1
/uController/PD1_DEBUG: IC12.82 (PD1), J8.3
/uController/PD2_DEBUG: IC12.83 (PD2), J8.5
/uController/PD4_DEBUG: IC12.85 (PD4), J8.7
/uController/PD7_DEBUG: IC12.88 (PD7), J8.9
/uController/PD12_DEBUG: IC12.59 (PD12), J8.8
/uController/PD13_DEBUG: IC12.60 (PD13), J8.6
/uController/PD14_DEBUG: IC12.61 (PD14), J8.4
/uController/PD15_DEBUG: IC12.62 (PD15), J8.2
/uController/uC_CONFIG: IC12.15 (PC0), R96.2, S1.3, S1.4
/uController/uC_DAC2_OUT2: IC12.29 (PA5); also elsewhere on the board
/uController/uC_ETH_CRS_DV: IC12.31 (PA7); also elsewhere on the board
/uController/uC_ETH_REF_CLK: IC12.23 (PA1); also elsewhere on the board
/uController/uC_ETH_RXD0: IC12.32 (PC4); also elsewhere on the board
/uController/uC_ETH_RXD1: IC12.33 (PC5); also elsewhere on the board
/uController/uC_ETH_TXD0: IC12.51 (PB12); also elsewhere on the board
/uController/uC_ETH_TXD1: IC12.52 (PB13); also elsewhere on the board
/uController/uC_GR: IC12.39 (PE9), R109.1
/uController/uC_I2C3_SCL: IC12.67 (PA8), R117.1, U7.3 (SCL)
/uController/uC_I2C3_SDA: IC12.66 (PC9), R118.1, U7.4 (SDA)
/uController/uC_NRST: C324.1, IC12.14 (NRST), J10.10, R119.1
/uController/uC_OSC_IN: C139.1, IC12.12 (PH0-OSC_IN), Y1.1
/uController/uC_RED: IC12.40 (PE10), R108.1
/uController/uC_SPI2_MISO: IC12.53 (PB14); also elsewhere on the board
/uController/uC_SPI2_MOSI: IC12.18 (PC3_C); also elsewhere on the board
/uController/uC_SPI2_SCK: IC12.46 (PB10); also elsewhere on the board
/uController/uC_SPI3_MISO: IC12.79 (PC11); also elsewhere on the board
/uController/uC_SPI3_MOSI: IC12.36 (PB2); also elsewhere on the board
/uController/uC_SPI3_SCK: IC12.78 (PC10); also elsewhere on the board
/uController/uC_SPI4_MOSI: IC12.44 (PE14); also elsewhere on the board
/uController/uC_SPI4_SCK: IC12.42 (PE12); also elsewhere on the board
/uController/uC_UART3_RX: IC12.56 (PD9), U6.8 (TXD)
/uController/uC_UART3_TX: IC12.55 (PD8), U6.9 (RXD)
/uController/uC_VCAP: C141.1, C143.1, IC12.48 (VCAP_1), IC12.73 (VCAP_2)
/uController/uC_VDDA: C130.1, C132.1, FB1.2, IC12.21 (VDDA)
/uController/uC_YL: IC12.38 (PE8), R110.1
GND: C127.2, C128.2, C129.2, C130.2, C131.2, C132.2, C133.2, C134.2, C135.2, C136.2, C137.2, C138.2, C139.2, C140.2, C141.2, C142.2, C143.2, C144.2, C276.2, C279.2, C323.2, C324.2, D6.2 (A), D7.1 (K), D8.1 (K), D9.1 (K), D27.2, IC12.10 (VSS_1), IC12.19 (VSSA), IC12.26 (VSS_2), IC12.49 (VSS_3), IC12.74 (VSS_4), IC12.99 (VSS_5), J7.A1 (GND), J7.A12 (GND), J7.B1 (GND), J7.B12 (GND), J7.S1 (SHIELD), J8.10, J9.1, J10.3, J10.5, J10.9, Q1.2 (S), R97.2, R98.2, R101.1, R104.2, R105.2, R106.1, R111.1, R112.1, R113.2, R120.1, S1.1, S1.2, U6.3 (GND), U6.11 (EP), U7.5 (GND); also elsewhere on the board
unnamed: C140.1, R102.2, Y1.2
unnamed: D6.1 (K), D27.1, F1.1, Q1.3 (D)
unnamed: D7.2 (A), R108.2
unnamed: D8.2 (A), R109.2
unnamed: D9.2 (A), R110.2
unnamed: F1.2, J9.2
unnamed: IC12.81 (PD0), TP24.1 (1_1)
unnamed: IC12.57 (PD10), TP25.1 (1_1)
unnamed: IC12.13 (PH1-OSC_OUT), R102.1
unnamed: C276.1, C279.1, IC12.20 (VREF+)
unnamed: J7.A5 (CC1), R97.1
unnamed: J7.B5 (CC2), R98.1
unnamed: J7.A6 (D+), J7.B6 (D+), R100.2
unnamed: J7.A7 (D-), J7.B7 (D-), R99.2
unnamed: Q1.1 (G), R71.2, R104.1
unnamed: R101.2, U6.6 (TNOW)
unnamed: R100.1, U6.1 (UD+)
unnamed: R99.1, U6.2 (UD-)
unnamed: C142.1, C144.1, FB2.2, U7.2 (VDD)

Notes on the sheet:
20MHz Cl:20pF DL-max:0.1mW Cs:~5F
DEBUG
SERIAL DEBUG
User Button Switch
ALARM OUTPUT
JTAG INTERFACE

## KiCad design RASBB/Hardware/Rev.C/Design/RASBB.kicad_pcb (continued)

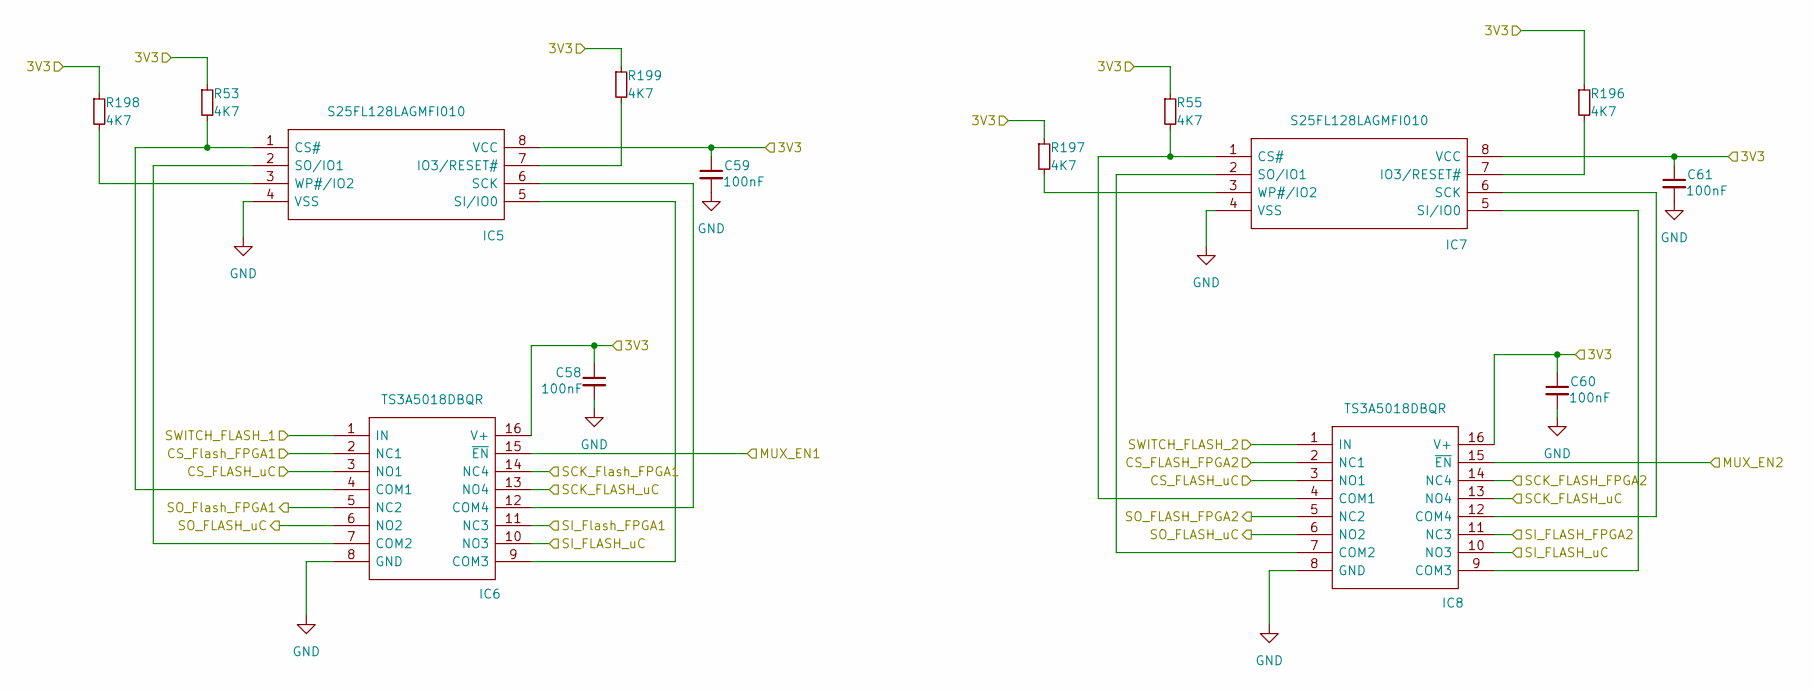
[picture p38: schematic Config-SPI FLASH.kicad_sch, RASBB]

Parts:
C58, C59, C60, C61: 100nF; C_0402_1005Metric; Mfr. Part # 0402B104K500CT; LCSC Part # C152814
IC5, IC7: S25FL128LAGMFI010; SOIC127P800X216-8N; Mfr. Part # S25FL128LAGMFI010; LCSC Part # C2959152
IC6, IC8: TS3A5018DBQR; SOP64P600X175-16N; Mfr. Part # TS3A5018DBQR; LCSC Part # C202285
R53, R55, R196, R197, R198, R199: 4K7; R_0402_1005Metric; Mfr. Part # WR04X4701FTL; LCSC Part # C163826

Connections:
/Audio_IN-OUT/3V3: C58.1, C59.1, C60.1, C61.1, IC5.8 (VCC), IC6.16 (V+), IC7.8 (VCC), IC8.16 (V+), R53.1, R55.1, R196.1, R197.1, R198.1, R199.1; also elsewhere on the board
/CS_FLASH_FPGA2: IC8.2 (NC1); also elsewhere on the board
/CS_FLASH_uC: IC6.3 (NO1), IC8.3 (NO1); also elsewhere on the board
/Config-SPI FLASH/CS_Flash_FPGA1: IC6.2 (NC1); also elsewhere on the board
/Config-SPI FLASH/MUX_EN1: IC6.15 (~EN); also elsewhere on the board
/Config-SPI FLASH/MUX_EN2: IC8.15 (~EN); also elsewhere on the board
/Config-SPI FLASH/SCK_FLASH_FPGA2: IC8.14 (NC4); also elsewhere on the board
/Config-SPI FLASH/SCK_Flash_FPGA1: IC6.14 (NC4); also elsewhere on the board
/Config-SPI FLASH/SI_FLASH_FPGA2: IC8.11 (NC3); also elsewhere on the board
/Config-SPI FLASH/SI_Flash_FPGA1: IC6.11 (NC3); also elsewhere on the board
/Config-SPI FLASH/SO_FLASH_FPGA2: IC8.5 (NC2); also elsewhere on the board
/Config-SPI FLASH/SO_Flash_FPGA1: IC6.5 (NC2); also elsewhere on the board
/Config-SPI FLASH/SWITCH_FLASH_1: IC6.1 (IN); also elsewhere on the board
/Config-SPI FLASH/SWITCH_FLASH_2: IC8.1 (IN); also elsewhere on the board
/SCK_FLASH_uC: IC6.13 (NO4), IC8.13 (NO4); also elsewhere on the board
/SI_FLASH_uC: IC6.10 (NO3), IC8.10 (NO3); also elsewhere on the board
/SO_FLASH_uC: IC6.6 (NO2), IC8.6 (NO2); also elsewhere on the board
GND: C58.2, C59.2, C60.2, C61.2, IC5.4 (VSS), IC6.8 (GND), IC7.4 (VSS), IC8.8 (GND); also elsewhere on the board
unnamed: IC5.1 (CS#), IC6.4 (COM1), R53.2
unnamed: IC5.7 (IO3/RESET#), R199.2
unnamed: IC5.6 (SCK), IC6.12 (COM4)
unnamed: IC5.5 (SI/IO0), IC6.9 (COM3)
unnamed: IC5.2 (SO/IO1), IC6.7 (COM2)
unnamed: IC5.3 (WP#/IO2), R198.2
unnamed: IC7.1 (CS#), IC8.4 (COM1), R55.2
unnamed: IC7.7 (IO3/RESET#), R196.2
unnamed: IC7.6 (SCK), IC8.12 (COM4)
unnamed: IC7.5 (SI/IO0), IC8.9 (COM3)
unnamed: IC7.2 (SO/IO1), IC8.7 (COM2)
unnamed: IC7.3 (WP#/IO2), R197.2

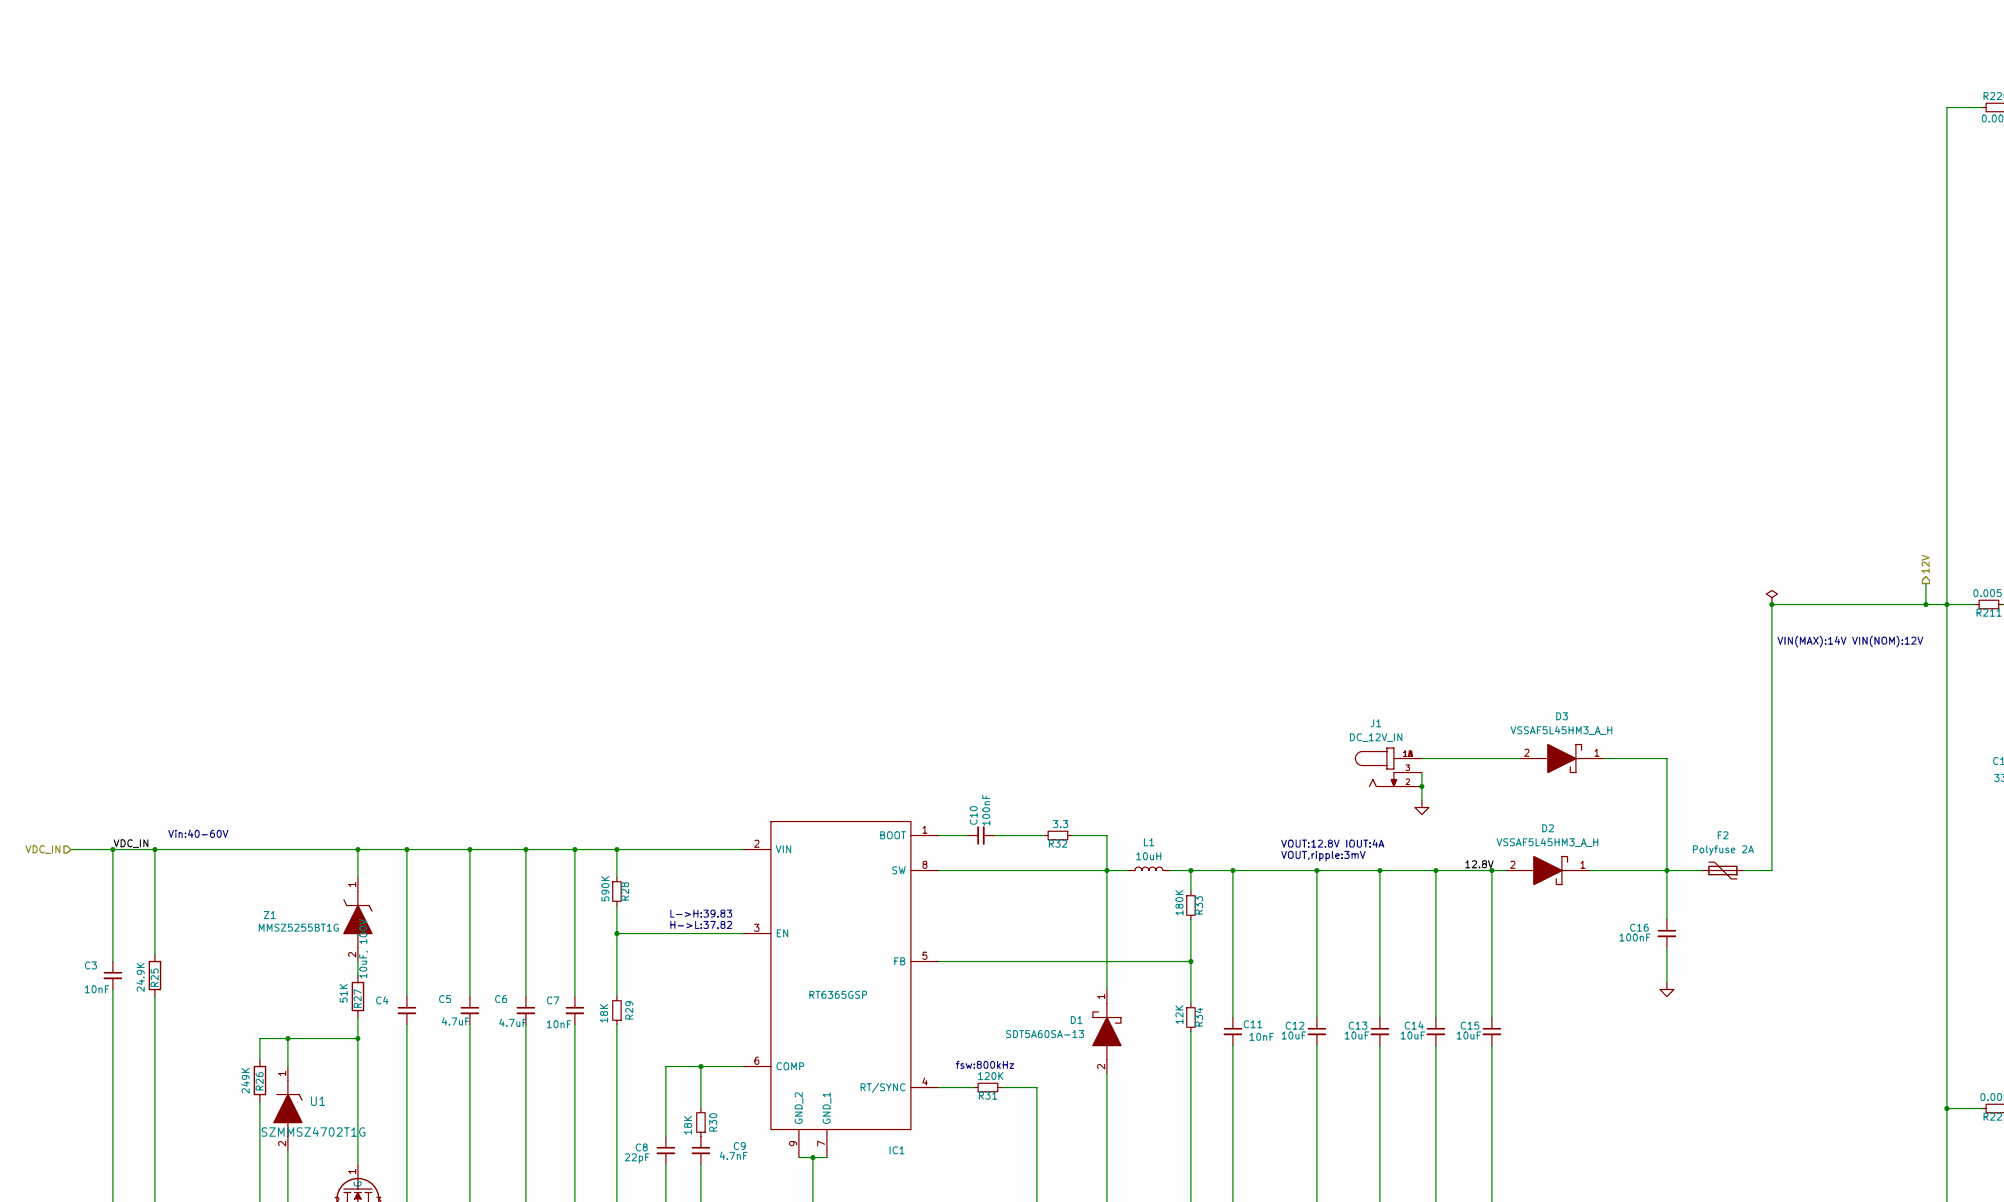
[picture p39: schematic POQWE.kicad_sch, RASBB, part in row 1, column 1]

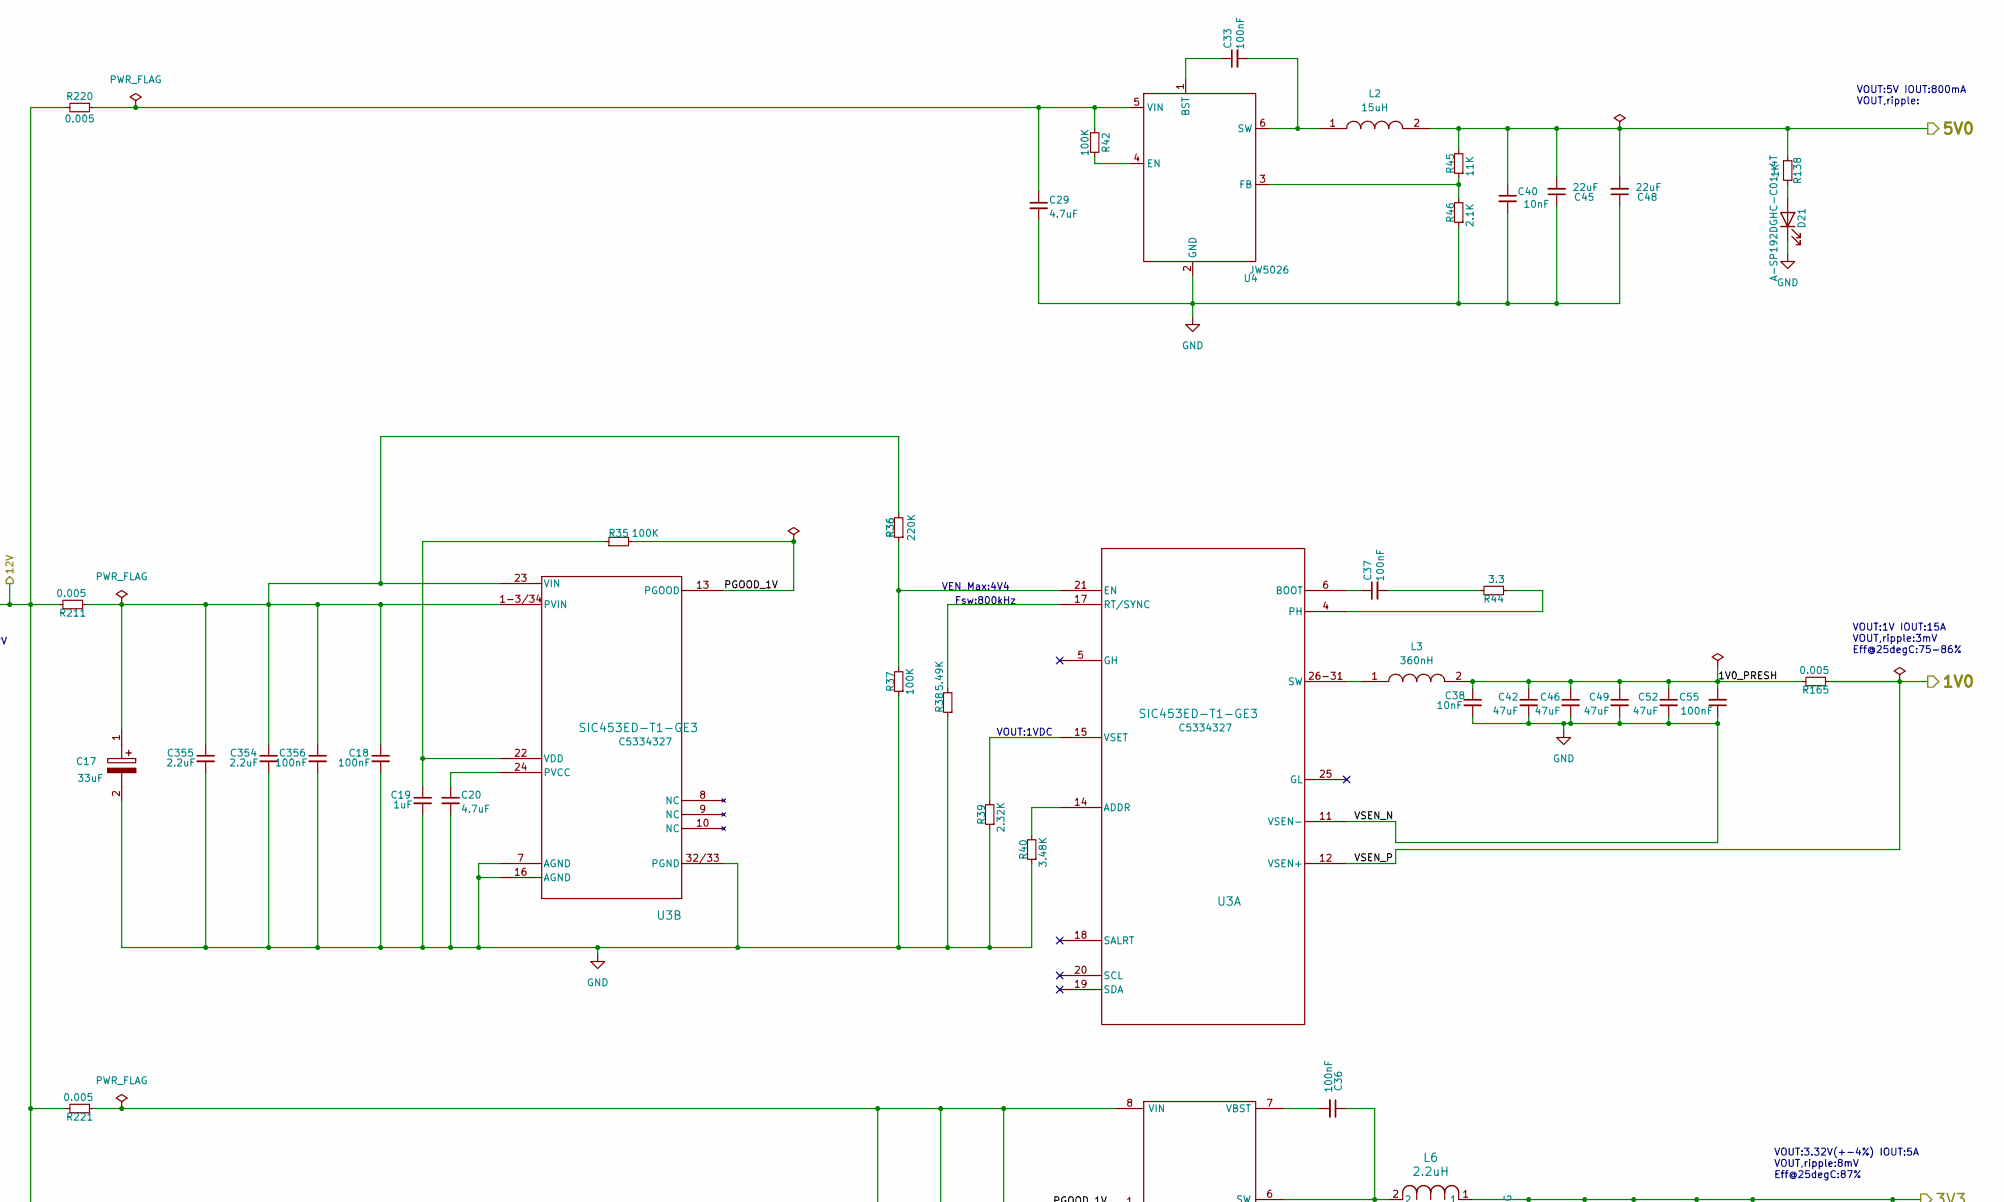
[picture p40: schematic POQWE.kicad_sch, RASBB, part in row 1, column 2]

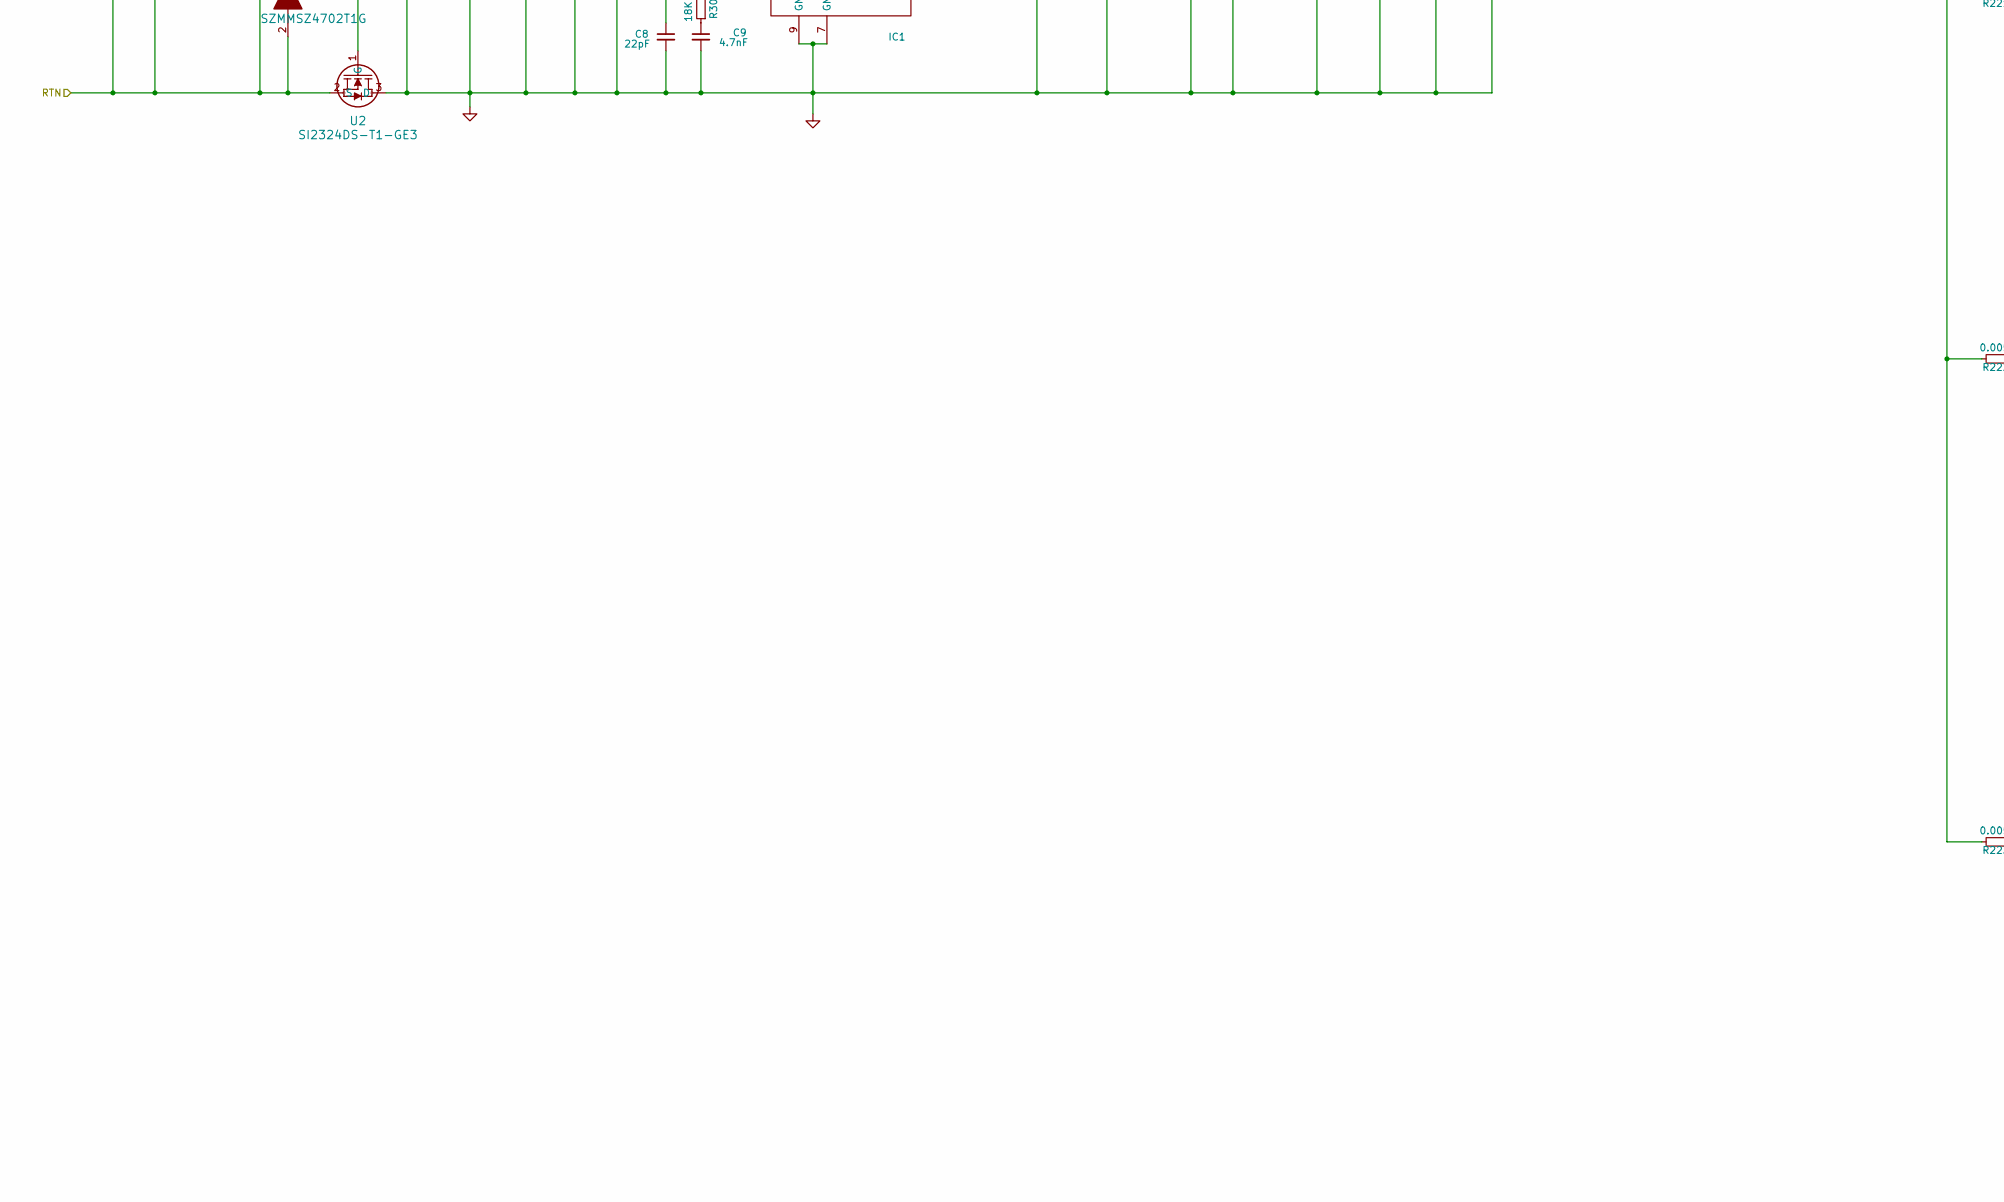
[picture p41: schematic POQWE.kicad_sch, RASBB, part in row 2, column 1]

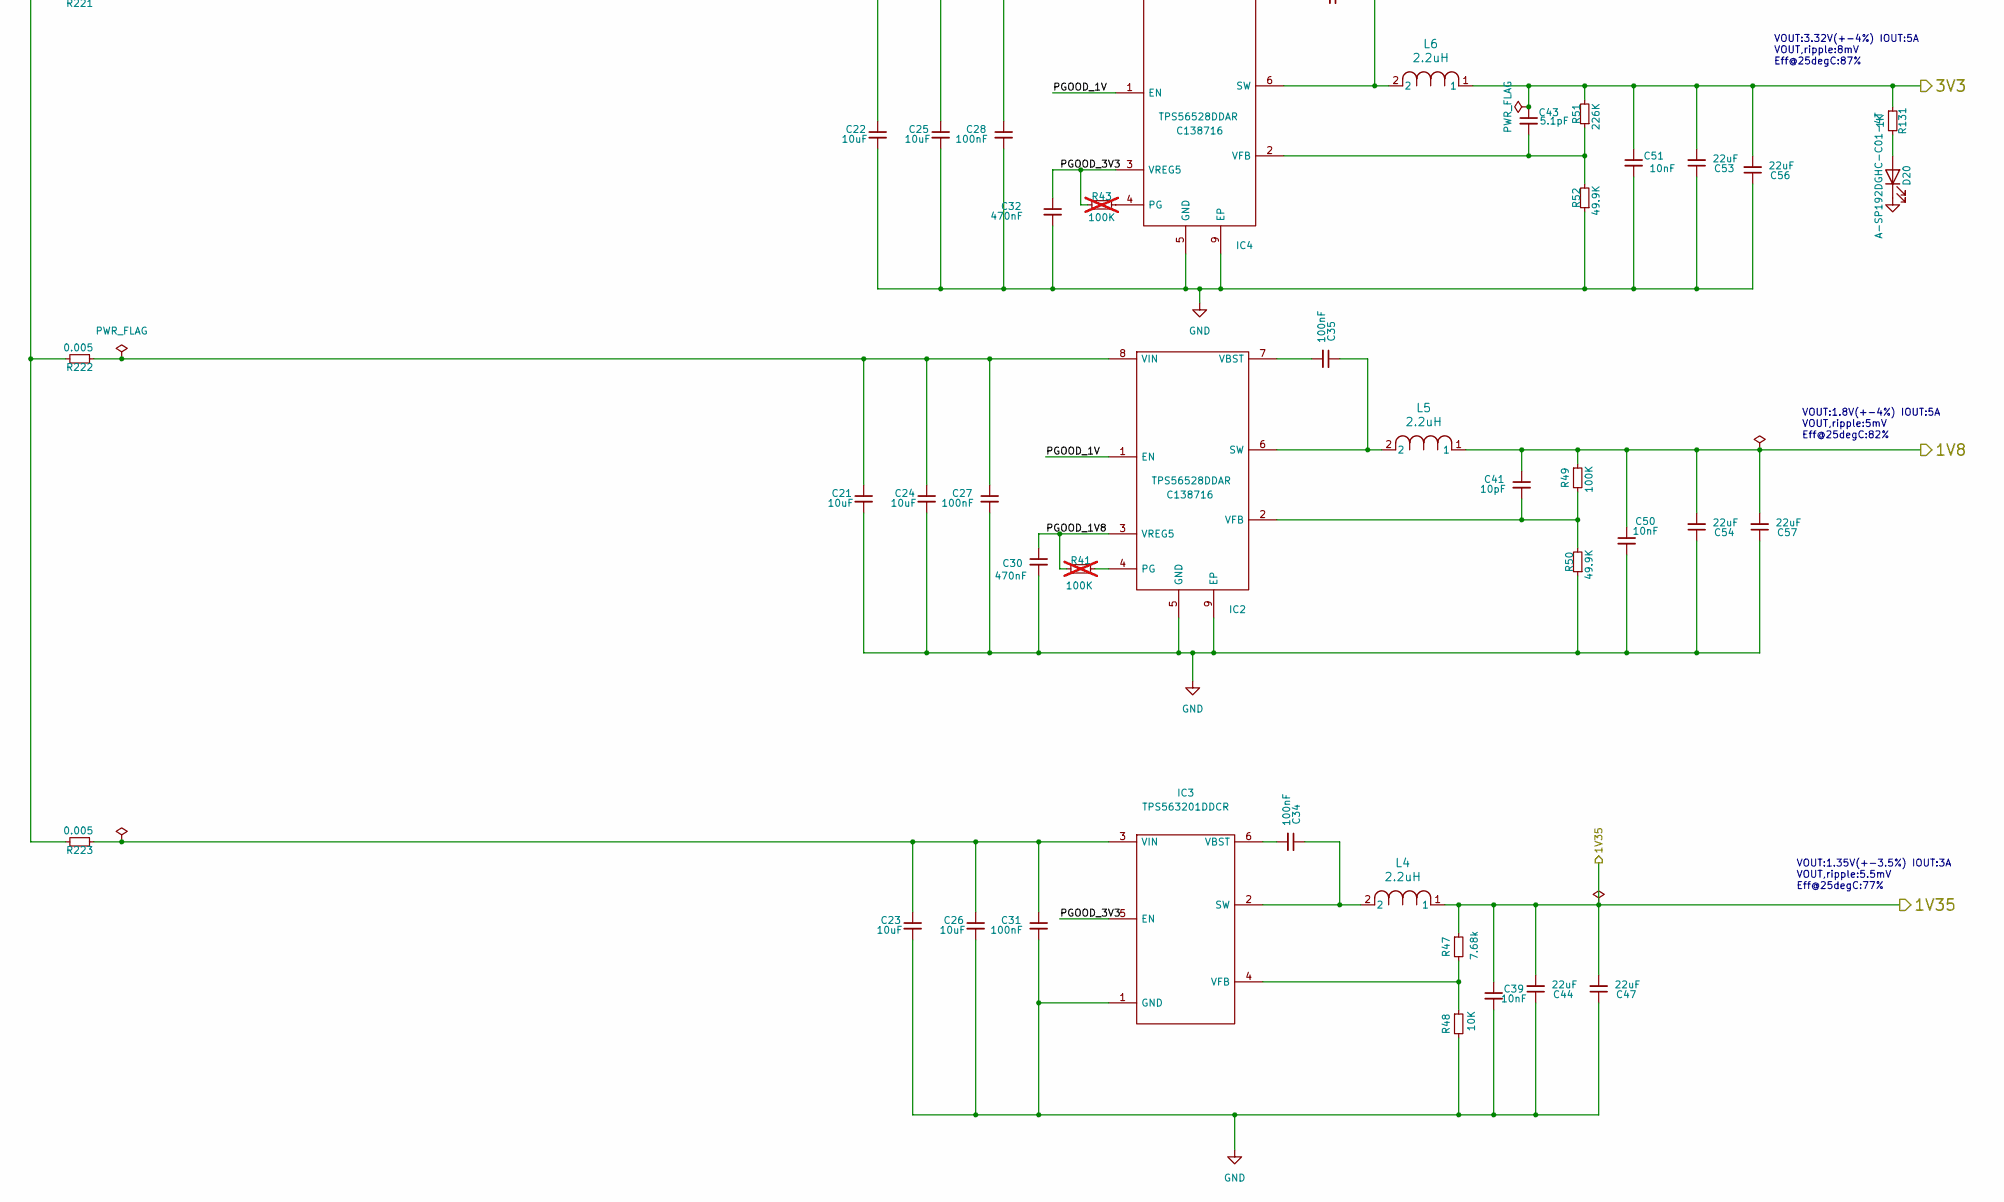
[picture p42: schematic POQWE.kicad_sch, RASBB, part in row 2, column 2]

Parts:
C3, C7: 10nF; C_0603_1608Metric; Mfr. Part # CGA0603X7R103K101JT; LCSC Part # C6119837
C4: 10uF, 100V; C_1206_3216Metric; Mfr. Part # C3216X6S2A106K160AC; LCSC Part # C6872041
C5, C6: 4.7uF; C_1206_3216Metric; Mfr. Part # GRM31CZ72A475KE11L; LCSC Part # C2997285
C8: 22pF; C_0402_1005Metric; Mfr. Part # CC0402JRNPO7BN220; LCSC Part # C2175872
C9: 4.7nF; C_0402_1005Metric; Mfr. Part # CC0402KRX7R6BB472; LCSC Part # C1852867
C10, C16, C18, C27, C28, C31, C33, C34, C35, C36, C37, C55, C356: 100nF; C_0402_1005Metric; Mfr. Part # 0402B104K500CT; LCSC Part # C152814
C11, C38, C39, C40, C50, C51: 10nF; C_0402_1005Metric; Mfr. Part # 0402B103K500CT; LCSC Part # C301927
C12, C13, C14, C15, C21, C22, C23, C24, C25, C26: 10uF; C_1206_3216Metric; Mfr. Part # CGA5L1X7R1H106KT0Y0N; LCSC Part # C531431
C17: 33uF; EEE0JA152UAP; Mfr. Part # EEE-FP1V330AP; LCSC Part # C178581
C19: 1uF; C_0402_1005Metric; Mfr. Part # 0402X105M160CT; LCSC Part # C3889771
C20: 4.7uF; C_0402_1005Metric; Mfr. Part # GRM155R61A475KEAAD; LCSC Part # C77004
C29: 4.7uF; C_0603_1608Metric; Mfr. Part # GMK107BBJ475KA-T; LCSC Part # C7281848
C30, C32: 470nF; C_0402_1005Metric; Mfr. Part # GRM155R71C474KE01D; LCSC Part # C471404
C41: 10pF; C_0402_1005Metric; Mfr. Part # C0402C100J4GAC7867; LCSC Part # C2182752
C42, C46, C49, C52: 47uF; C_0805_2012Metric; Mfr. Part # GRM21BR61A476ME15L; LCSC Part # C124129
C43: 5.1pF; C_0402_1005Metric; Mfr. Part # GRM1555C1E5R1CA01D; LCSC Part # C3855079
C44, C45, C47, C48, C53, C54, C56, C57: 22uF; C_0603_1608Metric; Mfr. Part # 0603YD226MAT2A; LCSC Part # C6776252
C354, C355: 2.2uF; C_0805_2012Metric; Mfr. Part # 0805B225K500CT; LCSC Part # C2918681
D1: SDT5A60SA-13; SDT5A60SA13; Mfr. Part # SDT5A60SA-13; LCSC Part # C3024223
D2, D3: VSSAF5L45HM3_A_H; SODFL5226X100N; Mfr. Part # VSSAF5L45HM3_A/H; LCSC Part # C6000165
D20, D21: A-SP192DGHC-C01-4T; LED_0603_1608Metric; Mfr. Part # A-SP192DGHC-C01-4T; LCSC Part # C19171301
F2: Polyfuse 2A; BSMD1812; Mfr. Part # BSMD1812-200-30V; LCSC Part # C960026
IC1: RT6365GSP; SOIC127P600X175-9N; Mfr. Part # RT6365GSP; LCSC Part # C3024482
IC2, IC4: TPS56528DDAR; SOIC127P600X170-9N; Mfr. Part # TPS56528DDAR; LCSC Part # C138716
IC3: TPS563201DDCR; SOT95P280X110-6N; Mfr. Part # TPS563201DDCR; LCSC Part # C116592
J1: DC_12V_IN; CUI_PJ-002AH-SMT-TR; Mfr. Part # PJ-002AH-SMT-TR; LCSC Part # C22434687
L1: 10uH; 0630CDMCDDS-100MC; Mfr. Part # 0630CDMCDDS-100MC; LCSC Part # C2595948
L2: 15uH; SMDRS6028-150N; Mfr. Part # SMDRS6028-150N; LCSC Part # C163563
L3: 360nH; INDPM109103X400N; Mfr. Part # IHLP4040DZERR36M01; LCSC Part # C845083
L4, L5, L6: 2.2uH; IND_IHLP-2525CZ_VIS; Mfr. Part # IHLP2525EZER2R2M01; LCSC Part # C845037
R25: 24.9K; R_1206_3216Metric; Mfr. Part # WR12X2492FTL; LCSC Part # C171074
R26: 249K; R_0805_2012Metric; Mfr. Part # WR08X2493FTL; LCSC Part # C170853
R27: 51K; R_0603_1608Metric; Mfr. Part # WR06X5102FTL; LCSC Part # C163933
R28: 590K; R_0402_1005Metric; Mfr. Part # WR04X5903FTL; LCSC Part # C172103
R29, R30: 18K; R_0402_1005Metric; Mfr. Part # WR04X1802FTL; LCSC Part # C168206
R31: 120K; R_0402_1005Metric; Mfr. Part # RC0402JR-07120KL; LCSC Part # C137924
R32, R44: 3.3; R_0402_1005Metric; Mfr. Part # CRCW04023R30FKEDC; LCSC Part # C4170964
R33: 180K; R_0402_1005Metric; Mfr. Part # WR04X1803FTL; LCSC Part # C168207
R34: 12K; R_0402_1005Metric; Mfr. Part # SR04X1202FTL; LCSC Part # C2991361
R35, R37, R42, R49: 100K; R_0402_1005Metric; Mfr. Part # RC0402FR-07100KL; LCSC Part # C60491
R36: 220K; R_0402_1005Metric; Mfr. Part # 0402WGF2203TCE; LCSC Part # C25767
R38: 5.49K; R_0402_1005Metric; Mfr. Part # CRCW04025K49FKED; LCSC Part # C2092200
R39: 2.32K; R_0402_1005Metric; Mfr. Part # CRCW04022K32FKED; LCSC Part # C2091739
R40: 3.48K; R_0402_1005Metric; Mfr. Part # CRCW04023K48FKED; LCSC Part # C4336043
R41, R43: 100K; R_0402_1005Metric; Mfr. Part # RC0402FR-07100KL; LCSC Part # C60491; not fitted
R45: 11K; R_0402_1005Metric; Mfr. Part # WR04X113JTL; LCSC Part # C172152
R46: 2.1K; R_0402_1005Metric; Mfr. Part # WR04X2101FTL; LCSC Part # C170256
R47: 7.68k; R_0402_1005Metric; Mfr. Part # WR04X7681FTL; LCSC Part # C334733
R48: 10K; R_0402_1005Metric; Mfr. Part # WR04X1002FTL; LCSC Part # C163810
R50, R52: 49.9K; R_0402_1005Metric; Mfr. Part # CRCW040249K9FKED; LCSC Part # C350874
R51: 226K; R_0402_1005Metric; Mfr. Part # CRCW0402226KFKED; LCSC Part # C2076623
R131, R138: 1K; R_0402_1005Metric; Mfr. Part # MR04X1001FTL; LCSC Part # C327796
R165: 0.005; R_2512_6332Metric; Mfr. Part # FRM252WJR005TN; LCSC Part # C7467241
R211, R220, R221, R222, R223: 0.005; R_2512_6332Metric; Mfr. Part # FRM252WJR005TN; LCSC Part # C7419996
U1: SZMMSZ4702T1G; SOD-123_ONS; Mfr. Part # SZMMSZ4702T1G; LCSC Part # C463904
U2: SI2324DS-T1-GE3; SOT_4DS-T1-GE3_VIS; Mfr. Part # SI2324DS-T1-GE3; LCSC Part # C190351
U3: SIC453ED-T1-GE3; POWERPAK_MLP34-57_VIS; Mfr. Part # SIC453ED-T1-GE3; LCSC Part # C5334327
U4: JW5026; SOT-23-6; Mfr. Part # JW5026; LCSC Part # C185109
Z1: MMSZ5255BT1G; SOD3716X135N; Mfr. Part # MMSZ5255BT1G; LCSC Part # C242284

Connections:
/Audio_IN-OUT/3V3: C43.1, C51.1, C53.2, C56.2, L6.1, R51.2, R131.1; also elsewhere on the board
/Audio_IN-OUT/5V0: C40.1, C45.2, C48.2, L2.2, R45.2, R138.1; also elsewhere on the board
/DDR3-01/VCCO_DDR3: C39.1, C44.2, C47.2, L4.1, R47.1; also elsewhere on the board
/FPGA-01/1V8: C41.1, C50.1, C54.2, C57.2, L5.1, R49.1; also elsewhere on the board
/PCIE/12V: F2.1, R211.2, R220.2, R221.2, R222.2, R223.2; also elsewhere on the board
/POWER/1V0_PRESH: C38.1, C42.1, C46.1, C49.1, C52.1, C55.2, L3.2, R165.2
/POWER/12.8V: C11.1, C12.1, C13.1, C14.1, C15.1, D2.2, L1.2, R33.1
/POWER/PGOOD_1V: IC2.1 (EN), IC4.1 (EN), R35.2, U3.13 (PGOOD)
/POWER/PGOOD_1V8: C30.1, IC2.3 (VREG5), R41.1
/POWER/PGOOD_3V3: C32.1, IC3.5 (EN), IC4.3 (VREG5), R43.1
/POWER/VSEN_P: R165.1, U3.12 (VSEN+); also elsewhere on the board
/VDC_IN: C3.1, C4.1, C5.1, C6.1, C7.1, IC1.2 (VIN), R25.2, R28.1, Z1.1; also elsewhere on the board
/VSS_POE: C3.2, R25.1, R26.1, U1.2, U2.2 (S); also elsewhere on the board
GND: C4.2, C5.2, C6.2, C7.2, C8.2, C9.2, C11.2, C12.2, C13.2, C14.2, C15.2, C16.2, C17.2, C18.2, C19.2, C20.2, C21.2, C22.2, C23.2, C24.2, C25.2, C26.2, C27.2, C28.2, C29.2, C30.2, C31.2, C32.2, C38.2, C39.2, C40.2, C42.2, C44.1, C45.1, C46.2, C47.1, C48.1, C49.2, C50.2, C51.2, C52.2, C53.1, C54.1, C55.1, C56.1, C57.1, C354.2, C355.2, C356.2, D1.2, D20.1 (K), D21.1 (K), IC1.7 (GND_1), IC1.9 (GND_2), IC2.5 (GND), IC2.9 (EP), IC3.1 (GND), IC4.5 (GND), IC4.9 (EP), J1.2, J1.3, R29.1, R31.1, R34.2, R37.1, R38.1, R39.1, R40.1, R46.1, R48.2, R50.1, R52.1, U2.3 (D), U3.7 (AGND), U3.11 (VSEN-), U3.16 (AGND), U3.32/33 (PGND), U4.2 (GND); also elsewhere on the board
unnamed: C9.1, R30.1
unnamed: C10.2, R32.2
unnamed: C16.1, D2.1, D3.1, F2.2
unnamed: C37.2, R44.2
unnamed: D3.2, J1.1A, J1.1B
unnamed: D20.2 (A), R131.2
unnamed: D21.2 (A), R138.2
unnamed: C10.1, IC1.1 (BOOT)
unnamed: C8.1, IC1.6 (COMP), R30.2
unnamed: IC1.3 (EN), R28.2, R29.2
unnamed: IC1.5 (FB), R33.2, R34.1
unnamed: IC1.4 (RT/SYNC), R31.2
unnamed: D1.1, IC1.8 (SW), L1.1, R32.1
unnamed: IC2.4 (PG), R41.2
unnamed: C35.1, IC2.6 (SW), L5.2
unnamed: C35.2, IC2.7 (VBST)
unnamed: C41.2, IC2.2 (VFB), R49.2, R50.2
unnamed: C21.1, C24.1, C27.1, IC2.8 (VIN), R222.1
unnamed: C34.1, IC3.2 (SW), L4.2
unnamed: C34.2, IC3.6 (VBST)
unnamed: IC3.4 (VFB), R47.2, R48.1
unnamed: C23.1, C26.1, C31.1, IC3.3 (VIN), R223.1
unnamed: IC4.4 (PG), R43.2
unnamed: C36.1, IC4.6 (SW), L6.2
unnamed: C36.2, IC4.7 (VBST)
unnamed: C43.2, IC4.2 (VFB), R51.1, R52.2
unnamed: C22.1, C25.1, C28.1, IC4.8 (VIN), R221.1
unnamed: R27.2, Z1.2
unnamed: R26.2, R27.1, U1.1, U2.1 (G)
unnamed: R40.2, U3.14 (ADDR)
unnamed: C37.1, U3.6 (BOOT)
unnamed: R36.1, R37.2, U3.21 (EN)
unnamed: R44.1, U3.4 (PH)
unnamed: R38.2, U3.17 (RT/SYNC)
unnamed: L3.1, U3.26-31 (SW)
unnamed: R39.2, U3.15 (VSET)
unnamed: C20.1, U3.24 (PVCC)
unnamed: C17.1, C18.1, C354.1, C355.1, C356.1, R36.2, R211.1, U3.1-3/34 (PVIN), U3.23 (VIN)
unnamed: C19.1, R35.1, U3.22 (VDD)
unnamed: C33.1, U4.1 (BST)
unnamed: R42.2, U4.4 (EN)
unnamed: R45.1, R46.2, U4.3 (FB)
unnamed: C33.2, L2.1, U4.6 (SW)
unnamed: C29.1, R42.1, R220.1, U4.5 (VIN)

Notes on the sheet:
Fsw:800kHz
L->H:39.83 H->L:37.82
VIN(MAX):14V VIN(NOM):12V
VOUT:1.8V(+-4%) IOUT:5A VOUT,ripple:5mV Eff@25degC:82%
VOUT:12.8V IOUT:4A VOUT,ripple:3mV
VOUT:3.32V(+-4%) IOUT:5A VOUT,ripple:8mV Eff@25degC:87%
VOUT:5V IOUT:800mA VOUT,ripple:
VOUT:1VDC
Vin:40-60V
VOUT:1.35V(+-3.5%) IOUT:3A VOUT,ripple:5.5mV Eff@25degC:77%
fsw:800kHz
VEN_Max:4V4
VOUT:1V IOUT:15A VOUT,ripple:3mV Eff@25degC:75-86%

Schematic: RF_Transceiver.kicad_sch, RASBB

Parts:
C145, C149: 20p; C_0402_1005Metric; Mfr. Part # 0402N200J500CT; LCSC Part # C123468
C146, C147: 10uF; C_0402_1005Metric; Mfr. Part # 0402X106M100CT; LCSC Part # C2992625
C148, C152, C154: 100nF; C_0402_1005Metric; Mfr. Part # 0402B104K500CT; LCSC Part # C152814
C150, C151: 10nF; C_0402_1005Metric; Mfr. Part # 0402B103K500CT; LCSC Part # C301927
C153: 470nF; C_0402_1005Metric; Mfr. Part # GRM155R71C474KE01D; LCSC Part # C471404
C155: 0.8pF; C_0402_1005Metric; Mfr. Part # RF15N0R8B500CT; LCSC Part # C396870
C156, C158: 1.2pF; C_0402_1005Metric; Mfr. Part # 0402N1R2C500CT; LCSC Part # C301969
C157: 0.5pF; C_0402_1005Metric; Mfr. Part # RT15N0R5B500CT; LCSC Part # C2918554
C159: 100pF; C_0402_1005Metric; Mfr. Part # 0402N101G500CT; LCSC Part # C387967
FB3: BLM15BD601SH1D; NFZ15SG152SN10B; Mfr. Part # BLM15BD601SH1D; LCSC Part # C710334
IC13: SX1280IMLTRT; QFN50P400X400X100-25N-D; Mfr. Part # SX1280IMLTRT; LCSC Part # C125969
J11: LORA_ANT; U.FL_Hirose_U.FL-R-SMT-1_Vertical; Mfr. Part # CONUFL001-SMD-T or similar; LCSC Part # C22418213
L9: 3nH; L_0402_1005Metric; Mfr. Part # MHQ1005P3N0BT000; LCSC Part # C433005
L10: 2.5nH; L_0402_1005Metric; Mfr. Part # FHW0402UC2N5KST; LCSC Part # C317668
Y2: XC21M4-52.000-F10NNHPL; Mfr. Part # XC21M4-52.000-F10NNHPL; LCSC Part # C3034316

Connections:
/Audio_IN-OUT/3V3: FB3.1; also elsewhere on the board
/RF_Transceiver/BUSY_LORA_G: IC13.7 (BUSY); also elsewhere on the board
/RF_Transceiver/DIO1_LORA_G: IC13.8 (DIO1); also elsewhere on the board
/RF_Transceiver/DIO2_LORA_G: IC13.9 (DIO2); also elsewhere on the board
/RF_Transceiver/DIO3_LORA_G: IC13.10 (DIO3); also elsewhere on the board
/RF_Transceiver/LORA_VDDIO: C146.1, C147.1, C148.1, C152.1, C154.1, FB3.2, IC13.11 (VBAT_IO), IC13.15 (VBAT)
/RF_Transceiver/NRST_LORA_G: IC13.3 (NRESET); also elsewhere on the board
/RF_Transceiver/SPI_MISO_LORA_G: IC13.16 (MISO_TX); also elsewhere on the board
/RF_Transceiver/SPI_MOSI_LORA_G: IC13.17 (MOSI_RX); also elsewhere on the board
/RF_Transceiver/SPI_NSS_LORA_G: IC13.19 (NSS_CTS); also elsewhere on the board
/RF_Transceiver/SPI_SCK_LORA_G: IC13.18 (SCK_RTSN); also elsewhere on the board
GND: C145.2, C146.2, C147.2, C148.2, C149.2, C150.2, C151.2, C152.2, C153.2, C154.2, C155.2, C156.2, C158.2, IC13.5 (GND_1), IC13.13 (GND_2), IC13.20 (GND_3), IC13.21 (GND_4), IC13.23 (GND_5), IC13.24 (GND_6), IC13.25 (EP), J11.2 (Ext), Y2.2 (GND_1), Y2.4 (GND_2); also elsewhere on the board
unnamed: C156.1, C157.1, L9.2, L10.1
unnamed: C157.2, C158.1, C159.2, L10.2
unnamed: C150.1, C153.1, IC13.2 (VDD_IN), IC13.12 (DCC_FB)
unnamed: C155.1, IC13.22 (RFIO), L9.1
unnamed: C151.1, IC13.1 (VR_PA)
unnamed: C149.1, IC13.4 (XTA), Y2.3 (XTAL_2)
unnamed: C145.1, IC13.6 (XTB), Y2.1 (XTAL_1)
unnamed: C159.1, J11.1 (In)

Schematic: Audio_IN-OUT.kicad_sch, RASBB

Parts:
C160, C161, C166: 10uF; C_0603_1608Metric; Mfr. Part # 0603X106M250CT; LCSC Part # C4555498
C162: 47nF; C_0402_1005Metric; Mfr. Part # C0402C473J8RAC7867; LCSC Part # C2178375
C163: 100pF; C_0402_1005Metric; Mfr. Part # 0402N101G500CT; LCSC Part # C387967
C164, C353: 100nF; C_0402_1005Metric; Mfr. Part # 0402B104K500CT; LCSC Part # C152814
C165: UUD1A221MCL1GS; CAPAE660X800N; Mfr. Part # UUD1A221MCL1GS; LCSC Part # C445275
C167: 1uF; C_0402_1005Metric; Mfr. Part # 0402X105M160CT; LCSC Part # C3889771
J12: AUDIO; FC68128; Mfr. Part # HC-PJ-313E8-B-SMT; LCSC Part # C7501803
R67, R124: 10K; R_0402_1005Metric; Mfr. Part # WR04X1002FTL; LCSC Part # C163810
R121: 1.2K; R_0402_1005Metric; Mfr. Part # WR04X1201FTL; LCSC Part # C168197
R122: 10; R_0402_1005Metric; Mfr. Part # 0402WGF100JTCE; LCSC Part # C25077
R123: 51K; R_0603_1608Metric; Mfr. Part # WR06X5102FTL; LCSC Part # C163933
R125, R126: 100K; R_0402_1005Metric; Mfr. Part # RC0402FR-07100KL; LCSC Part # C60491
R127: 5.6K; R_0402_1005Metric; Mfr. Part # WR04X5601FTL; LCSC Part # C168239
U8: LM386; SOP-8_3.9x4.9mm_P1.27mm; Mfr. Part # LM386D; LCSC Part # C510560
U9: LM321; SOT-23-5; Mfr. Part # LM321-TR; LCSC Part # C280706

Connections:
/Audio_IN-OUT/3V3: C164.1, R67.2, R125.2, R127.1, U9.5 (V+); also elsewhere on the board
/Audio_IN-OUT/5V0: C353.1, U8.6 (V+); also elsewhere on the board
/Audio_IN-OUT/Audio_IN: C163.2, R123.2, U9.4; also elsewhere on the board
/Audio_IN-OUT/Audio_PTT: J12.4A (R1), J12.4B (R1), R67.1; also elsewhere on the board
/Audio_IN-OUT/LM386_INP: U8.3 (+); also elsewhere on the board
GND: C160.2, C162.2, C164.2, C353.2, J12.1A (S), J12.1B (S), R124.2, R126.1, U8.2 (-), U8.4 (GND), U9.2 (V-); also elsewhere on the board
unnamed: C161.1, U8.8 (GAIN)
unnamed: C161.2, R121.2
unnamed: C162.1, R122.1
unnamed: C165.1, R122.2, U8.5
unnamed: C165.2, J12.2A (T), J12.2B (T)
unnamed: C166.2, R124.1
unnamed: C167.2, J12.3A (R2), J12.3B (R2), R127.2
unnamed: R121.1, U8.1 (GAIN)
unnamed: C160.1, U8.7 (BYPASS)
unnamed: C167.1, R125.1, R126.2, U9.1 (+)
unnamed: C163.1, C166.1, R123.1, U9.3 (-)

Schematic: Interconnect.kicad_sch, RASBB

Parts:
C125, C256: 22uF; C_0603_1608Metric; Mfr. Part # 0603YD226MAT2A; LCSC Part # C6776252
J5: ICON; CON50_1X50_DUTB_HRS_HIR; Mfr. Part # FH12-50S-0.5SVA(54); LCSC Part # C597991
RN1, RN2, RN3, RN4, RN5, RN6, RN7, RN8, RN9, RN10: CAY10-330J4LF; CAY10-XXXJ4; Mouser Part Number 652-CAY10-330J4LF
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

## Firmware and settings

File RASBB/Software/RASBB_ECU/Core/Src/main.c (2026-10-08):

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
/* Includes ------------------------------------------------------------------*/
#include "main.h"
#include "cmsis_os.h"
#include "eth.h"
#include "rng.h"
#include "spi.h"
#include "usart.h"
#include "gpio.h"

/****************************************************************************
*                              INCLUDES
*****************************************************************************/
#include <stdio.h>

/* USER CODE END Includes */

/* USER CODE BEGIN PD */
/****************************************************************************
*                              DEFINES
*****************************************************************************/

/* USER CODE END PD */


void SystemClock_Config(void);
void MX_FREERTOS_Init(void);
int __write(int file, char *ptr, int len);
int __io_putchar(int ch);
int fputc(int ch, FILE *f);
/* USER CODE BEGIN 0 */

/****************************************************************************
*                              LOCAL FUNCTIONS
*****************************************************************************/

/****************************************************************************
* FUNC:
* PARAM:
* RET:
* DESC:
*****************************************************************************/
int __io_putchar(int ch)
{
    HAL_UART_Transmit(&huart3, (uint8_t *)&ch, 1, HAL_MAX_DELAY);
    return ch;
}

/****************************************************************************
* FUNC:
* PARAM:
* RET:
* DESC:
*****************************************************************************/
int __write(int file, char *ptr, int len)
{
	int DataIdx;

	for (DataIdx = 0; DataIdx < len; DataIdx++)
	{
		fputc(*ptr++, NULL);
	}
	return len;
}

/****************************************************************************
* FUNC:
* PARAM:
* RET:
* DESC:
*****************************************************************************/
int fputc(int ch, FILE *f)
{
  ITM_SendChar(ch);
  HAL_UART_Transmit(&huart3, (uint8_t *)&ch, 1, 0xFFFF);
  return(ch);
}

/****************************************************************************
* FUNC:
* PARAM:
* RET:
* DESC:		Configure the MPU attributes
*****************************************************************************/
static void MPU_Config(void)
{
  MPU_Region_InitTypeDef MPU_InitStruct;

  /* Disable the MPU */
  HAL_MPU_Disable();

  /* Configure the MPU as Strongly ordered for not defined regions */
  MPU_InitStruct.Enable = MPU_REGION_ENABLE;
  MPU_InitStruct.BaseAddress = 0x00;
  MPU_InitStruct.Size = MPU_REGION_SIZE_4GB;
  MPU_InitStruct.AccessPermission = MPU_REGION_NO_ACCESS;
  MPU_InitStruct.IsBufferable = MPU_ACCESS_NOT_BUFFERABLE;
  MPU_InitStruct.IsCacheable = MPU_ACCESS_NOT_CACHEABLE;
  MPU_InitStruct.IsShareable = MPU_ACCESS_SHAREABLE;
  MPU_InitStruct.Number = MPU_REGION_NUMBER0;
  MPU_InitStruct.TypeExtField = MPU_TEX_LEVEL0;
  MPU_InitStruct.SubRegionDisable = 0x87;
  MPU_InitStruct.DisableExec = MPU_INSTRUCTION_ACCESS_DISABLE;

  HAL_MPU_ConfigRegion(&MPU_InitStruct);

  /* Configure the MPU attributes as Device not cacheable
     for ETH DMA descriptors */
  MPU_InitStruct.Enable = MPU_REGION_ENABLE;
  MPU_InitStruct.BaseAddress = 0x30000000;
  MPU_InitStruct.Size = MPU_REGION_SIZE_1KB;
  MPU_InitStruct.AccessPermission = MPU_REGION_FULL_ACCESS;
  MPU_InitStruct.IsBufferable = MPU_ACCESS_BUFFERABLE;
  MPU_InitStruct.IsCacheable = MPU_ACCESS_NOT_CACHEABLE;
  MPU_InitStruct.IsShareable = MPU_ACCESS_NOT_SHAREABLE;
  MPU_InitStruct.Number = MPU_REGION_NUMBER1;
  MPU_InitStruct.TypeExtField = MPU_TEX_LEVEL0;
  MPU_InitStruct.SubRegionDisable = 0x00;
  MPU_InitStruct.DisableExec = MPU_INSTRUCTION_ACCESS_ENABLE;

  HAL_MPU_ConfigRegion(&MPU_InitStruct);

  /* Configure the MPU attributes as Normal Non Cacheable
     for LwIP RAM heap which contains the Tx buffers */
  MPU_InitStruct.Enable = MPU_REGION_ENABLE;
  MPU_InitStruct.BaseAddress = 0x30004000;
  MPU_InitStruct.Size = MPU_REGION_SIZE_16KB;
  MPU_InitStruct.AccessPermission = MPU_REGION_FULL_ACCESS;
  MPU_InitStruct.IsBufferable = MPU_ACCESS_NOT_BUFFERABLE;
  MPU_InitStruct.IsCacheable = MPU_ACCESS_NOT_CACHEABLE;
  MPU_InitStruct.IsShareable = MPU_ACCESS_SHAREABLE;
  MPU_InitStruct.Number = MPU_REGION_NUMBER2;
  MPU_InitStruct.TypeExtField = MPU_TEX_LEVEL1;
  MPU_InitStruct.SubRegionDisable = 0x00;
  MPU_InitStruct.DisableExec = MPU_INSTRUCTION_ACCESS_ENABLE;

  HAL_MPU_ConfigRegion(&MPU_InitStruct);

  /* Enable the MPU */
  HAL_MPU_Enable(MPU_PRIVILEGED_DEFAULT);
}


/* USER CODE END 0 */

/****************************************************************************
* FUNC:
* PARAM:
* RET:
* DESC:
*****************************************************************************/
int main(void)
{
  /* USER CODE BEGIN 1 */
  /* Configure the MPU attributes as Device memory for ETH DMA descriptors */
  MPU_Config();
  /* Enable D-Cache */
  //SCB_EnableDCache();

  /* USER CODE END 1 */

  /* MCU Configuration--------------------------------------------------------*/

  /* Reset of all peripherals, Initializes the Flash interface and the Systick. */
  HAL_Init();

  /* Configure the system clock */
  SystemClock_Config();

  /* Initialize all configured peripherals */
  MX_GPIO_Init();
  //MX_ETH_Init();
  MX_SPI3_Init();
  MX_USART3_UART_Init();
  MX_RNG_Init();
  /* USER CODE BEGIN 2 */
  printf("Firmware start\n");
  /* USER CODE END 2 */

  /* Call init function for freertos objects (in freertos.c) */
  MX_FREERTOS_Init();

  /* Start scheduler */
  osKernelStart();

  /* We should never get here as control is now taken by the scheduler */
  /* Infinite loop */
  /* USER CODE BEGIN WHILE */
  while (1)
  {
    /* USER CODE END WHILE */

    /* USER CODE BEGIN 3 */
  }
  /* USER CODE END 3 */
}

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
/**
  * @brief  Period elapsed callback in non blocking mode
  * @note   This function is called  when TIM1 interrupt took place, inside
  * HAL_TIM_IRQHandler(). It makes a direct call to HAL_IncTick() to increment
  * a global variable "uwTick" used as application time base.
  * @param  htim : TIM handle
  * @retval None
  */
/****************************************************************************
* FUNC:
* PARAM:
* RET:
* DESC:
*****************************************************************************/
void HAL_TIM_PeriodElapsedCallback(TIM_HandleTypeDef *htim)
{
  if (htim->Instance == TIM1) {
    HAL_IncTick();
  }
}

/**
  * @brief  This function is executed in case of error occurrence.
  * @retval None
  */
/****************************************************************************
* FUNC:
* PARAM:
* RET:
* DESC:
*****************************************************************************/
void Error_Handler(void)
{
  /* USER CODE BEGIN Error_Handler_Debug */
  /* User can add his own implementation to report the HAL error return state */
  __disable_irq();
  while (1)
  {
  }
  /* USER CODE END Error_Handler_Debug */
}

#ifdef  USE_FULL_ASSERT
/**
  * @brief  Reports the name of the source file and the source line number
  *         where the assert_param error has occurred.
  * @param  file: pointer to the source file name
  * @param  line: assert_param error line source number
  * @retval None
  */
void assert_failed(uint8_t *file, uint32_t line)
{
  /* USER CODE BEGIN 6 */
  /* User can add his own implementation to report the file name and line number,
     ex: printf("Wrong parameters value: file %s on line %d\r\n", file, line) */
  /* USER CODE END 6 */
}
#endif /* USE_FULL_ASSERT */

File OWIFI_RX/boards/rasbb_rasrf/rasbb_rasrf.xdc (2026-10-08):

##############################################################################
# Design Name: OWIFI_RX
# Module Name: rasbb_rasrf.xdc
# Project Name: Radio Access Sentinel
# Engineer: Tobias Weber
# Target Devices: Artix-7 XC7A100T (RASBB U10)
# Tool Versions: Vivado 2025.2
# Description:  RA-Sentinel is a WiFi activity and threat detection platform
#
# Additional Comments: https://github.com/Tobias-DG3YEV/RA-Sentinel
#
# This project was funded through the NGI0 Entrust Fund, a fund established
# by NLnet with financial support from the European Commission's
# Next Generation Internet programme, under the aegis of DG Communications
# Networks, Content and Technology under grant agreement No 101069594.
# https://nlnet.nl/project/RA-Sentinel/
#
# SPDX-FileCopyrightText: 2026 Tobias Weber
# SPDX-License-Identifier: GPL-3.0-only
#
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
# You should have received a copy of the GNU General Public License
# along with this program. If not, see
# <http://www.gnu.org/licenses/> for a copy.
##############################################################################
#############################################################################
# rasbb_rasrf.xdc - OWIFI_RX on RASBB + 1ch RASRF (MAX2831 + ADC3221).
#
# Derived from the hardware-proven RASM2400 constraint set (RASBB_common.xdc
# + pins_RASRF.xdc @c103c5e), with:
#   - the TMDS/HDMI and spectrum-display constraints removed (no video here)
#   - the BUFG pin path adjusted for the adc_frontend hierarchy (fe0/...)
#   - the STM32<->FPGA1 SPI pins added, derived from RASBB.kicad_pcb
#     (FPGA1_CLK=E9 via R1, FPGA1_MOSI=K17 via R2, FPGA1_MISO=K18 via R4;
#     chip select is the general-purpose line F1_B15_C15=C15 through IC11 -
#     a CONVENTION defined here, the STM32 firmware must use the matching
#     GPIO).
#
# Keep the golden rules: the ADC bit clock is a TRUE 120MHz clock (8.333ns -
# never constrain it at half rate, see RASM2400 "finding D1"), and every
# used LVDS pair is EXTERNALLY terminated with 100R (HR bank: DIFF_TERM
# inert at VCCO 1.8V, IN_TERM fights the ADC's common mode).
#############################################################################

############## bitstream / config ##################
set_property CFGBVS VCCO [current_design]
set_property CONFIG_VOLTAGE 3.3 [current_design]
set_property BITSTREAM.CONFIG.UNUSEDPIN PULLUP [current_design]
set_property BITSTREAM.CONFIG.SPI_BUSWIDTH 1 [current_design]
set_property CONFIG_MODE SPIx1 [current_design]
set_property BITSTREAM.CONFIG.CONFIGRATE 50 [current_design]

############## system clock / keys ##################
set_property PACKAGE_PIN E3 [get_ports SYS_clk]
set_property IOSTANDARD LVCMOS18 [get_ports SYS_clk]
create_clock -period 20.000 -name SYS_clk [get_ports SYS_clk]

set_property PACKAGE_PIN P14 [get_ports Key0]
set_property PACKAGE_PIN T15 [get_ports Key1]
set_property IOSTANDARD LVCMOS18 [get_ports Key0]
set_property IOSTANDARD LVCMOS18 [get_ports Key1]
set_property PULLTYPE PULLUP [get_ports Key0]
set_property PULLTYPE PULLUP [get_ports Key1]
set_disable_timing [get_ports Key0]
set_disable_timing [get_ports Key1]

############## ADC LVDS (RASRF pinout) ##################
# RASRF: bit clock on H1 (RASBB net RX3), frame clock on G4 (RX2) - swapped
# versus the BMC frontend. I data (DA0) on F1/E1 (RX5), Q data (DB0) on
# K2/K1 (RX1) = port ADC_chC; chB (H2/G2, RX4) is RASRF's unused DA1.
set_property PACKAGE_PIN H1 [get_ports ADC_dclk_P]
set_property PACKAGE_PIN G4 [get_ports ADC_fclk_P]
set_property PACKAGE_PIN F1 [get_ports ADC_chA_P]
set_property PACKAGE_PIN E1 [get_ports ADC_chA_N]
set_property PACKAGE_PIN H2 [get_ports ADC_chB_P]
set_property PACKAGE_PIN G2 [get_ports ADC_chB_N]
set_property PACKAGE_PIN K2 [get_ports ADC_chC_P]
set_property PACKAGE_PIN K1 [get_ports ADC_chC_N]

set_property IOSTANDARD DIFF_SSTL18_II [get_ports ADC_chA_P]
set_property IOSTANDARD DIFF_SSTL18_II [get_ports ADC_chB_P]
set_property IOSTANDARD DIFF_SSTL18_II [get_ports ADC_chC_P]
set_property IOSTANDARD DIFF_SSTL18_II [get_ports ADC_dclk_P]
set_property IOSTANDARD DIFF_SSTL18_II [get_ports ADC_fclk_P]

############## clocks ##################
# One-wire, 20MSPS: DCLK = 6 x fS = 120MHz true period, FCLK = fS = 20MHz.
create_clock -period 8.333 -name ADC_dclk_P -waveform {0.000 4.167} -add [get_ports ADC_dclk_P]
create_clock -period 8.333 -name lvds_dclk_buffered -waveform {0.000 4.167} [get_pins fe0/BUFG_lvds_dclk_1/O]

# ADC-side clocks derive from the frontend's oscillator, everything else from
# the RASBB 50MHz - different crystals, genuinely asynchronous.
set_clock_groups -asynchronous -group [get_clocks {ADC_dclk_P lvds_dclk_buffered}]

# DCLK is not on an MRCC/SRCC pair - relax the dedicated-route DRC for the
# IBUFDS->BUFG hop (IBUFDS_DIFF_OUT decomposes, match by substring).
set_property CLOCK_DEDICATED_ROUTE FALSE [get_nets -hierarchical -filter {NAME =~ "*lvds_irx0/IBUFDS_adc_dclk*"}]
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

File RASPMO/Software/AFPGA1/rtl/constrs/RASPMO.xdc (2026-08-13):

############## Target: RASBB onboard FPGA, XC7A100T-CSG324 ##################
#
# This is U10, the HDMI-driving FPGA (U11 is the other one). Pins verified on
# real Rev.A silicon by scope/trace - trust them over any netlist.

set_property CFGBVS VCCO [current_design]
set_property CONFIG_VOLTAGE 3.3 [current_design]
set_property BITSTREAM.CONFIG.UNUSEDPIN PULLUP [current_design]
set_property BITSTREAM.CONFIG.SPI_BUSWIDTH 1 [current_design]
set_property CONFIG_MODE SPIx1 [current_design]
set_property BITSTREAM.CONFIG.CONFIGRATE 50 [current_design]

############## SYS_clk - 50MHz oscillator, bank 35 @ 1.8V, ball E3 (MRCC) ####
set_property PACKAGE_PIN E3 [get_ports i_SYS_clk]
set_property IOSTANDARD LVCMOS18 [get_ports i_SYS_clk]
create_clock -period 20.000 -name SYS_clk -waveform {0.000 10.000} [get_ports i_SYS_clk]

############## ADC1 LVDS interface, bank 35 @ 1.8V ###########################
# ADC3424 one-wire, 20MSPS, low-speed DDR: 12 bits over 6 DCLK cycles on both
# phases -> DCLK = 6 x fS = 120MHz, FCLK = fS = 20MHz.
#
# _I and NOT _II. The ADC3424 wants external 100R termination and this board
# has it. _II adds Xilinx DCI on-die termination on top, and two termination
# networks fighting each other drag the signal under the receiver threshold -
# while still looking perfectly clean on a scope probe, which is high impedance
# and doesn't load the line the way DCI does. Don't "fix" this to _II.

set_property PACKAGE_PIN G4 [get_ports i_ADC_dclk_P]
set_property PACKAGE_PIN G3 [get_ports i_ADC_dclk_N]
set_property IOSTANDARD DIFF_SSTL18_I [get_ports i_ADC_dclk_P]

set_property PACKAGE_PIN H1 [get_ports i_ADC_fclk_P]
set_property PACKAGE_PIN G1 [get_ports i_ADC_fclk_N]
set_property IOSTANDARD DIFF_SSTL18_I [get_ports i_ADC_fclk_P]

set_property PACKAGE_PIN F1 [get_ports i_ADC_chA_P] ;# ADC1 channel A = I
set_property PACKAGE_PIN E1 [get_ports i_ADC_chA_N]
set_property IOSTANDARD DIFF_SSTL18_I [get_ports i_ADC_chA_P]

set_property PACKAGE_PIN H2 [get_ports i_ADC_chB_P] ;# ADC1 channel B = RX1 Q
set_property PACKAGE_PIN G2 [get_ports i_ADC_chB_N]
set_property IOSTANDARD DIFF_SSTL18_I [get_ports i_ADC_chB_P]

# ADC1 channels C/D = RX2 I/Q.
set_property PACKAGE_PIN K2 [get_ports i_ADC_chC_P] ;# ADC1 channel C = RX2 I
set_property PACKAGE_PIN K1 [get_ports i_ADC_chC_N]
set_property IOSTANDARD DIFF_SSTL18_I [get_ports i_ADC_chC_P]

set_property PACKAGE_PIN J3 [get_ports i_ADC_chD_P] ;# ADC1 channel D = RX2 Q
set_property PACKAGE_PIN J2 [get_ports i_ADC_chD_N]
set_property IOSTANDARD DIFF_SSTL18_I [get_ports i_ADC_chD_P]

############## ADC2 LVDS interface, bank 35 @ 1.8V ###########################
# Second ADC3424, RX3/RX4 baseband. Same electrical setup as ADC1.
#
# !! NO TERMINATION ON THE BASEBOARD !! Like every RX pair, each of these needs
# a hand-soldered 100R across it near U10, same as chA/chB got. Until then the
# lanes are garbage - harmless, the affected panes just show noise.
set_property PACKAGE_PIN E6 [get_ports i_ADC2_dclk_P]
set_property PACKAGE_PIN E5 [get_ports i_ADC2_dclk_N]
set_property IOSTANDARD DIFF_SSTL18_I [get_ports i_ADC2_dclk_P]

set_property PACKAGE_PIN B3 [get_ports i_ADC2_fclk_P]
set_property PACKAGE_PIN B2 [get_ports i_ADC2_fclk_N]
set_property IOSTANDARD DIFF_SSTL18_I [get_ports i_ADC2_fclk_P]

set_property PACKAGE_PIN A4 [get_ports i_ADC2_chA_P] ;# ADC2 channel A = RX3 I
set_property PACKAGE_PIN A3 [get_ports i_ADC2_chA_N]
set_property IOSTANDARD DIFF_SSTL18_I [get_ports i_ADC2_chA_P]

set_property PACKAGE_PIN C2 [get_ports i_ADC2_chB_P] ;# ADC2 channel B = RX3 Q
set_property PACKAGE_PIN C1 [get_ports i_ADC2_chB_N]
set_property IOSTANDARD DIFF_SSTL18_I [get_ports i_ADC2_chB_P]

set_property PACKAGE_PIN B1 [get_ports i_ADC2_chC_P] ;# ADC2 channel C = RX4 I
set_property PACKAGE_PIN A1 [get_ports i_ADC2_chC_N]
set_property IOSTANDARD DIFF_SSTL18_I [get_ports i_ADC2_chC_P]

set_property PACKAGE_PIN F4 [get_ports i_ADC2_chD_P] ;# ADC2 channel D = RX4 Q
set_property PACKAGE_PIN F3 [get_ports i_ADC2_chD_N]
set_property IOSTANDARD DIFF_SSTL18_I [get_ports i_ADC2_chD_P]

create_clock -period 8.333 -name ADC_dclk_P -waveform {0.000 4.167} -add [get_ports i_ADC_dclk_P]
create_clock -period 8.333 -name ADC2_dclk_P -waveform {0.000 4.167} -add [get_ports i_ADC2_dclk_P]

# FCLK deliberately gets NO create_clock - it never clocks anything, lvds_rx
# and adc_sequencer only ever sample it as data on DCLK-clocked flops. Declare
# it and Vivado invents a bogus inter-clock hold path against DCLK. It is fully
# constrained below by set_input_delay relative to DCLK instead.
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

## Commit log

2024-03-11 2.4GHz RF Front-End PCB Rev. A
    First check-in of the 2.GHz Radio Front-End Rev. A. This first version is regarded as a EVM, Evaluation Module which uses a dual PMOD interface to send the I+Q data via LVDS to a FPGA ve. board like 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
    [ADC3221.kicad_sch, MAX2831.kicad_sch, RA-Sentinel_Front-End_EVM_RevA.kicad_pcb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]
2024-05-15 Update README.md
    Add link to the FPGA board supplier.
2024-06-01 Renamed folder from WiFiADC to RFFE2400_PCB
    [ADC3221.kicad_sch, MAX2831.kicad_sch, RA-Sentinel_Front-End_EVM_RevA.kicad_pcb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]
2024-06-01 Added info for PCB design files, layout changes
2024-06-04 added firmware for the HKU, Houskeeping unit of the RFFE daughter board
2024-10-01 added owifi_rx (my implementation of openOFDM incl. SPI slave interface and DCMI meta data streaming master) and RASWECU (STM32H7xx firmware writing to the FPGA configuration registers and a DCMI sla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
2025-02-08 Added Revision A of RASBB board layout
    [RASBB-B_Adhesive.gbr, RASBB-B_Cu.gbr, RASBB-B_Mask.gbr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]
2025-02-08 Added KiCAD design files of RASBB Rev. A
    [Audio_IN-OUT.kicad_sch, BANK0.kicad_sch, BANK14-15.kicad_sch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]
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2025-02-16 Delete RASBB/PCB_Design directory
    deleted, will add the latest version
    [Audio_IN-OUT.kicad_sch, BANK0.kicad_sch, BANK14-15.kicad_sch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]
2025-02-16 Delete RASBB/Rev.A directory
    deleted/will add new one
    [RASBB-B_Adhesive.gbr, RASBB-B_Cu.gbr, RASBB-B_Mask.gbr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]
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2025-02-23 Added first Revision of the RASBB board.
    [Audio_IN-OUT.kicad_sch, BANK0.kicad_sch, BANK14-15.kicad_sch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]
2025-02-23 Added confrimed BOM of RASBB Rev.A received from the PCBA.
    [RASBB_BOM_RevA.xls]
2025-02-23 Added RASRF, the 2.4GHz wide band radio front-end for the RA-Sentinel project.
    [ADC3221.kicad_sch, MAX2831.kicad_sch, PCIe.kicad_sch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]
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2025-02-27 Changed hardware photo in README.md
    Changed the old photo of the QMTech FPGA board and PMOD Front-End PCB to the new designed hardware.
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2025-02-28 Corrected the RASRF_2400WB PCB design files. They where not the latest from Rev. A. sent to manufacturer.
    [PCIe.kicad_sch, RASRF.kicad_pcb, RASRF.kicad_sch]
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2025-04-06 RASBB Rev B
    Read Findings_RevA.md to track changes from Rev A to Rev B
2025-04-06 Added REvision B of the RASBB board
    [Audio_IN-OUT.kicad_sch, BANK0.kicad_sch, BANK14-15.kicad_sch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]
2025-04-09 Corrected the directory structure of RASBB/Rev.B.
    [Audio_IN-OUT.kicad_sch, BANK0.kicad_sch, BANK14-15.kicad_sch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]
2025-04-09 updated design files
    [Audio_IN-OUT.kicad_sch, BANK0.kicad_sch, BANK14-15.kicad_sch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]
2025-04-12 Added Test Results of the first bring-up of the Revision A board.
2025-04-13 Rev B
    Config Flash 2 modified, Termination added to LVDS lines
    [Audio_IN-OUT.kicad_sch, Config-SPI FLASH.kicad_sch, Ethernet_FPGA.kicad_sch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]
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2025-04-20 Added ECUTEST für STM32, Ethernet and SPI Connection towards FPGA1 and 2
    [ECHUTEST_CubeIDE Debug.cfg]
2025-07-12 Update Findings_RevA.md
    Added DDR3 RAm missing address line pin
2025-12-15 Added new Firmware project for RASBB ECU (STM32H743) containing UPNP and config webserver.
    [ECHUTEST_CubeIDE Debug.cfg]
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2026-05-23 Changed license to CERN Open Hardware Licence Version 2 - Strongly Reciprocal. Changed position of the logos on PCB.
    [RASANT2400.kicad_pcb]
2026-05-30 added license note on silkscreen removed older RASBB revision
    [RASANT2400-B_Cu.gbr, RASANT2400-B_Mask.gbr, RASANT2400-B_Paste.gbr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]
2026-05-30 Dublicated-Delete RASBB/Hardware/Rev.A/MfgData directory
    Production files under producation folder
    [RASBB-B_Adhesive.gbr, RASBB-B_Cu.gbr, RASBB-B_Mask.gbr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]
2026-05-31 RASBB Findings: Add shunt resistor and header for power measurement
    Added a shunt resistor and header for measuring power consumption at the PCIE connector.
2026-05-31 Updated RASANT PCB
    [RASANT2400-B_Cu.gbr, RASANT2400-B_Mask.gbr, RASANT2400-B_Paste.gbr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]
2026-05-31 Updated RASANT2400 PCB.
    [RASANT2400.kicad_pcb]
2026-06-14 Change PCB section to PCBA with new images
    Updated PCB section to PCBA and added images for top and bottom sides.
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2026-06-25 Udpated version Rev C with opeoinmg in the solder mask to allow soldering of SMA connectors.
    [RASANT2400-B_Cu.gbr, RASANT2400-B_Mask.gbr, RASANT2400-B_Paste.gbr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]
2026-06-30 Update README with RASANT2400 project information
    Added RASANT2400 antenna project details to README.
2026-07-21 Enhance FPGA internal reset button description
    Updated the description for the FPGA internal reset button to include connection details to the STM32.
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2026-07-23 Update findings in Findings_RevA.md
    Added findings related to ADC designators, pull-up resistors, and wiring suggestions for IC5/IC6.
2026-07-23 Fix numbering in findings for ADC designators
2026-07-24 FIrst commit fpr RASPMO - RA Sentinel Spectrum Monitor. Works with the 4Ch RASRF2400BMC board.
2026-07-25 Add RASBB Rev.C design files
    Ignore .history/ local-edit-history folders going forward.
    [1747981-1.stp, 691305140002.stp, Audio_IN-OUT.kicad_sch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]
2026-08-02 Add findings for HDMI phantom powering issue
2026-08-09 Enhance README with image and YouTube link
    Updated README to include an image and a YouTube link, and corrected text regarding ADC signal levels.
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2026-08-11 Replace two 4-channel ADCs with one 8-channel ADC
2026-08-12 Update findings for ADC and MAX2831 replacements
    Items 7 and 8 address structural issues in the Rev A signal chain that affect phase calibration. Changes include replacing two 4-channel ADCs with one 8-channel ADC and exchanging the MAX2831 for the MAX2837 for improved phase noise performance.
2026-08-13 Revert "Made the FFT really parallel, cleaned up the directory and file structure."
    This reverts commit 60c63c0380c5b4d484568c99e81d7dcc9cd0f640.
    [RASPMO.xdc]
2026-08-13 Revise findings for ADC and PLL component replacements
    Updated findings for ADC and PLL component changes to improve phase alignment and reduce noise.
2026-08-13 Update findings with signal improvement solutions
    Added details on improvements for signal amplitude and switching capabilities for MAX transceiver chip.
2026-08-18 Update Findings Rev A with new 5V wiring entry
    Added a new entry for wiring 5V from U4 to PCIe with shunt resistor details.
2026-09-29 REV.C production data
    [Audio_IN-OUT.kicad_sch, Config-SPI FLASH.kicad_sch, Ethernet_FPGA.kicad_sch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]
2026-10-01 OWIFI_RX: openFFT replaces xfft_v9 in the Vivado project, comparison document
    owifi.xpr: the xfft_v9 fileset and its two runs are gone; openFFT's rtl/*.v
    (sibling checkout, $PPRDIR/../../openFFT) and openofdm's new frame_stats.v
    are listed with the other receiver sources. No Xilinx IP is left in the
    receiver, only the board's Video_clk.
    doc/openFFT_vs_xfft.md: what the receiver asks of the FFT, the measured
    comparison for the core and for the whole receiver, how it was verified
    (bench against the IP's own netlist, 31-vector regression, WBMC build with
    timing met, confirmed on the air), and why the core is instantiated with
    the IP's 212-clock latency.
2026-10-08 - Input bearing based an amplitude and phase difference added. - Added IQ fingerprint forwarding (first 1024 IQ samples af a frame) over DFPGA UDP sender. IP is configureable through ECU web interfac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
    [STM32CubeIDE Debug (1).cfg, pinout.csv]

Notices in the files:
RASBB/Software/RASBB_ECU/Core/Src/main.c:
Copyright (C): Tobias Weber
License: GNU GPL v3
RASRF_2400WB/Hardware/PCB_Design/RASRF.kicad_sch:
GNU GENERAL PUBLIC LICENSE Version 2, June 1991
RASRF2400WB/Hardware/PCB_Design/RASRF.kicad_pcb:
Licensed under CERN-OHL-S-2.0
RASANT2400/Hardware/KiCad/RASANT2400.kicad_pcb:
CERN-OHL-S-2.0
